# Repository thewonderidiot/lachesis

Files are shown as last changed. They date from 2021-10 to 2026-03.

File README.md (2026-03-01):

# Project Lachesis: AGC Core Rope Memory Readers

This repository contains all of the design files for safe, portable Block I and Block II Apollo Guidance Computer (AGC) core rope memory readers. For a detailed explanation of how it all works, check out [CuriousMarc's video featuring this project](https://www.youtube.com/watch?v=hckwxq8rnr0).

Block 2 reader being used to dump the rope modules flown on Skylab-2
*Block 2 reader being used to dump the rope modules flown on Skylab-2 at the New Mexico Museum of Space History*

## Rope Safety Considerations

The rope readers are designed to be electrically and mechanically exactly identical to real AGCs from the point of view of the rope modules. Exact mechanical dimensions and interfacing circuits were copied from the original AGC engineering drawings, obtained from the National Archives. During bringup, all circuits are calibrated to the [original procurement specifications](https://github.com/thewonderidiot/lachesis/tree/main/docs). Connections to the rope modules are made using [replica Malco Mini-Wasp pins generously provided by Samtec](https://www.youtube.com/watch?v=ThOXgcOOA1M).

Additionally:
* A hotswap controller is used to switch all power being applied to the rope module. This controller monitors for overvoltage, undervoltage, and overcurrent, and will automatically cut power to the rope if limits are violated. The enable for this hotswap controller must be actively held high by the microcontroller in the FPGA for rope power to remain enabled.
* The microcontroller is configured with ~95ms watchdog timer. If the software gets stuck, the resulting watchdog reset will take all outputs low, thus cutting power to the rope.
* 250mA fuses have been added to the 450mA power filter circuits. These fuses are capable of withstanding the nominal 1-to-5-microsecond-long 450mA current pulses. However, if a driver gets stuck on for any reason, the associated fuse will blow within approximately 1 second. Calculations by thermal engineer friends suggest that, conservatively, a sustained 450mA on one of the drive wires would only be damaging to the rope module after 30 seconds.

## Block I Rework

The Sense & Driver Board requires a small amount of rework when used in the Block I configuration. While designing the board, I focused on getting Block II correct, while trying not to do anything that would outright prevent Block I compatibility. The only thing I didn't account for in the design is that from the perspective of the sense amplifiers, current on the sense lines actually flows in opposite directions between Block I and Block II. For Block II, the sense amplifiers pull the sense lines up to 14V, and a 128mA current sink is connected to the module select pin. Block I does not yet have this pin; instead, the sense lines were pulled *down* to 3V. Lacking a 3V rail capable of sinking the necessary current, the 128mA module select driver forms a perfectly suitable substitute. This can be accomplished by depopulating F9 and C11, and running a wire from pin A32 of the main connector to the + pad of C11.


## Rope Modules Archived

This is a non-exhaustive list of the rope modules that have been successfully read using the rope readers. Redundant reads of the same software from different physical modules are not listed.

<table>
  <tr>
    <th>Program</th>
    <th width=15%>Rope Part No.</th>
    <th>Source</th>
    <th width="50%">Notes</th>
  </tr>
  <tr>
    <td rowspan="4">Sunrise 69<br/>(Block I System Test)</td>
    <td>1003133-18</td>
    <td rowspan="2">Anonymous collector</td>
    <td rowspan="4">The 1003733-021 and 1003733-071 modules dumped both have one strand with a single bad diode, requiring parity correction.</td>
  </tr>
  <tr>
    <!--Sunrise 69-->
    <td>1003133-19</td>
    <!--Anonymous Collector-->
    <!--notes-->
  </tr>
  <tr>
    <!--Sunrise 69-->
    <td>1003733-021</td>
    <td>Larry McGlynn</td>
    <!--notes-->
  </tr> 
  <tr>
    <!--Sunrise 69-->
    <td>1003733-071</td>
    <td>Anonymous Collector</td>
    <!--notes-->
  </tr>
  <tr>
    <td rowspan="6">Corona 261<br/>(AS-202)</td>
    <td>1003733-171</td>
    <td rowspan="6">Jimmie Loocke</td>
    <td rowspan="6">All six modules were flown on AS-202. These modules contained a variety of failed or failing diodes, requiring parity correction for several strands. Notably, strands 21 and 23 each had 2 bad diodes, requiring the affected bits to be manually teased out by capturing waveforms of the cores flipping in both directions utilizing a differential probe. Additionally, 1003733-221 contained a broken core, resulting in the total loss of 8 words. Fortunately, these words turned out to be identical to the Apollo 4/6 software, Solarium 55.</td>
  </tr>
  <tr>
    <!--Corona 261-->
    <td>1003733-191</td>
    <!--Jimmie Loocke-->
    <!--notes-->
  </tr>
  <tr>
    <!--Corona 261-->
    <td>1003733-211</td>
    <!--Jimmie Loocke-->
    <!--notes-->
  </tr>
  <tr>
    <!--Corona 261-->
    <td>1003733-221</td>
    <!--Jimmie Loocke-->
    <!--notes-->
  </tr>
  <tr>
    <!--Corona 261-->
    <td>1003733-231</td>
    <!--Jimmie Loocke-->
    <!--notes-->
  </tr>
  <tr>
    <!--Corona 261-->
    <td>1003733-241</td>
    <!--Jimmie Loocke-->
    <!--notes-->
  </tr>
  <tr>
    <td rowspan="5">Sunspot ?<br/>(Early Apollo 1 release)</td>
    <td>1003733-251</td>
    <td rowspan="5">Dr. Nick Gessler</td>
    <td rowspan="5">Unfortunately, all modules have many failed diodes, precluding easy software recovery. Work to correct resulting errors is ongoing.</td>
  </tr>
  <tr>
    <!--Sunspot-->
    <td>1003733-261</td>
    <!--Dr. Nick Gessler-->
    <!--notes-->
  </tr>
  <tr>
    <!--Sunspot-->
    <td>1003733-281</td>
    <!--Dr. Nick Gessler-->
    <!--notes-->
  </tr>
  <tr>
    <!--Sunspot-->
    <td>1003733-291</td>
    <!--Dr. Nick Gessler-->
    <!--notes-->
  </tr>
  <tr>
    <!--Sunspot-->
    <td>1003733-311</td>
    <!--Dr. Nick Gessler-->
    <!--notes-->
  </tr>
  <tr>
    <td rowspan="5">Solarium 55<br/>(Apollo 4 and 6)</td>
    <td>1003733-461</td>
    <td rowspan="5">Jimmie Loocke</td>
    <td rowspan="5">All five modules were flown on Apollo 4.</td>
  </tr>
  <tr>
    <!--Solarium 55-->
    <td>1003733-471</td>
    <!--Jimmie Loocke-->
    <!--notes-->
  </tr>
  <tr>
    <!--Solarium 55-->
    <td>1003733-481</td>
    <!--Jimmie Loocke-->
    <!--notes-->
  </tr>
  <tr>
    <!--Solarium 55-->
    <td>1003733-511</td>
    <!--Jimmie Loocke-->
    <!--notes-->
  </tr>
  <tr>
    <!--Solarium 55-->
    <td>1003733-521</td>
    <!--Jimmie Loocke-->
    <!--notes-->
  </tr>
  <tr>
    <td>Aurora 85<br/>(Initial LM System Test)</td>
    <td>2003053-071</td>
    <td>Anonymous Collector</td>
    <td>Module B2 from Aurora 85. While module B1 of Aurora 88 is equivalent to Aurora 85, module B3 is not, so Aurora 85 has not yet been fully recovered.</td>
  </tr>
  <tr>
    <td rowspan="3">Aurora 88<br/>(Final LM System Test)</td>
    <td>2003972-011</td>
    <td rowspan="3">Steve Jurvetson</td>
    <td rowspan="3">Rope modules were installed in the guidance pallet flown on the F-8 in the Digital Fly-By-Wire program. The whereabouts of the actual DFBW modules are unknown.</td>
  </tr>
  <tr>
    <!--Aurora 88-->
    <td>2003972-091</td>
    <!--Steve Jurvetson-->
    <!--notes-->
  </tr>
  <tr>
    <!--Aurora 88-->
    <td>2003972-111</td>
    <!--Steve Jurvetson-->
    <!--notes-->
  </tr>
  <tr>
    <td>Sundial B<br/>(Initial CM System Test)</td>
    <td>2003053-151</td>
    <td>Anonymous Collector</td>
    <td>Module B2 from Sundial B. While module B1 of Sundial B is equivalent to Sundial D, module B3 is not, so Sundial B has not yet been fully recovered.</td>
  </tr>
  <tr>
    <td rowspan="2">Colossus 237<br/>(Apollo 8)</td>
    <td>2003972-541</td>
    <td rowspan="2">Anonymous Collector</td>
    <td rowspan="2">2003972-541 is marked "SCRAP UNIT" in red, but read without errors.</td>
  </tr>
  <tr>
    <!--Colossus 237-->
    <td>2003972-571</td>
    <!--Anonymous Collector-->
    <!--notes-->
  </tr>
  <tr>
    <td>Luminary 69<br/>(Apollo 10 LM)</td>
    <td>2003972-751</td>
    <td>Anonymous Collector</td>
    <td>First rope module successfully dumped.</td>
  </tr>
  <tr>
    <td rowspan="6">Comanche 67<br/>(Apollo 12 CM)</td>
    <td>2003972-1081</td>
    <td rowspan="6">Anonymous Collector</td>
    <td rowspan="6">Modules B1 through B4 were part of the flight spare set for Apollo 12. The high serial numbers for modules B5 and B6 suggest they were manufactured after the flight, for unknown reasons.</td>
  </tr>
  <tr>
    <!--Comanche 67-->
    <td>2003972-1091</td>
    <!--Anonymous Collector-->
    <!--notes-->
  </tr>
  <tr>
    <!--Comanche 67-->
    <td>2003972-1111</td>
    <!--Anonymous Collector-->
    <!--notes-->
  </tr>
  <tr>
    <!--Comanche 67-->
    <td>2003972-1121</td>
    <!--Anonymous Collector-->
    <!--notes-->
  </tr>
  <tr>
    <!--Comanche 67-->
    <td>2003972-1131</td>
    <!--Anonymous Collector-->
    <!--notes-->
  </tr>
  <tr>
    <!--Comanche 67-->
    <td>2003972-1141</td>
    <!--Anonymous Collector-->
    <!--notes-->
  </tr>
  <tr>
    <td>Comanche 72<br/>(Initial Apollo 13 CM release)</td>
    <td>2010802-021</td>
    <td>Anonymous Collector</td>
    <td>Module was initially slated fly on Apollo 13, but a bugfix in response to the Apollo 12 lightning strike requiring a re-release resulted in it remaining grounded.</td>
  </tr>
  <tr>
    <td>LM131 rev 1<br/>(Final Apollo 13 LM release)</td>
    <td>2010802-121</td>
    <td>Anonymous Collector</td>
    <td>Flight spare module. This is the only module different between LM131 rev 1 and Luminary 131 (for which scans of a program listing are available), so recovery of the software from this module resulted in the complete recovery of LM131 rev 1.</td>
  </tr>
  <tr>
    <td rowspan="6">Skylark 48<br/>(Skylab and ASTP CM)</td>
    <td>2010802-541</td>
    <td rowspan="6">New Mexico Museum of Space History</td>
    <td rowspan="6">All six modules were flown on the Skylab-2 mission, and possibly reflown on a later mission. Made possible by Chris Orwoll and Larry McGlynn.</td>
  </tr>
  <tr>
    <!--Skylark 48-->
    <td>2010802-551</td>
    <!--New Mexico Museum of Space History-->
    <!--notes-->
  </tr>
  <tr>
    <!--Skylark 48-->
    <td>2010802-561</td>
    <!--New Mexico Museum of Space History-->
    <!--notes-->
  </tr>
  <tr>
    <!--Skylark 48-->
    <td>2010802-571</td>
    <!--New Mexico Museum of Space History-->
    <!--notes-->
  </tr>
  <tr>
    <!--Skylark 48-->
    <td>2010802-581</td>
    <!--New Mexico Museum of Space History-->
    <!--notes-->
  </tr>
  <tr>
    <!--Skylark 48-->
    <td>2010802-591</td>
    <!--New Mexico Museum of Space History-->
    <!--notes-->
  </tr>
</table>

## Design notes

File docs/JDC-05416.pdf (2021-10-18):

INSTALLATION AND REMOVAL OF FIXED MEMORY MODULES AND FIXED MEMORY JUMPER MODULES - BLOCK ll AND EM

JDC 05418 REV. -LMH io, _i
INITIAL TDftft 27956 | D.S. Pel J_
SUBSYST[M | Co | ter | ASSY.
DESCIIIIPTION

Inatallation and removal of fixed memory rope and Jumper modul .. ln the oomputer

Rev. | TORR | ~AGES REVISED | A~~VAL | REFtRENCES | -
Let. Dot, | NO. | JDC | D. S. | MIT | NASA
A 9...!l&-68 36862 | 1 | - | EAU~ - ,
IMPOflTANT | . ' - I '
See below.
INT[fNAL A• required

TOOLS ANO
MATflltlAL 0-25 Inch pound tonJi• wrench. 6/32 Allen adapter.
IMPORTANT | .. | a. Alternati• on th• Jacki• •crew• tipt-
en them with a torque wrench one turn ea•
Refer to JDC 18100 for lubrication tnBtruo- | until they are la &o 19 lncb-pounda.
Uona prior to engaging any acrew or bolt | - Into header hellcotl lnaerta, and for belt- | REMOVAL | . coil insert cleaning tnstructtona after all
testing ba• been completed or prtor to | 4. Remove module• uatng the torque wnnch
apacecraft ln8tallat1on. | fttted with a 6/32¹¹ Allen adapter. Altenat.
eada modllle Jacld• 8Cr9W ao that modlu1, Sa
INSTALLATION | withdrawn •traicbt from oomputer.
- | - | • 1
NOTE: Fixed memory mod- | - ule to be operative must be | '
. installed ln pain or ropee • | -·, | •• 1
If one module la to be Wied
then a Jumper module must | - be used. Refer to table | '

page 2.

t. lupect the connector of the module for | l bent or broken plna. | , ' | . | . . | .. i I. Refer to the diagram dll the aecond page

of thi• JDC. luert the module ln the
computer. | ·- ·- --
V(Re,ICATION Wint •DL ft!QUIMO l!flOM UK | DATE 12 A Pl j8
'·· | . .,, | ! f

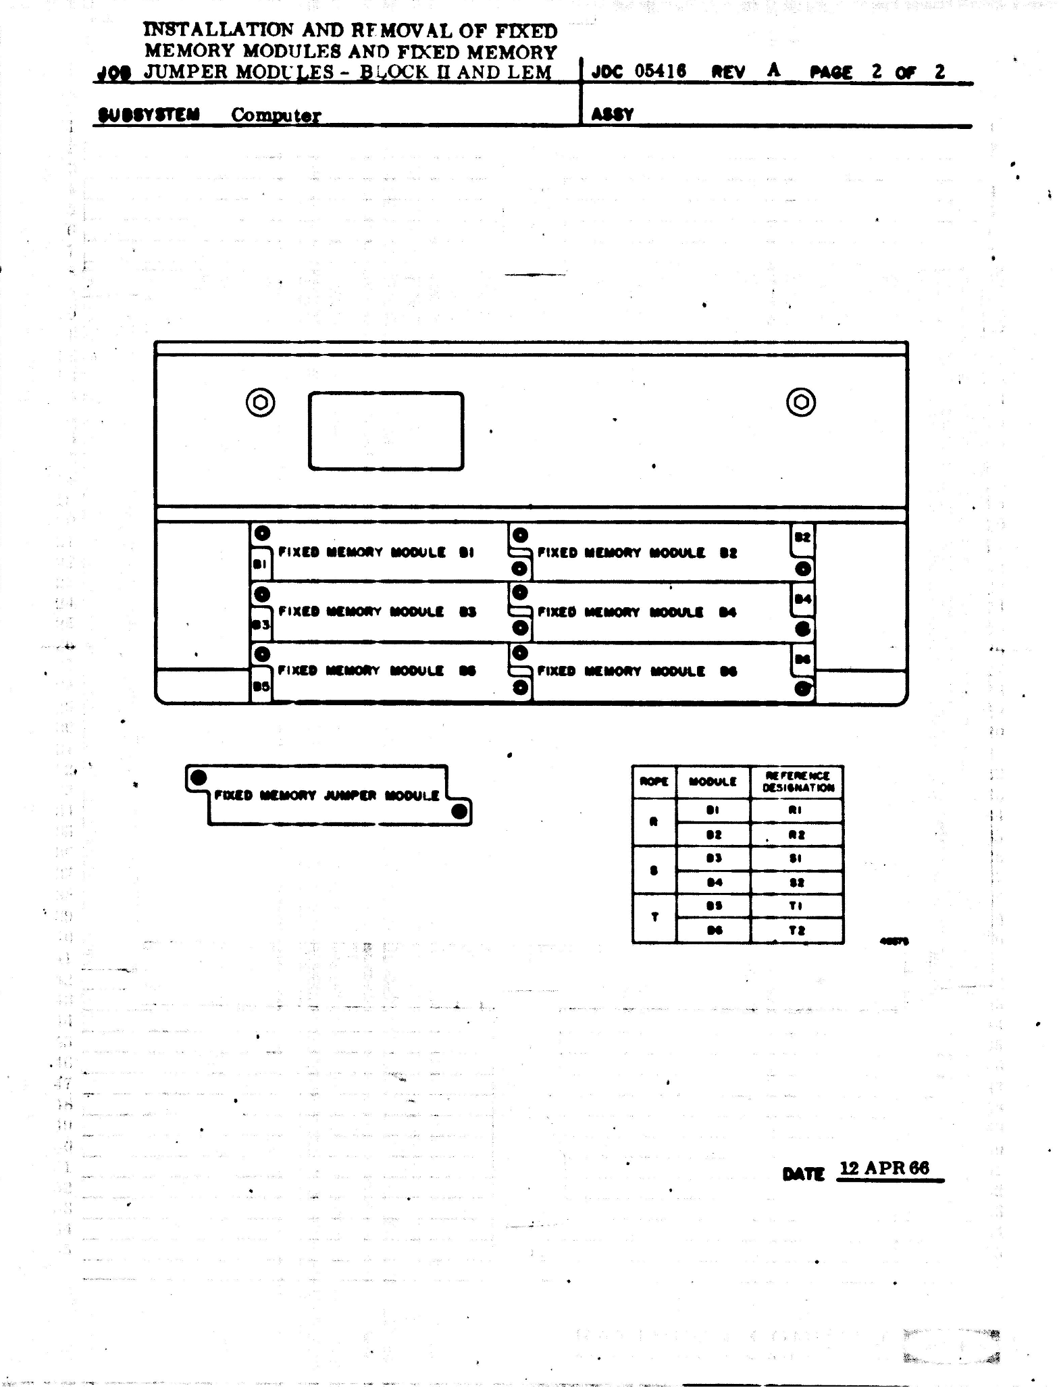
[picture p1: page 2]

- \
f

-· .....

INSTALLATION AND RFMOVAL OF FIXED
MEMORY MODULES ANO FIXED MEMORY
JUMPER MODt" | S - | ' OCK II AND L | JDC OMlt lt£V A | MM 2 o, 2
NYfflM | C,o | AMY
@ D | @

### 0 a

., ,11cU •1110R-,, _,LI II | II
- 0 | 1M ,,xn•_..._,._. .. ,... -IIIOII\' IIOOUL.I ..
•
- , ..... ...,~, -
IION | ltOOUl.l | M'IM'.IICI IIISIINATIOII
•• | •• • .. ••
H | II
- .. II
•• | Tl
' N | Tl

DlTI 12 APR 68

I:

! • '

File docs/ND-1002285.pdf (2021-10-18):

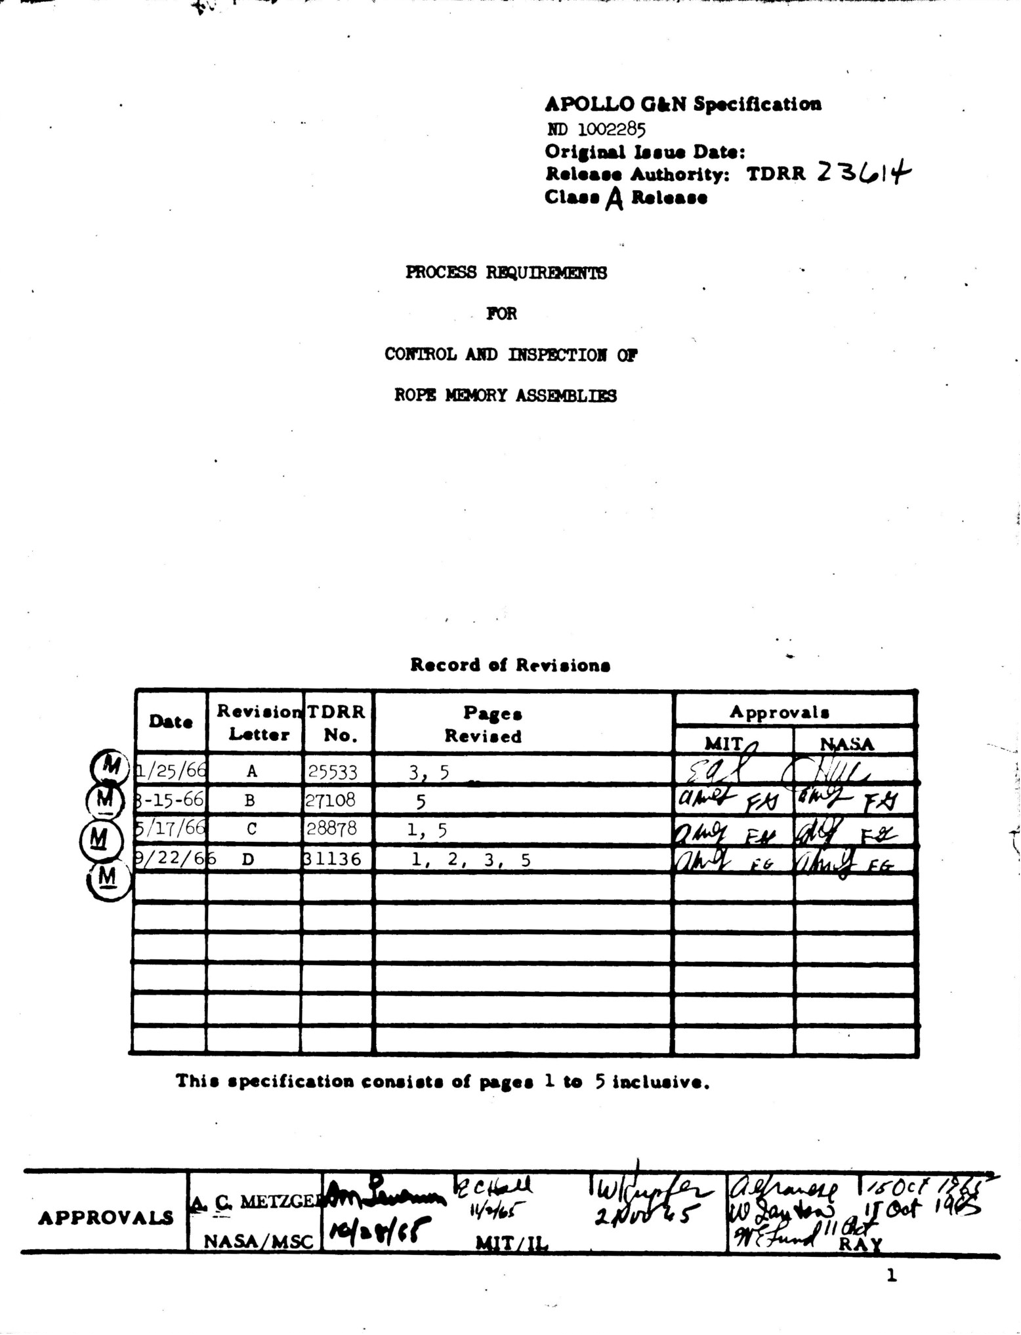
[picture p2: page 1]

M
M

Date Revieion TORR
| Letter | No.
0- /25/6E | A | 25533
l-15-66 | B | 27108
5/ 17/66 | C | 28878
9/22/6p | D | 31136

APOLLO O•N Specification
llD 1002285
Orl1iD&l Ja1ue Date:
JleleaH Authority: TDRR 2 '3 ~If, Clu• A a.leaH

PROCESS RIQumnmmJ

. 1'0R
COl'mOL AID INSPl!CTIO• OP

ROPE MEK>RY ASS»mLIBS

Record of Rt'YiliOIII

Pqee
Reviaed
3, 5
5
1, 5
1, 2, 3. 5

Approval•

MJTA | 9"1 .. '-' ..

### ·- ) (/,,,( I 'l,,1/JI J

a~~,AJ 11,,,...,,- ,,,..,_ i.H | ,:_,,ff
fJMf j::__u | ?ll,J' ~
171,.,J i .:r, | fik a. r"L

V

Thie epecificatioa conaiet• of PAI•• l to 5 lachaaive.

APPROVALS

C, MEI"LG~~_,_._,

NASA MSC
l

PROCBBS RIQUDINll'1B
Im

COll'fflOL OD IIS~<JI 0,

ROPB JCl!IIEY .ASSINBLD8

APOLU)
G • B BPIEIPICATI<II
11D 1002285
l .1 | Scope. Thie docuaent | tabli bea tbe proceH requirements tar
control and inspection in the fabrication ot rope W1"J' uHllbllee {Dwg 2003053) to be uaed · 1n the APOLLO Guidance Caaputer. t" .

l
2." | APPLICABLI DOCtJmll'l'S | 't | _I | r
.,
2.1 'l'be tolloving doc1aenta tam a part~ th1• epecitication to tbe extent specified. herein.

BASA •
2003053

### BCD 1006303

~Il'ICATIOIS

BASA •
BD 1002071.

BD 1002214

" t

~UllU!HEl'lB

Inaulating COllpOUDd, nectr1ca1,

### Quick Dl71na

Soldering, General
8pecitication tar preeenation and Packaging ot ~ Aaaembllea and Sub-Asaeabllea

3.1 UnleH otherwise specified, a preprodllCtion aupla eball aeet all the requirement• ot thia apec1t1cat1on.
3 .2 · · Soldering. Soldering ebal.l be 1n accordance vith BD 10ai!O'Tl except stripping ot the leads sball be by abruion and shall be l.1m1ted to tbe UH ot fiberglass. Stripped leads to be soldered. ehall be clean, and 2 to Ja. turne ot bare wire plua 3/4 to 11/2 tur:ne ot insulated v1re ahall be •ecu:rel.7 wrapped. In addition, a atreas release loop hall be tonled per J'1Cure l.

2

.:. ...

, .

,,,lie/IA# lt:AL
Tlllflt lNATION

APOLID
G • I ~IFICATIOII
ID ~85
3.3 | Wire Routing. Tbe following requil'ellenta shall applJ to wire routing
ot inhibit and sense wires.
3.3.1 t Crossing Core Openings. As little slack u possible shall be -intainecl without the inhibit vires or sense wires crossing any core openings.
3.3.2 Total Wires. The maximua number ot inhibit and sense wires including incorrect wires, shall not exceed that number which vould cause a mechanical interference thru the core openings i.e. blocking of the core opening which · vould prevent threading of any more wire tbru tbe core•.

3 .3 .3 Incorrect or Defect he Wire•. After threading, incorrect or defecthe wires shall not be reaoved. The cut or broken ends of incorrect or defective viree eball be coated with clear insulatina compound per SCD 1oo6303.

3 .3 .4 | Examination ot Wire. After the threading ot every •lxtMa·· {16.) 14N•, . .:;: ::. , the wires shall be exaained for the following.
3.3.4.l | Insulation. Insulation shall be intact, except at the solder Joints,
when examined wider lOX magnification. licks, cuts, or •cratcbes vbicb do not expose bare vire shall not be cause for rejection. 'l'be cut end.a ot incorrect or detective wirea shall be insulated per par 3.3.3.

3

(RBV A)

' I
I

AJIOI.U>
G • • SPEinCll'I<a
JfD l~285
3.4 | Bl.ectrical. The tollovinc electrical requirements shall apply.
3.4.l | Punctional Kl.ectrical Testa. l'unctional electrical teats shall be
performed at the completion ot the toll.ovin& ianuh.cturing operation■:
A. Inhibit vir1ng

### B. Sense virin&

C. Core bolder pottin&
D. nn&l assembly
| •• J'1nal potting
3.4.2 | Continuity. Oontinuit7 teeta ball be pertoraed at the ccmpletion or
aenee vi.ring and at the completion ot core bolder potting. Inhibit wire run■ ah.all exhibit 1.5 to 4.5 obu except for vi.re numbers 207, 211, 212, and 213 which shall exhibit 3 to 5.5 obu, and aense wire runs 3.5 to 12 ohma when measured vi.th an appropriate ohaeter or Robotester Model Ll 30303 or equival~t.

3.4.3 Insulation Resistance. Insulation resistance teats shall be pe~cmaed at the completion or aense wiring and at the completion of core hold~r potting. The insulation resistance between any one vi.re and all other viree shall be not leas than 10 megohms at 50 or 100 volta when aeasured vi.th a DI'Dl::0 610 or Robotester or equivalent.

4. QUALITY A88\JWlc• PROVISIOIS
4. l | Visual :llcaaination. Via\al exaaination ahall. be pertoraed on 1~ ot
production on the solderin& (par 3.2) and vi.re routing (par 3.3) requireaenta of thia apecif'icatioo.
4.2 | B>caminatioo Testing. 'lxu1oation te ting shall be conducted 011 100
percent ot production 011 the electrical requirement■ (par 3.4) of this specification.

PRm>ARATIOlf 10R DBLIVIRY
5.1 | Preservation• Packaging. The rope memory aod.ul.e aasembly shall be
preaerftd and packaged 1n accordance vi.th JfD 1002214.
6. 1'0TE8
| . , _,.
.. 6.1 | Intended U.e. The rope aaory aaaeablie ■ (2003053) • (2003972) are
intended for UM in- ~ | APOLLO euidanc• Coaputer.

(Rff ' D)

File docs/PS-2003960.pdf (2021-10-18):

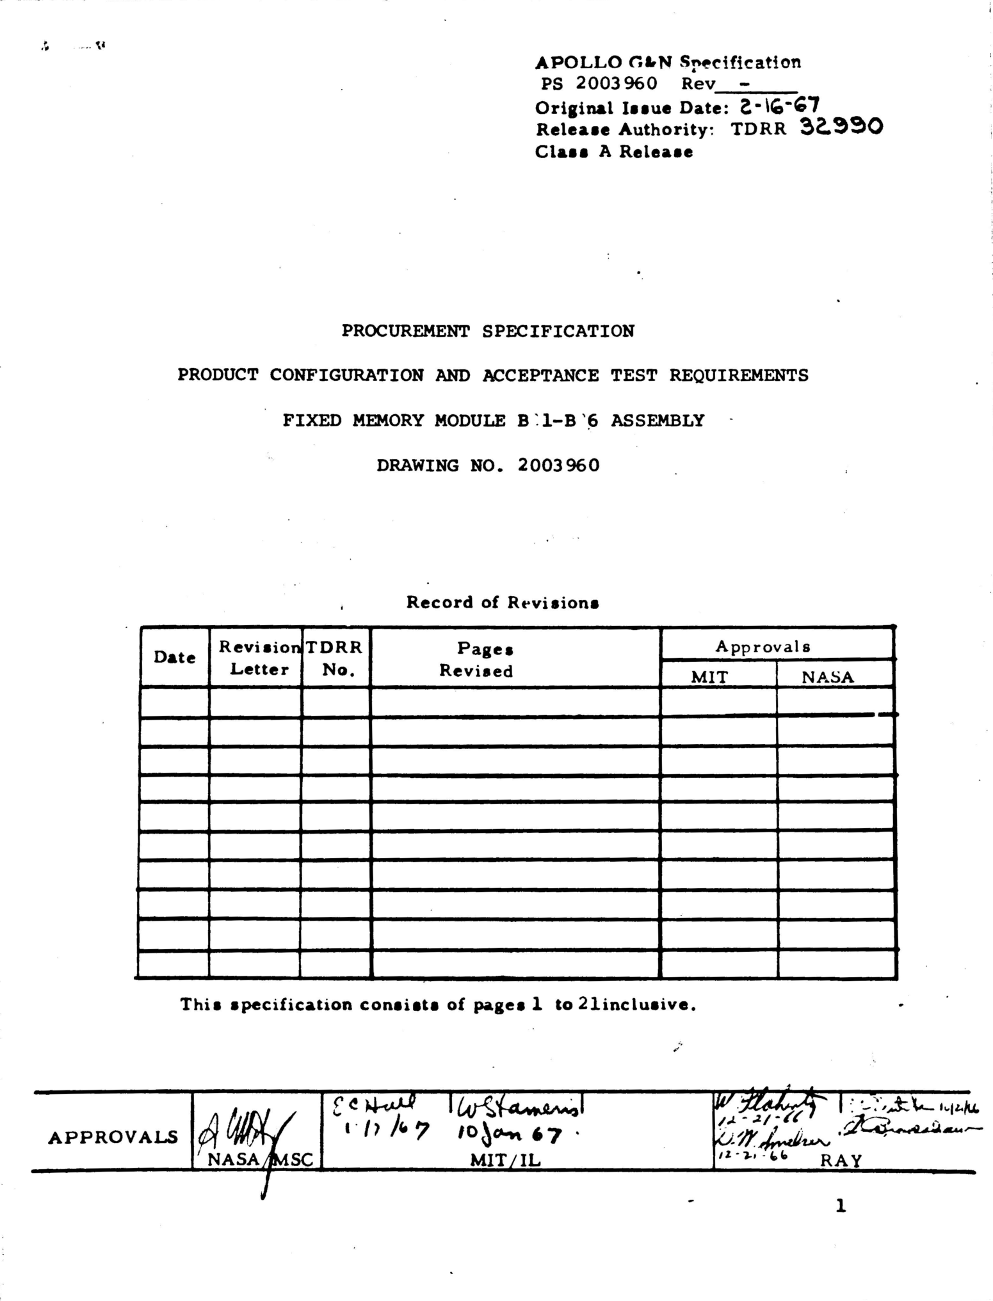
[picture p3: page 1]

•• . .. \I
APOLLO r.&.N S~cification
PS 2003 960 Rev __ -__
Ori1inal Iuue Date: t-1,-,1 ReleaH Authority: TORR 32.~~0 Cla•• A Releaee

PROCUREMENT SPECIFICATION

PRODUCT CONFIGURATION AND ACCEPTANCE TEST REQUIREMENTS

FIXED MEMORY MODULE B:1-B '~ ASSEMBLY

DRAWING NO. 2003960

Record of Rt-vieion•

Date Revieion TORR | Pagea | Approvals
Letter | No. | Reviaed | MIT | NA.SA

-►

Thia epecification conei1t• of ~gee l to 2linclueive.

APPROVALS 4

NASA

1

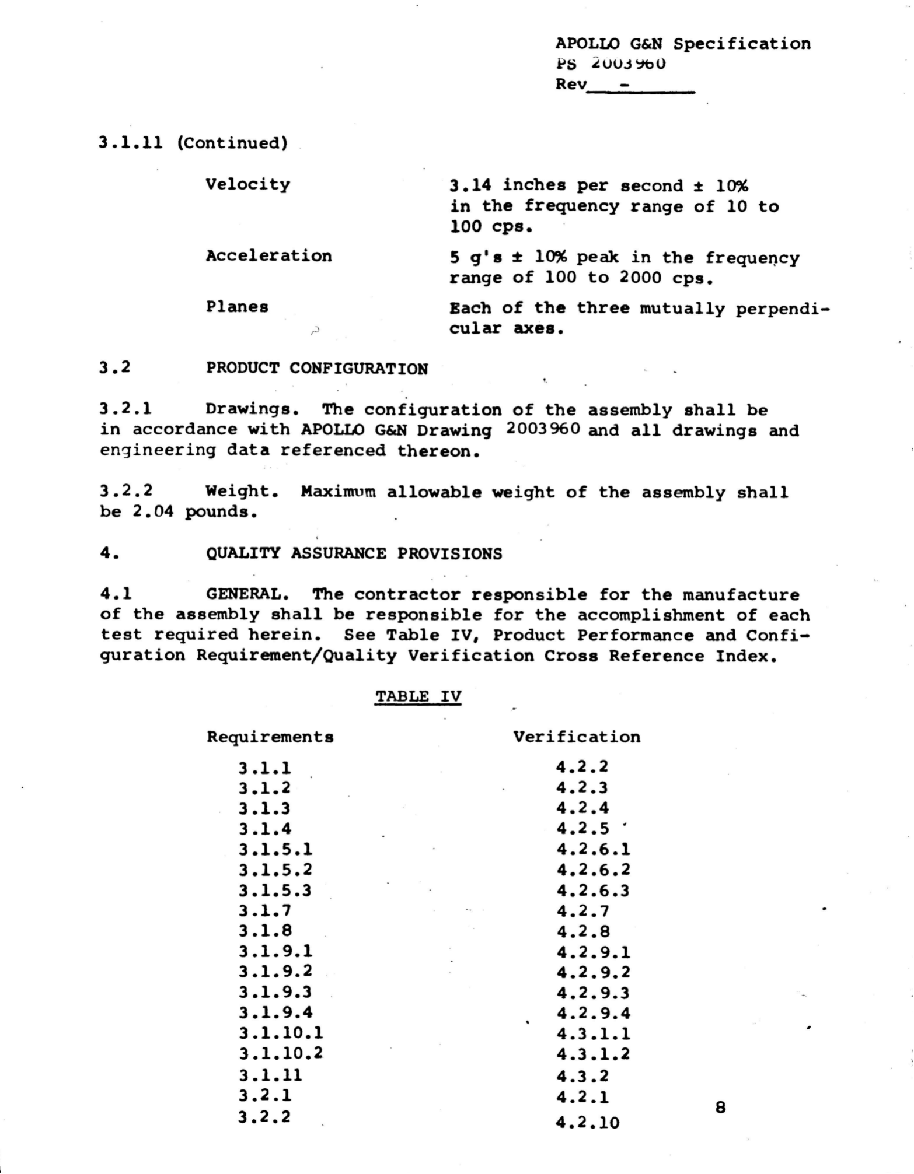
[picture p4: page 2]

3.1.11 (Continued)

Velocity

Acceleration

Planes
,:,
3.2 | PRODUCT CONFIGURATION

APOLLO G&N Specification
PS 2UUJ'::1t>U
Rev ____ _

3.14 inches per second± 10%
in the frequency range of 10 to 100 cps.
5 g's± 10% peak in the freque~cy range of 100 to 2000 cps.
Each of the three mutually perpendicular axes.

3.2.1 Drawings. The configuration of the assembly shall be in accordance with APOLLO G&N Drawing 2003960 and all drawings and engineering data referenced thereon.

3.2.2 Weight. Maximum allowable weight of the assembly shall be 2.04 pounds.

4. QUALITY ASSURANCE PROVISIONS
4.1 | GENERAL. The contractor responsible for the manufacture
of the assembly shall be responsible for the accomplishment of each test required herein. See Table IV, Product Performance and Configuration Requirement/Quality Verification cross Reference Index.

Requirements
3.1.1
3.1.2
3.1.3
3.1.4
3.1.5.l
3.1.5.2
3.1.5.3
3.1.7
3 .1.8
3 .1. 9.1
3.1.9.2
3.1.9.3
3.1.9.4
3.1.10.l
3.1.10.2
3 .1.11
3.2.1
3.2.2

TABLE IV

Verification
4.2.2
4.2.3
4.2.4
4.2.5
4.2.6.l
4.2.6.2
4.2.6.3
4.2.7
4.2.8
4.2.9.1
4.2.9.2
4.2.9.3
4.2.9.4
4.3.1.l
4.3.1.2
4.3 .2
4.2.1
4.2.10

8

APOLLO G&N Specification
PS ~003%0
Rev ____ _

4.2.9.2 Verify that zero noise value (v0 max) is as specified in paragraph 3.1.9.2.

4.2.9.3 | Verify that an all zero output is obtained when Logic
STAGAT is zero. | (v0 max• NMT 5 mv 1.1 to 2.3 usec after RESET).
4.2.9.4 | Verify that an all zero output ia obtained when Module·
Select current is removed. | (v0 max• NMT 5 mv 1.1 to 2.3 usec
after RESET (FR)).

4.2.10 Weight. Weigh the module to the nearest 0.01 pound. Verify that the weight does not exceed the .maximum allowable weight specified in paragraph 3.2.2.

4.3 | WORl<MANSHIP. The following tests shall be performed under
the conditions specified as a verification of good '11,'0rkmanship.
4.3.1 | Temperature Extremes.
4.3.1.l | With the ambient temperature as specified in para-
graph 3.1.10.1, repeat tests of paragraphs 4.2.8 and 4.2.9. Verify that the module performs as specified in paragraphs 3.1.8 and 3.1.9.
4.3.1.2 | With the ambient temperature as specified in para-
graph 3.1.10.2, repeat tests of paragraphs 4.2.8 and 4.2.9. | Verify
that the module perform■ aa specified in paragraphs 3.1.8 and 3.1.9.

4.3.2 Vibration. Subject the module to the vibration limits specified in paragraph 3.1.11, and verify that the module meets the continuity requirementa of paragraph 3.1.11.

s. PREPARATION FOR DELIVERY
5.1 | GENERAL. Preparation for delivery shall- be in accordance
with Specification ND 1002214.
6. NOTES. None.

16

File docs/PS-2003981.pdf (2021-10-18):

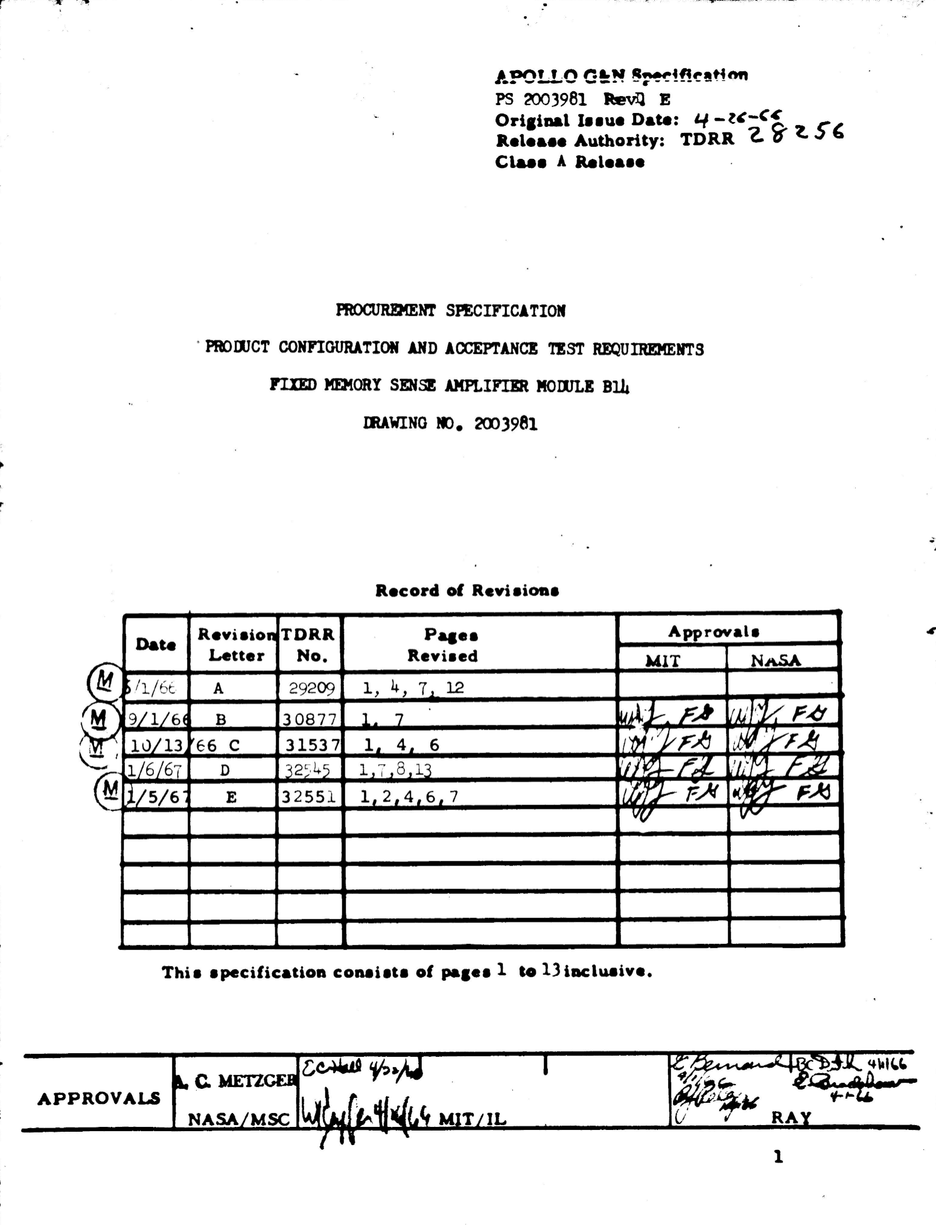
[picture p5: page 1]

Date
(Fi > l1/6t

~ 9/ l / 61
~ lu/13
1/6/67 @ 'i/5/6

APOLLO O!:!'-! ~~~fi~!tt'"'
PS 2003981 Revil E
Ori1iaal 181u• Date: 4.,# -u-c~ JleleaH Authority: TDRR -Z. i° t. S' Clue A Rele&H

PROCUREMENT SPECIFICATION

. PROWCT CONnOURATION AHO AOCEP'l'ANC!: TIST REQUIREMENTS

FIXED ~ORI SENS! AMPLIFIER MOilJLE Blb lllAWINO t«>. 200)961

Record of ReYi 1ioe1

Revi1io11 TDRR | Paa•• | Approval•
Letter | No. | Jtevi ■ ed | MlT | NASA
A | 29209 | 1 , 4, 7 , 12
B | 3 08 77 | 1 | 7 | 11 .J: l-- F,,. /Jj ·Y, F-c
66 C | 31537 | 1. 4. 6 | It,, JJ,,, F/2 j/1; . 7,,.lj
D | 32:,45 | 1,, , 8 ,B | !Ii ~ -r.:L ~· 'C 'i. VJ ... FL!
E | 3 2551 | 1. 2 .4.6. 7 | Ill, ~Ffi I~ ~ ~F~
11'(/ | V"'

Thi ■ 1pecification co111i1t1 of pa1•• 1 to 13iDCh11ive.

APPROVALS
MT IL
l

•

1. SOOPI

APOLLO G&N Specitication
PS ,O,'\Qftl
Re•

This apecitication tablishes the detail N~uiN11utnt■ for OOtlJ)lete identification and acceptance of the ftXN a.or, Senlle !llpllne't'Plbdule B.lb Part No. 2003981-0ll.

2 • APPLir..ABLI DOCUMENTS
The following doc,aent■ fol'II ■ pert of thia apeci.t'ication to the extent apecified herein.

2.1 ~Tm ISSUES. Unless otherwise specified heNin, Military and Oonn-aent Standards end 9J)ecificat1ona shall be the i ■ eue in ettect on the date o! requeat !or F'0p0Hl or invitation to bid.
SPm:InCATIClfS

## ucu.c GWf

MD 1002214

mA'WINOS
APOLLO O&H
2003981

Oener•l Specification tor PreaerTation, Packaging, Packing and Container Marking ot APOLLO Guidance and Nartgation Major Asaeabliea, Aaa•bliea, 3ubaaaeabliea, Pert• and Associated Ground Support Equiptent.

Find Meaory Sense hlplitier Module Blb

(Copies of Specification,, Standard•, l>!'ninga, Bulletins, and Publications required bJ auppliera in connection w1 th specific procunaent tunctiona should
be obtained frca the Procurinc Actint7 or H directed by the Contracting Officer).

2.2 OONFLICTING REQUIR»raNTS. In eT9nt of conflict betveen the require•nta · ot the contract, thia Specification and the docuaenta lilted in this section
the !olloving order of precedence ahall apply and the contractor 1hall notity llIT Apollo M,mag ... nt ot the conflict H soon 81 it i1 detenained.
| •• The contract
b. Thia Specification
c. Docuaenta lilted in thi1 Notion

2

Tbresbol.d YoltacH

u 1nr.r.n m," AN!ct1"1.e11tton
PS 2003981 - Re\' A C --------

3.1.5.1 Outputs. 'l'he output o'f each stage shall be measured as shovn 1n
n«un 1 when an input aa specified in section 4.1.5.1 is applied.

3.1.5.2 Threshol.d Voltage (Ait and Aq). 'l'breshol.d YOltage far each •ta&e •ball
be 35 ! 4.o av.

3.1.5.3 Gain Resolution. The gain resolution far -.ch stage sball be not mare than J., u.

Delay T1ae
3.1.6.1 strobe Irinll' Output (S'fflOBB, STROBF). The Strobe Driver output shall be u shown 1n Figure 21 and shall have the following cbaracteristica vheo an input u specified 1n section 4.1.5.2 is applieo..

Amplitude (high)
Amplitude (low)
Rise T1aa (tr)
T-2
Ton

llM'l' l.OY below B+

## a.o + o.~ belov :a+

llMI' bO nanoeec
70 ! 20 nanosec
NMT 0.75 usec
3.1.6.2 Sense Amplifier Outputs. 1!ach of the Sense Amplifier outputs shall be u shown in Figure 21 and shall have the following characteristics when an input u specified 1n section 4.1.5.2 is applied.

Amplitude (high)
Ampatude (low)
Rise Time (tr)
Fall T1ae (tr, t:r2)
T4
'?5, 'l6

1IMT 0.3-Y below B+
NLT 1.7V belov B+
1Df1' 100 nanoeec
1'MT 12' nanoeec
1-0 ! -0 nanosec
1Df1' 100 nanoeec

3.1.6.3 PIP (Q1) stage Output. Ba.ch PRP Stage Output sb&ll. be as shovn in 1'1gure 21 and shall have the folloving characteristics when an input aa specified 1D section 4.1.5.2 is applied.

Amplitude (high).
Amplitude (lov)
Rise TiDe (tr)
1-11 T1ae (tr)
'rf
T8

1.25 + 0.15\'

### NM1' o:iov

mfr 125 nanosec
:roo 400 nanosec
180 ! 60 oan0&ec
NMl' 1.3 usec

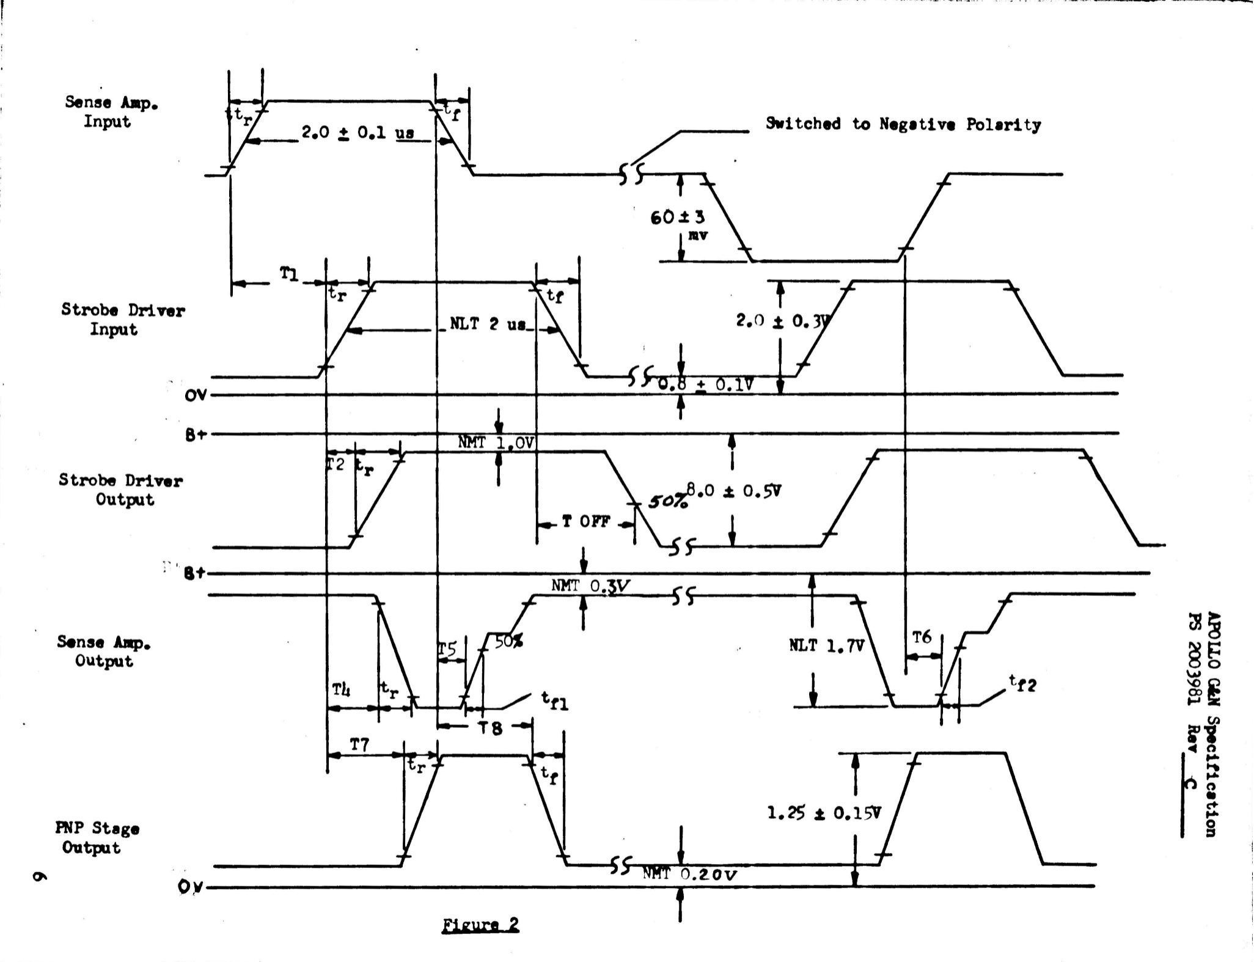
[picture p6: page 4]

Sense Aap.
Input

Strobe Dri.Yer
Input

Strobe Drinr
Output

Sense Amp.
Output

PNP Stage
Output

.... ' ·---·- ----

to Neg1tive Pol1rity

NLT ~ ua_

T7
17

### figure 2

APOLLO CU Spec1t1cat1oa
P6 2003o81 | Re• | P

Mar~1n&l Voltage• and Taperaturca llct.Nmea. 3.1.T.l With the input wltft8e adJuated to 12.2 ! o.1·voo, and an usbient temperature
ot -lcPC +oc<> , the module aball operate u specified in aect1ona 3.1.5 and 3.1.6, -2.Bc° | . except threshold TOltage •ball be 35 +7 av, and PIP and. S'ffiOBI output amplitude• M,¥

◄ decrease b7 2~. 1he anly tillea aeuured ah&ll be:

T2 | 70 +40
-20 na
l'° +8o
-40 na
180 +140
-60 D8
'1'5, ~ | ma 125 na
'l'6 | IIMl' 'l,...:12 5 '1 •
T OFF | NMT 0.45 µ.s 3.1.1.2 Vith the input Yllltage adjusted to 16.5 !. 0.l vrc, and an ambient temperature
ot -lOOC .+()CO | , the modi.I.le aball operate u specit'ied in aectiona 3.1.5 and 3.1.6, •

# -e.aco

except threshold TOltage aball be 35 +7 aY, and. fllP and S'ffl0BB output amplitud.ea-,
◄ | . | . incr-■- b7 ~. 'fbe onl)- times meaaured ab&ll be;
T-,2 | 70+40 | •
•20 D8

# ft l'° +80

~na
l&> +140
-60 DA
'5' ,'6 | JIMT 125 ns | T OFF | ,._ 0. 45 t8 | JMr 1.12s l18 . | &"oru. | µ•
3.l.T.3 V1tb the input TOltage adjusted. to 1.6.5 ! 0.l VDC, ancl an amb1e:it temperat.ure ot 700 42.BcO , \be aochale aball gperate u apecitied 1n NCti0118 3.1.5 and ).1.6, .oc_.o

~ept tbreabol4 90ltap •ball be 35 ~ 9v, and PIIP and S'm0BB output amplitude• ~
-T
lncree.ae b7 ~. !be Dill)- times MUun4 aball be:
Ta | TO +40
-20u
1~ +80

~ ... 180 +140

-60na
.'1'5, T6 | Ila 125 n•
'l'6 | Jiff 1.125 µ. ■
T OFF | NM'l' 0.45 µ. ■
).1.8 | Vibration. 'fbe module aball pertora u apec1t1ed 1n paragrapha 3.1.5.1
through 3.1.6.3 vhen inat&ll.ed. 1n an operating computer vhich 1■ being ubJected to the rlbratioo requirement■ specified 1D the applicable apeciticationa tor the computer aubayatem. Acceptance criteria tor the module aball be the cca;>Uance ot the computer aubayet• vitb ita applicable pecit1cat10C18.
3.2 . | PR0DU:T COID'IGURA.TIOK
3.2.1 | IRAWllm. 'l'he cont1gurat1oo ot the uaembly eball ~ in accordance vitb APOU,O
G&ll Dravin& 2003981 and. all dravinga and ~lneerin& data referenced thereon. | .
3.2.2 | Vei&ht. ot tbe aoclule •ball be recorded~· ·-- -- ··
- T

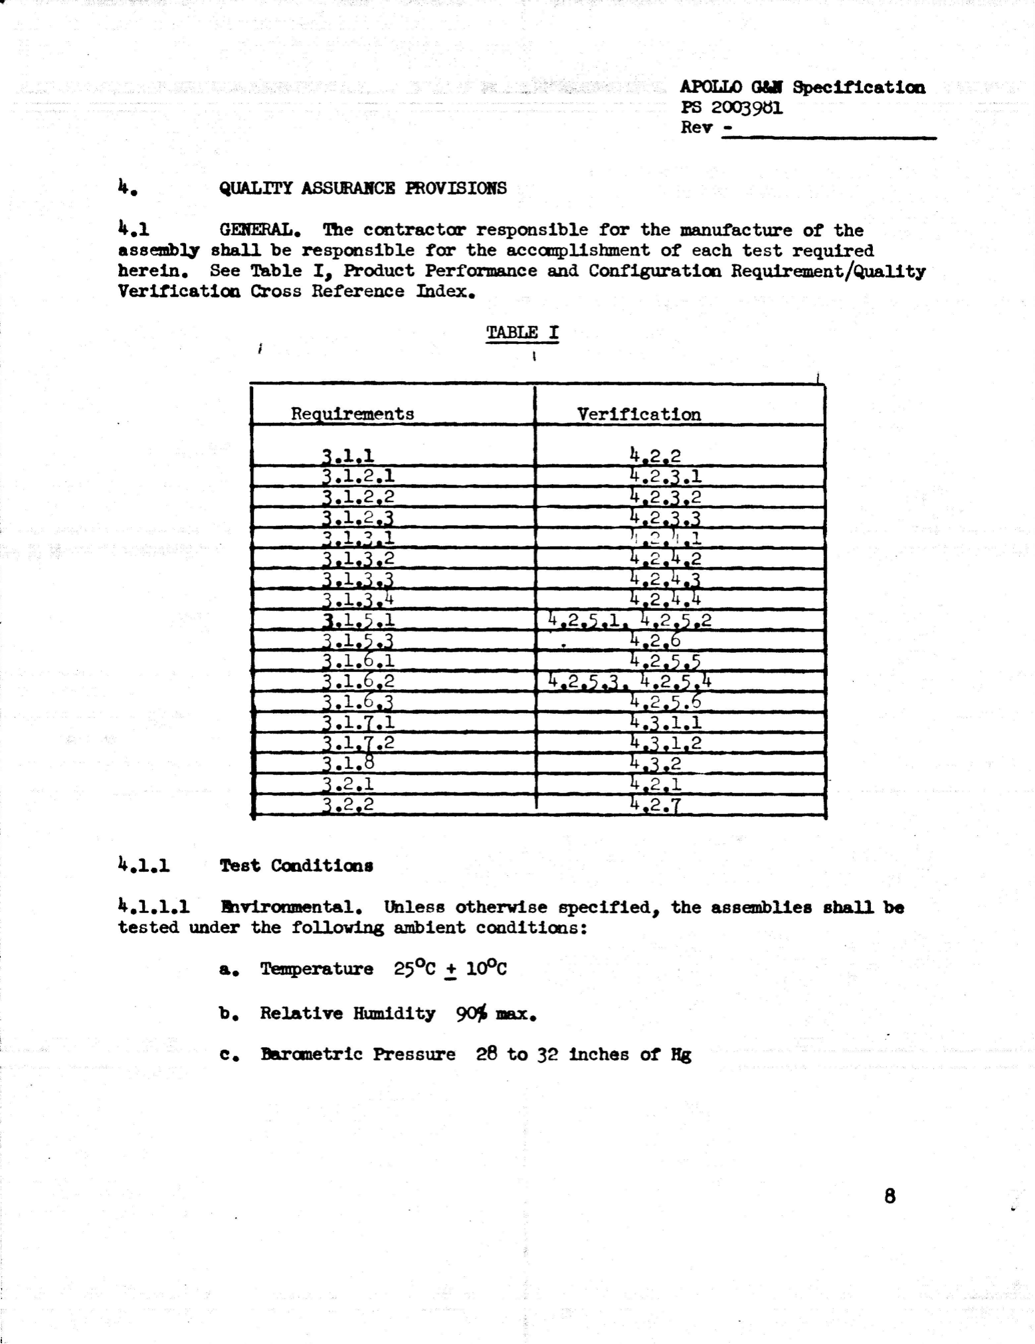
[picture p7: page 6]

-• | QUALITY ABSllWICE PROVISIONS

APOLLO OU Speclficatian
PS 2003~1
Rev -
~.l | GENERAL. The contractor responsible tor the manui"acture ot the
assembly shall be responsible tor the accaapllshment ot each test required herein. See Table I, Product Performance and Configuration Requirement/Quality Ver1ticati011 Cross Reference Index.
TABLE I

I
Reauirements | | Verification
3.1.1 | | 4.2.2
3.1.2.l | | 4.2.3.l
3.1.2.2 | | 4.2 .1.2
-:i.1.2.1 | | 4.2.,.,
3.L-:, .1 | | 'i.2. ¹
| | 1.1
3 .1.3 .2 | | 4.2.4.2
.l. 'L 1 | | 4.2.4.1
.1.1.4 | | 4.2.4.4
~.l. 5.1 | 4.2.5.l. 4 0 2.5.2
.1.5., | . | 4.2.6
- 1.6.1 | | 4.2.5.5
.1.6.2 | 4.2.5.,. 4.2.'1.4
.1.6.1 | | 4.2.5.6
.1 • • 1 | | 4.,.1.1
.1.· 7 .2 | | 4., .1.2
.1. ::l | | 4.,.2
3.2.1 | | 4. 2. l
3.2.2 | | 4.2.7

Teet Canditiona

~.1.1.1 l!brtronmental. Unless otherwise specified, the assemblies shall be tested under the follov1ng ambient conditions:
a. Temperature 25°c .! lD°C
b. Relative Humidity ~ -.x.
c. BarCllletric Pressure 28 to 32 inches or Hg

8

:.:PG~~ ~lrl~L.luu
PS 2003981
Rev -

---------- 4.2.3.3 Measure the resistance between pin 269 (chassis ground) and the

chassis, and verify that it is as specified in paragraph 3.1.2.3.

~.2.4 Insulation Resistance Tests. Using a resistance bridge or equivalent vith a test potential o:f 50 VDC Umited to a short circuit current of 50 aicroamperes, perform the following:
4.2.4.1 Measure the resistance between any one pin Band all other pin B's, and any one pin E and all other pin E's, and verify that they are specified in paragraph 3.1.3.1.
4.2.4.2 Me~sure the resistance between ee.ch pin Band all pins o, H, I, J, and pins 126, 128, 103, 229, 234, and 268. Verity that they are as specified in paragraph 3.1.3.2.

4.2.4.3 Measure the resist~ce between each pin :I and all pins G, H, I, J, and pins 126, 128, 103,229,234, and 268. Verify that they are as specified in paragraph
3.1.3.3.

4.2.4.4 Measure the resistance between pin 269 and all other pins on the IIOdule, and verify that they are u specified 1n paragraph 3.1.3.4.

| Functional Testa

4.2.5.1 With the input signal of paragraph 4.1.5.1 applied to pins A IC of each stage, 1111d the output (pin G) loaded vith the circuit shown in paragraph 4.1.4, measure the output at pin G and verify that it is in accordance vith paragraphs
J.l.5.1 and 3.1.5.2.

4.2.5.2 With the input signa1 of paragraph 4.1.5.l applied to Pins D • P of each stage, measure the output at pin J and verity that it is in accordance vith ll paragrapha 3.1.5.l and 3.1.5.2.

4.2.5.3 With the input s1gna1 of paragraph 4.1.5.2.1 applied to pins A• Cot each stage, and the output (pin G) loaded with the circuit shown in paragraph 4.1.4, measure the output at pin G and verify that it is 1n accordance with
paragraph 3.1.6.2.

4.2.5.4 With the input s1gna1 ot paragraph 4.1.5.2.1 applied to pins D •Pot each stage, measure the output at pin J and Yerify that it is in accordance with
paragraph 3.1.6.2.

4.2.5.5 With the input signal of paragraph 4.1.5.2.2 applied to pin 268, aeasure the output at pin 126 and verify that it is in accordance vitb para&raph 3.1.6.1

| 12

AP0rUJ GU 8peclt1oat.1CIII

### PB 2003981 RaT l)

4.2.5.5 V1.th the 1np .. t a!e,;,;;..l ot par--.:-i)h ~.l.~.~.l ~;.1!=4 to pins 1 I C a::d.1' l P ot eacb 8ta&•, and pin I load.eel with a 1000 oba ! 5~ rel1.tor1 ... ure tbe outpR at pin I &D4 ftri.1'7 tbat 1t 1a 1a aocordanoe with pancraph 3.1.e>.3.
,.2.6 Oa1n Reaolutlan. U.1.nc the tbl.low1q f'mwlla, aalculate the pin re80lllt10D tor eub •tace, and ftl'ifJ '-t. tbeJ an 1a aocardanoe witaa ~ 3.1.5.3.

!m,'!l IN ,ara&rapla ,.1.,.l far 4ef'1nit10M of -,.bola

CIAIII D80W'l'Im • AX • ~
•AQ•Aq
,.2.T Veilbt. V.igb tbl aodul.e to tbe aearen .Ol poun4. Verity that tbe wlc" doea DOt uceecl the •rl•• &Jlowb:i. wi&ht. apeo1t1ed 1D :p&ner&pb 3.2.2.

-■ 3 vauDI\JIBHIP. '1'be follovt.nc te.te •ball M pwetolw4 under tbe OCD41t1ou 1peolt'1e4 u a nrUioatlan ot aood vorkeen•bip.

,.~.1.1 vttb t.be t.a,,ut YOltaa. an4 ubient t1cearature u ai,ec,it1e4 1a
paragraph 3.1. 1 .l, repeat. telte -.2.5.1 tbroup 4.2.6. Yerlf1 tbat tbe aodnl.e pctww. u apeo1t1e4 1n ~ 3.1.1.1.

IIO'ml The aodul.e abal.l be aintained at tbe apeo1t1e4 taper&ture tor ~ l.eN thM 30 alnutee prior to it.art ot teete.

-.3.1.2 Vltb tbe input TOltage and ambient temperature u 1pecit1e4 in paragrapb 3.1.1.1, repeat teet.e 4.2.5.1 thre>u&b 4.2.6. Verit'J that the aodul.e per1°0l"U u specit1e4 1D
~,. 3.1.1.2.

JIO'm1 !tie aodule eball be maintained at the apec1t1ed tapefttUN ta, not. lAaa than 30 llin\ltel prior to etart ot teat.a.

-.3.1.3 Vi~ tM input wltap and ubient te.perature u apeo1t1e4 1D paragrapb 3.1.1 .)1 repeat teeta -.2.5.l tbrou&h 4.2.6. Ver1.f'7 tbat tbe aodul.e pertol-w u epeoit'led 1D .
paracraph 3.1.1 ~- ,, | .

IIO'ms '1'1111 aocl11le 'lllall. be -.JntaiMd at the apeclt1e4 t•~tve for . tin l.N• tbaD ~ ~ prior to et.art ot teete.
,.3.2 •1brat1011. Ina1iall tbe aodule 1n • applicable ec:aputer. 8abJeot tbe
eaaput.r aut>ayet.a to tbe ri.bratiGD teete epecitied 1D toe applicable JDC. Verity that toe ocaputer aibqnea ... ta tbe nq"1.NMAte ot tile app~le apeo1t1oat10G.
S • | JIUPAMTIOII Jm JIILIVDY
"':t. ammw.. Pnparat.iCIII tOlt 4ellftl'7 8ba1l ~ la MOOl"MQH witll 8peo11'1oat.1an
Gl<>am.4. . | .
'• | IO'lWh JloDe, -i-

lJ

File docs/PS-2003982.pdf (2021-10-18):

# PS p) 39 2 Re•. : •

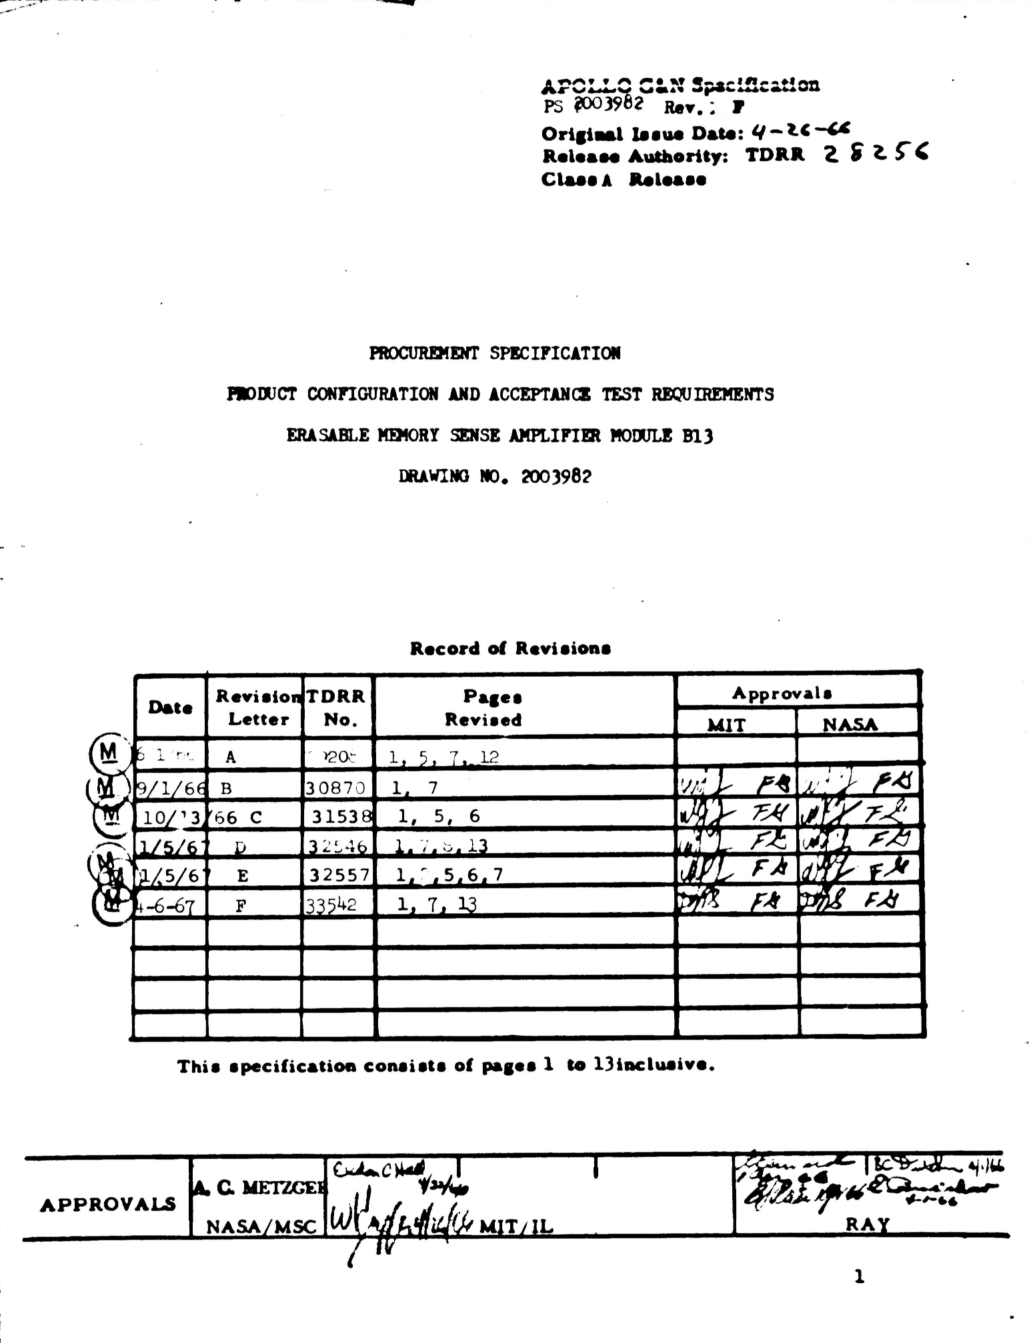
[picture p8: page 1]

o.,.

i t: l r·•-

,. 19/1/6€
l.9L, 3
,__ 1/5/6
~i' ":.1/5/6
Q~ it-6-67 -
- A_,,_.,",._ ..... ,. •patfft,.~ ♦•-

Al'V ...... ~ ----•• e4' ... ~.._.WM
Onstaat la•ue Date: q-t.C~ lleleaN Authority: TDllR 2 i ~ ~ ( Clu•A a.lea••

PROCUREMENT SPICIFICATION

Pll>llJCT CONl'IGURATION AND ACCEPTAHCZ TEST ~IREMENTS

ERASABLE M!X>RY SENSE AJIIPLIYID PIOOOL! Bll

IllAWilll i.>. 2003961

llocord of Reri•ione

Re•i•io11 TDRR | Paae1 | Approval a
Letter | No. | Re•iaed | MIT | NASA
A | , l20:: | 1. 5 7 . 12
B | 30870 | 1. 7 | '/J,/

## --- P-'1 ,1;••J ~,<:J

66 C | 31538 | 1, 5, 6 | .J L ~u -~ ry 7,..!: ,, | r~ 'l. ,,:-~ D | 3 :.'.~A6 | l. 'i. ~ .13 | ". | ,.,11
E | 32557 | l.~.5.6.7 | 1A r _/ | FA dt ~;..., F~
F | 13542 | 1. 7. 1.1 | t,;r.! F~ ~ ii F-4

Thi• apecificatioa conaiat1 of pa1•• l to l)iDCha•i•••

APPROVALS

## C. METlCE ~C.Wf~

NASA MSC w

l

l. SCOPI

AFOU.O GltN Specification PS ,00398~

Rn. -

Thia 1pee1fic1tion establiahes the detail requirments for coaplete identification and acceptance ot the lra1able_ Maor, S.nae Aapli!ier Jilodal.,e Bll

Part No. 200)982-011.

f • APPLIClBLI OOCUMINTS The following docnaent1 fol'll a pert ot thi1 1pecific1tion to the

extent specified herein.
?.l EP'PECTM ISSUES. Unle11 otherv1H specified herein, Plilita?'1 and Oovenaent Standard• and IJ)ecitic1tiana hall be the i1ne in 1t~1ct on the date ol reque1t tor propoeal or invitation to bid.
SPECIFICATIONS
| AFOLW O&Jf
| ND 1002214

mAWINGS

APOLLO G&rN
2003982

General Specification tor PreserTation, Packaging, Packing and Container Msrking ot APOILO Guidance and Navigation Ma .1 or Asseablies, Ass-.vlies, Subasse111bli es, Parts and Associated Ground Support Equipaent.

lneable Mlaor, s.n ... .Ailpli?ier Jlodaa 113

(Copiea ot Specifications, Standards, Drnings, Bulletin■ and Pnblications required by suppliers in connection with specitic procureaent functions 1hould
be obt~inld frc:a the Procurina Actirtt7 or a1 directed bJ the Contractin& Officer). 2.2 CONFLICTING REQUIREMENTS. In the ennt of conflict bet1fffn the requirellents of the contract, this Specification Ind the doCUJ1ent a listed in
this section the following order ot precedence 1h1ll apply ind the contractor ahall notify MIT Apollo Manag-nt ot the conflict H aoon Hit 1a deterained.
| •• The contract
b. This Specification
c. DocUJ1e11t1 liated in thia Hetion

APOLU) G&ll Spec1t1catioa. T'W"' ,-,~no,., ... ..., ... ...,\JJ;jj~ Rev._. ________ _

3. R~UIREMEN'l'S
3.1 | PFJUi'ORMANCB
3.1.1 | Thennal. Conditioning. The module shall be subjected to two complete
thenial cyclea, as specified below prior to acceptance testing:

25°c down to -1o<>c + 3cO in BLT 20 Jdnutes, held at -1o<>c + 3,:fT tor BLT 30 minutes, raised to 700c-+ 3cO in NLT 40 minutes, held at 700c + 3cO tor NLT 30 minutes, lowered to 25°c in BLT 20 Jlinutes.

Continuity

3.1.2.1 'lbe resistance measured f"r<a each pin A to the corresponding Pin B, and frca each pin D to the corresponding pin E, shall be 1350 .:!: 68 ohms.

3.1.2.2 The resistance measured frail pin 139 to each ot the following pins shall not be more than 0.5 ohm.

Pin Numbers
146 117
153 124
159 | 235
103 | lll
3.1.2.3 | The resistance measured between chassis ground (pin 269) and the
chassis shall be not more than 0.5 ohm.

Insulation Resistance

3.1.3.1 There shall be not less than 100 megohms resistance between any one pin Band all other pin B's, and between any one pin Band all other pin B's.

3.1.3.2 There ahall be not leas than 100 megohms resistance between each pin B and all pina O, H, I, J, and pins 1.26, 128, 1031 229, 234, and 268.

3.1.3.3 'lbere shall be not less than 100 megohms resistance between each pin B and all pins G, H, I, J 1 and pins 126, 128, 1031 2291 234, and 268.
3.1.3.4 The resistance between chassis ground (pin 269} and all other pins coonected tosether shall be 100 megoias lllinimua.
3.1.4 Input Voltage. 'lbe assembly shall tunctioo u specified herein vhen supplied with 14.o ! 0.1 VDC to pin 128, and O VDC to pins of section 3.1.2.2.

3

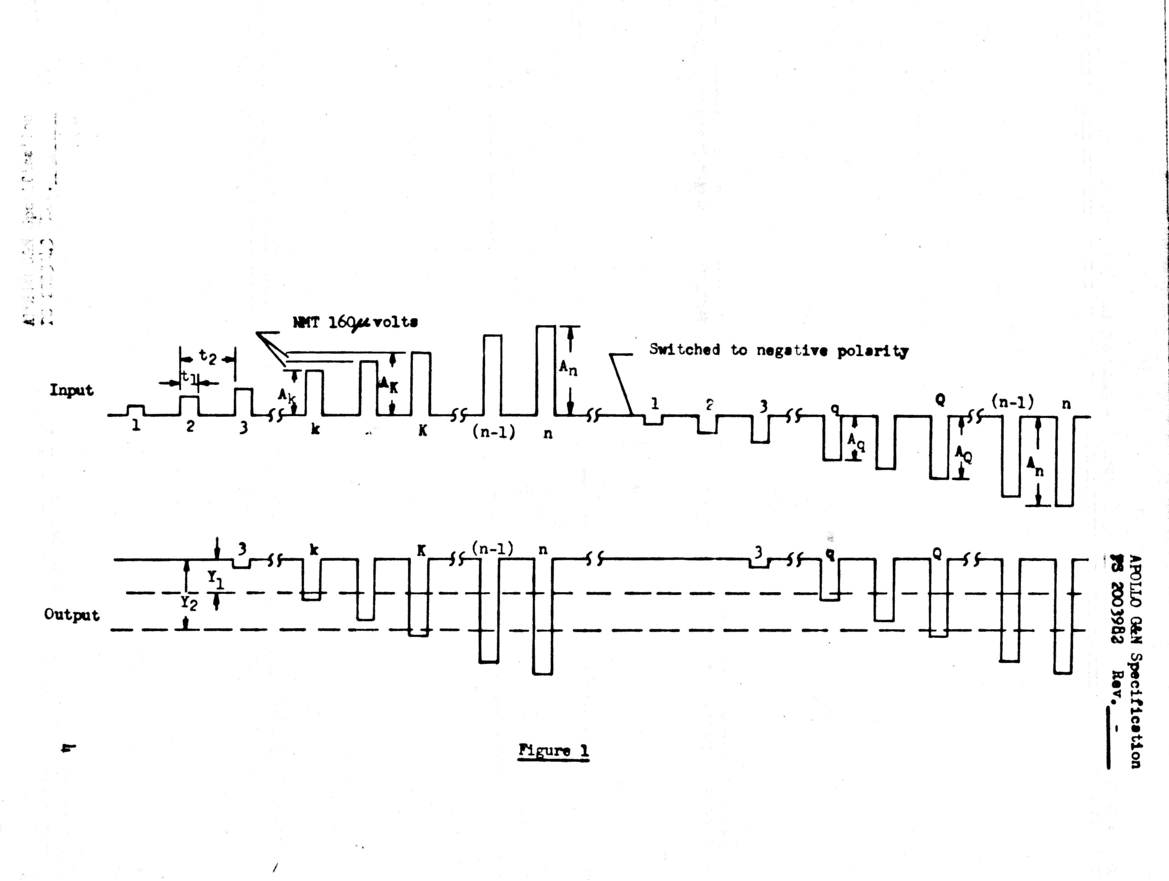
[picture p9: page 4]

t - ·

, ' ' . - !

- f.

Input

### JltT 16<}c,& Yol ta

1;1 '\ I

~A

___ l ..... Cr,

# --'-;L - - Y2 T Output __ _L __ _

I

T | Switched to nega t1•• polarit,

K n

n s .... -----2.r--i

P'igure 1

APOLLO G&ll Specification
PS 2ooa~ Rev• A=--C __________ _

Threshold Voltage
3.1.5.1 Outputs. The output of each stage shall be measured as shown in Figure l vhen 1111 input aa specified. in section 4.1.5.1 is appUed..
3.1.5.2 Threshold Voltage (Ag and Aq). 'lbn•hol4 voltage for each stage shall be 18 ! 4.o av.

3.1.5.3 Gain Resolution. The gain resolution tar each stage shall be not
aortt than ] .5 IIY •
3.1.6 Delay T1ae
3.1.6.1 Strobe Driver output (S'fflOBE, S'ffiOBII'). The Strobe Dr-iver output shall be as shown 1n Figure 2 1 and shall have the following ch&racteristics when an input aa specified in section 4.1.5.2 is applied.
| AmpLitude (high) Amplitude (low) Rise Time (tr) T2 Ton

NMT l.OV below B+
8.o + 0.5v below B+
NMT bO nanosec
70 ! 20 nanosec
NM'l' 0.75 usec
3.1.6.2 Sense Amplifier OUtputs. Each of the Sense Amplifier outputs shall be as shovn in Figure 2, and &hall have the following ch&racteristics when u input as specified in sectioo 4.1.5.2 is applied.
| Amplitude (high) Amplitude (low) Rise Time (tr) Fall Time hn, t12) T4

~,%

llMT 0.3Y below B+
NLT l.7V below B+
NMr 100 nanos ec
NMT 125 nanosec
14o ! Ito nanosec
KMT 100 nanosec

3.1.6.3 PHP (Ql) Stage Output. :Each PIP Staf5e Output shall be as sbovn in Figure 21 and shall have the following characteristics when an input as specified in section 4.1.5.2 is applied.

| Amplitude (high) Amplitude (low) Rise Time (tr) Fall Time (tr) T-r Ta

1.25 + 0.15v

## rorr o:2ov

NHl 125 nanosec
.rorr 400 nanosec
180 ! 6o nanosec
KMT 1.3 usec

5

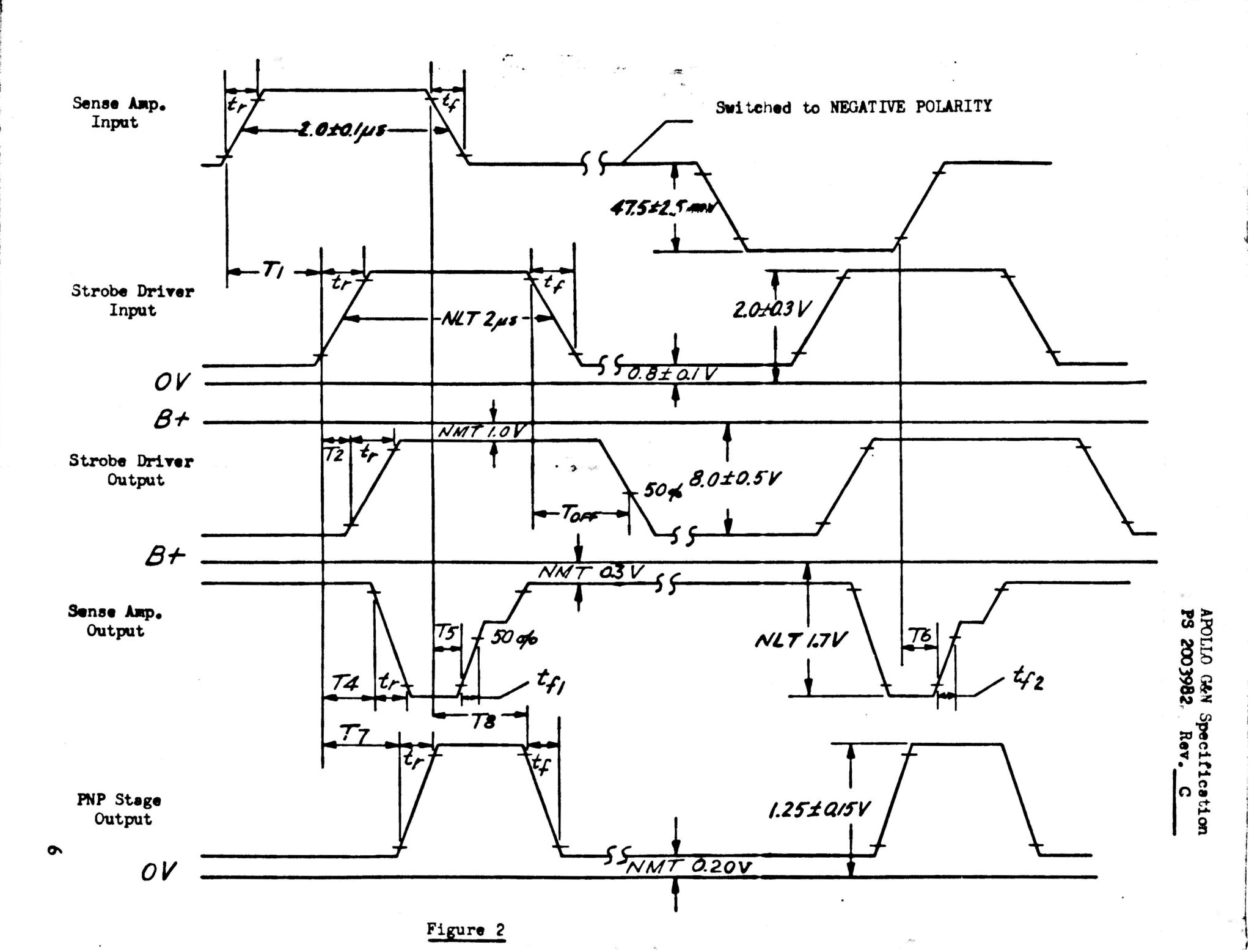
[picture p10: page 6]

c,,.

Sense Aap.
Input

Strobe Dri•er
Input

Switched to NEGATIVE POLARITY

OV----+---+---+---~--=-;=---~-----1--------8+-----1~---+~-+~~-----~------r---------

Strobe DriYer
Output

8+-

Sense Aap.
Output

PNP Stage
Output
ov

Ntr1.1v
r4 | + | trz

Figure 2

.,, )I,
CA~

~s
i~
~.c
en ~1
- C,
◄ .....

~

.... 0~ | ' c+ | ' I .....
s I
I
I

.l
I

•; | APOLLO G&lf Spec1t1cat1oa
PS 2003982 | Rev | 7
111.rginal Voltage and 'l'ellperature Blctrellea. 3.1.7.1 With the input YOltage adJuated to 12.2 ,t 0.1 VDC, and an ambient tempera• ture ot -1oOc +-0<!' , the aodul.e aball operate ■ apecitied 1n paraulipb• 3.1.5 and
4.8C°
3.1.6, except threshold YOltage aball. be 18 +T aY, aa4 PIIP and 8'l'ROBB outpu.t -.pU•
◄ | . tu.dee~ decreue by~. !he only ti.ea aeaaured. ball be:
1 | ~ | 70 +40

ft
fl

•20u
11Jo +80
-40u
180 +140
-60 ■
T5, if6 | 11ft' 125 na | T OP'l' Nlrl' 0.45 µa T' '1'8 | IDfl' l.l2S µa

•

3.1.1.2 With the input wltage adjusted to 16.5 + 0.1 YDC, and an aabient tempera• ture ot -la°C ,+<)CO , tbe aoclul..e ahall operate u specified 1n paragraph• 3.1.5 and 4.8c°
3.1.6, except tbreahold wltaae ball be 18 +T aY, aod PKP aa4 S'l'ROBB output am.pU• ◄ tud.H M.7 increue by ~. 'l'be only time■ .-..ured •ball be:
1'2 | 10 +40
-20 u 1a.o +8Q | #

Ou 180 +140
-60 ■
'5, '6 | JIM! 125 n• . 'l'6 . | RM'? l.).2S 1,1.a
If OFP NMT 0.45 µ:e

3.1.7.3 With the input TOltage ad.Justed to 1.6.5 + 0.1 VDC, and an aab1ent tempera•
. tun ot 7C1'C +2.8c°, the module aball. operate u ."apec1t1ed 1n paraua~hl 3.1.5 and ~

3.1.6, except tbreabold wltage •ball be 18 ~ aY, and P!IP aa4 STROBE output upU• • -1
tude• M7 increue by ~. '!he only tiaea M& ured •ball be:
| 'f2 | 70 +40
| | -20118 1a.o +80
| | -40 u 160 +140
| | -60 na
| '5, T6 | 1li!'1' 125 na
. | '1'6 | 6M'? 1.125: IJ.8
T OFF | NMT 0.45 1,1.a
3.1.8 | Yibration. 'l'he module •ball pert'Ol"II u specif'ied 1n pan.graph■ 3.1.5.1
through 3.1.6.3 when 1nst&l.l.ed. 1n an operatin& computer which 1s being subJected to the rtbrat1on requirement.a specitied in the applicable specitications tor the computer aubaystem. Acceptance criteria tor the module shall be the compliance ot the com•
put.er subsystem with its applicable apeciticatione. | •
].2 | PROIXm Caa"IOURATI0B
3·~2.1: | Ilv\WINGS. The conrtguratioo ot the aaaembly aball. be 1n accordance vith
APOILO G&M Drawing 2003982 and all dravin&s and engineering data referenced tbez:eon.

3.2.2 Weight ot the module 8hall. be recorded.

. ·-- -. ·-• -- -- ·- ·-- T

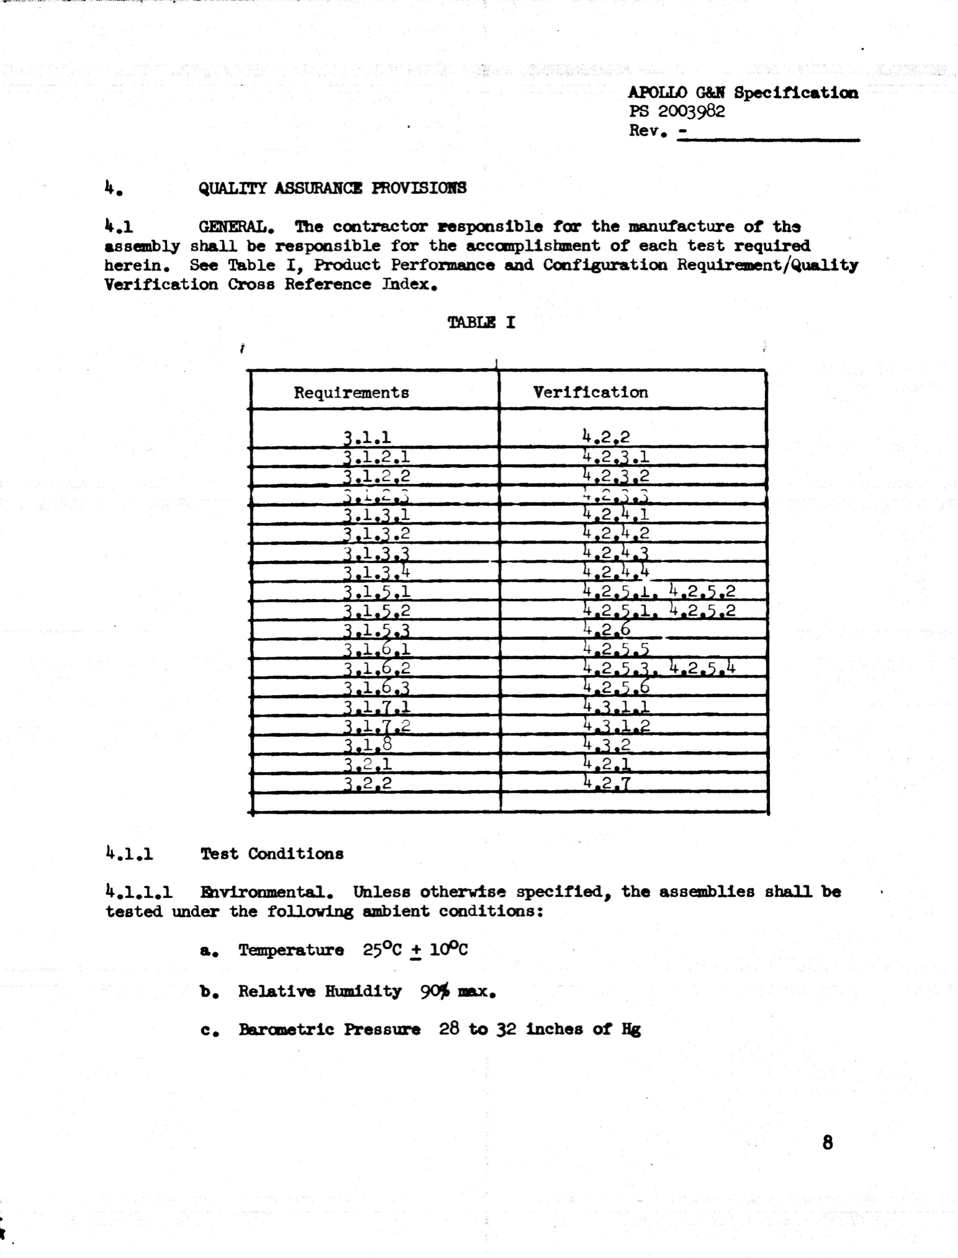
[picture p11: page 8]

4 • | QUALITY ASSURANCI PROVISIOlfS

APOLLO G&5 Specificatim
PS 2003982
Rev. -
~.l | GENERAL. '!'he contractor nsponsible tar the man~acture ot tbs
assembly shall be responsible for the accanplisbment of each test required herein. See Table I, Product Performance and Configuration Requirement/Qm.l.it7 Verification Cross Reference Index.

'.mBLBI

Requirements | Verification
~ .1.1 | 4.2.2
.1.2 .1 | 4 . 2 . -=! .l
.1.2 . 2 | 4.2 .3 . 2
) • .i,. ;: _ ~ | 1 | ,... | ........
.., •"- .. "\ | '\
-=l .L-=l .l | 4.2 4.1
3 .1.3 . 2 | 4.2 . 4 . 2
- .L-=l . -=l | 4.2.4.-=l
.1 • ., .4 | 4 .2.4 .4
.1.5 .1 | +.2 . 5 .L 4 .2.5.2
3 .1.5.2 | t . 2 . 5 .1. 4.2.5 .2
1 .1.5 .-=l | -2 f.
1 .1.6 .1 | i. . 2 . '-i . s
1 .1.6 . 2 | 4.2 . 5 . i . 4.2.5.4
1 .1.6 .i | .2.5 .6
3 .L 7 1 | . ':l.Ll
3 .1.7.2 | • -=! . 1 .2
.1.8 | i. i . 2
. 2 .1 | 4.2 .1
. 2 .2 | 4.2 .7

Test Conditions

### 4.1.1.1 Jfnviroomental. Unless otherwise specified, the assemblies shall be

tested under the following ambient conditions:
a. Temperature 25°c ! 100c
b. Relative Humidity ~ -.x.
c. Baralletric Pressure 28 to 32 inches ot Hg

8

A.POLU) OM &oeciftcatioa
PS 2003982 - Rev• _________ _

4.2.3.3 Measure the resistance between pin 269 (chassis ground) and the
chassis, and verify that it is as specified in paragraph 3.1.2.3.

4.2.4 Insulation Resistance Tests. Using a resistance bridge or equivalent
vith a test potential or 50 VDC llmited to a short circuit current of 50 microamperes, perform. the toll.ov1.ng:
4.2.4.1 Measure the resistance between any one pin Band all other pin B's,
and any one pin E and all other pin E's, and verify that they are as specified
in paragraph 3 .1.3 .1.

4.2.4.2 Measure the resistance between each pin Band all pins G, H, I, J, and pins 126, 128, 103,229,234, and 268. Verify that tht..y are as specified in paragraph 3.1.3.2.

4.2.4.3 Measure the reUstance between each pin I and all pins o, R, I, J, and pins 126, 128,103,229, 234, and 268. Verify that they are as specified in paragrapb 3.~.J.j.

4.2.4.4 Measure the resistance between pin 269 and all other pins on the module, and verify that they are u specified in paragraph 3.1.3.4.

| Functional Tests
4.2.5.1 With the input signal of paragraph 4.1.5.1 applied to pins A• C of each stage, and the output (pin G) loaded with the circuit shown in paragraph 4.1.4, measure the output at pin G and verify that it is in accordance vith paragraphs 3.1.5.1 and 3.1.5.2.

4.2.5.2 With the input signal of p&ragraph 4.1.5.1 applied to Pins D • P of ea.ch stage, mee.sure the output at pin J and verify that it is in accordance vith paragraphs 3.1.5.l and 3.1.5.2.

4.2.5.3 With the input signal of paragraph 4.1.5.2.1 applied to pins A• C of each stage, and the output (pin 0) loaded vith the circuit shown in paragraph 4.1.4, measure the output at pin O and verify that it 1a in accordance vith paragraph 3.1.6.2.

4.2.5.4 With the input signa1 of paragraph 4.1.5.2.1, applied to pins D • F of each stage, measure the output at pin J and verify that it is 1n accordance vith paragraph 3.1.6.2.

4.2.5.5 With the input signal of paragraph 4.1.5.2.2 applied to pin 268, measure the output at pin 126 and verify that it is in accordance vith paragraph 3.1.6.1.

12

~ our ll>ee1ftoatlm
18200398Q Rn D
... 1.5.6 Vitb tbl 1nput •tcnal of puqrapb ... 1.5.2.1 appl1e4 to plu A a C Uld
D •rot eacla nap, aD4 piA I loa4e4 v1t.h a 1000 o1a .:t ~ rMiltor, .... un u.e
output at~ I M4 .... u, '-' lt 11 in 8NCll'dMH v1tb JU'-.npla J.1.,.3.
i..2.6 Oda 11Hol.llt1on. u.s.111 the followtq fmmula, eal.eulate tbe aaill l"HCWIU•
ta _. atace, aD4 Nl'itJ tb&t '-an in aooordaAoe vitb JU'-.npla 3.1.5.3.
GlD imamml • ~-Ak | '
I

Jm'SI IN pancnpla ... 1.5.1 t. .. ftattiou ot --~. i..2.T V.lcbt. V.tp tbe mc'ule to tile ••Mn .01 pouncl. T...U,, tbat '- Wicln

'°9a lliM aoee4 \be Mr'Dn allow.ble ~ apNiftecl 1a pancnpia )oiolo
,.3 . -~ 1ftlUDld!IHIP. !he tollov1nc telt1 lball N pwtw I IIDcla tbe 80Dlllt1_. apeeiftail u a ftl'Uie&ti• ot &004 war--.111,.

~.] .1 llu'l,1al 1bl.taa9 Md Teapiftture •u ■ II•

i..3.1.1 1f1tb \be 1nplt \l'Oltap and _,1•\ t aperatve u -,eeitlecl in ~pll ].l.'i.l, repeat
~

### teet1 i..2.5.1 tbrouCb 4.2.6. VVU, tbat tbe mc'11le pertaraa u apecit1e4 ill

3.1.1.1 •

. IOBI !be aodule lball be -.in+.!eed a\ tM .,_iftell ■■pa'&tun tw DOt le•• t.ball 30 ainutee Jl'10I' to nut ~ telta.
~.,.1.1 Vita tbe inpat 'nl.tap Ull4 --~ t1~tun .. -,.oltt.e4 la,., | 3.1.1.a,

~t teeta A..2.5.1 tbroup 4.2.6. Yerif'J tat tbe _,..,ale i,wtuaw u epasit19cl 1D
pancnpla 3.1.1.1.
IO'l'S: '!'be aodule aball N J1&11lta1ne4 at '8le apeotftecl tll IAI'•'-" m ... lHI 1ibu 30 ailwt.e prior '8 1tu"\ et t.eeu.
i. .3. 1 .] 111 tb tbe input YOltap an4 Mbten, tcperat_.. u apec1tle4 1D plZ'll,ll'llpll 3 .1. T -t, repeat te1ta ... 2.5.1. tarouaaa 4.a.6. v..u, tb&t 1iM aodaale pertoru u ipeaU1ecl 1D Jl&l'aanpll3.1.1.J.
IIO'ml 'Ille aodule lllal.l N MJ.n+,.t,_ a\ \be .,_tftecl ~tun._-' lei• tb&D 30111Aut.e prior to nart ot te1ta •
... 3.a ftbratS... Inatall ta.. aodule tn • appl.1oable ecaputer. SubJ•t tbe ...
piter 1Ub171ta to tbe nbrattan wna apeeittecl la-. applloable JDC. vauy tba\ tbe eCl pUter 8\lbqltea .. w tbe rtt 11 ICU fll tbe api,UoablAt 9PNU1.Mtt.ca.
5 • | fDPAJtAflCII J<a DILIORY
5.1 | GIIEAL. ~ts. fm Mliftl'7 ..UN la _.crianoe wttll lpNUS.-tima
ID 1~.
'• | IO'l'IBI | .,_

13

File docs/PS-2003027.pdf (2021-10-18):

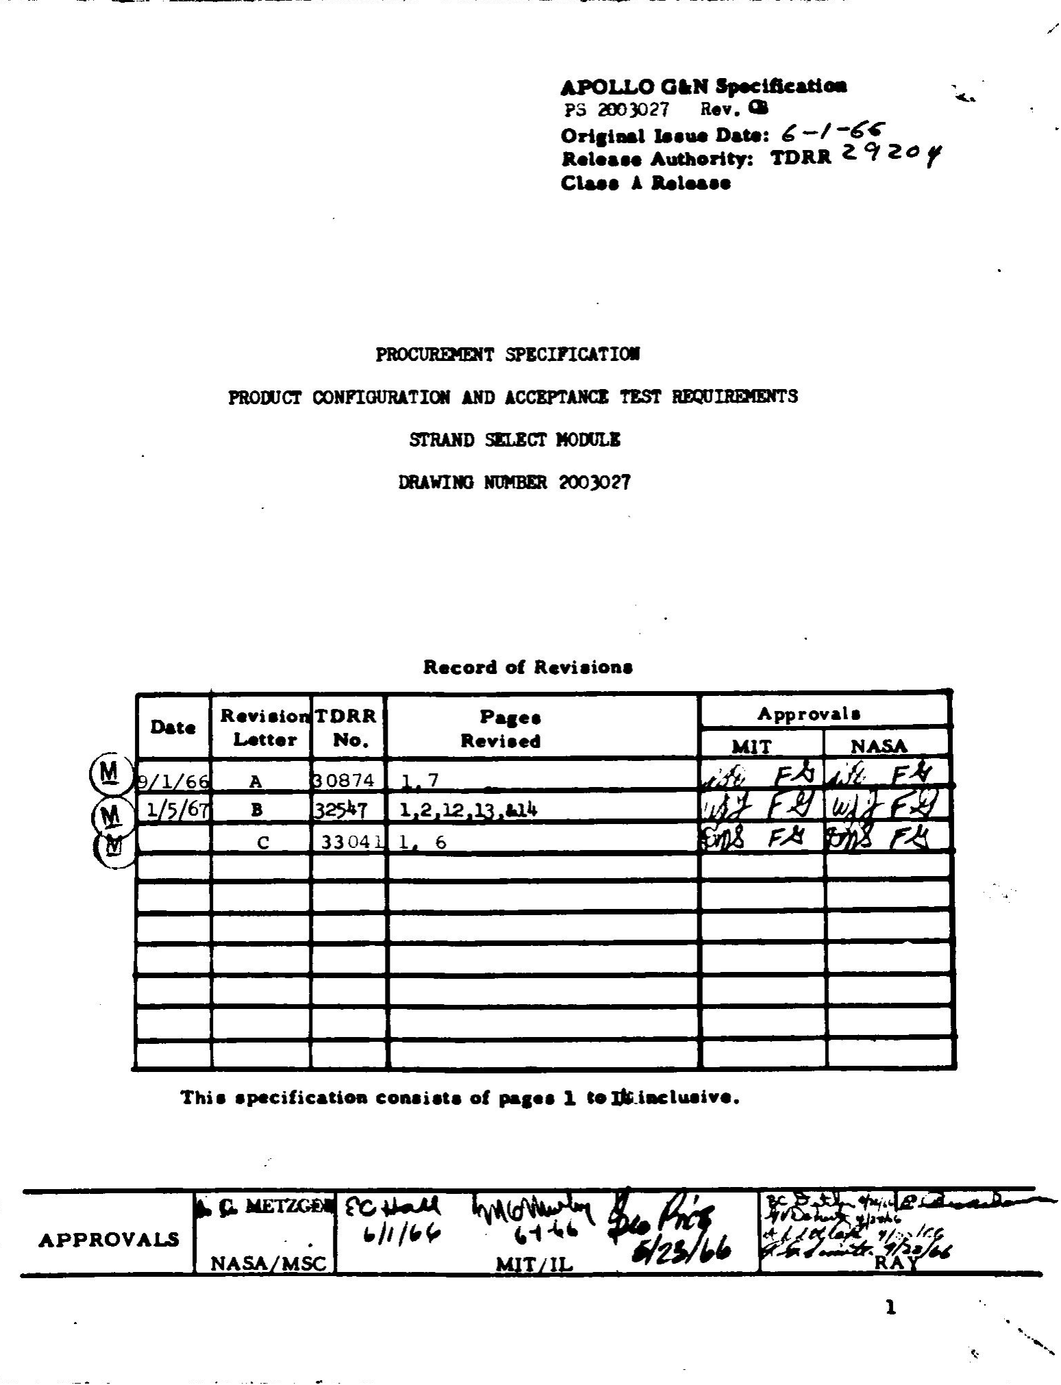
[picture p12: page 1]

t
n.t
~

Date

9/l/6E
1/5/61

APOLLO a•N Spectacad•
PS 200)027 Rev. ca
Ori1t•I laaue Date: €-I-~~ Relean Authority: TDJlA Z. ~ 2 o f Clue la.lea••

PROCURmmCT SPICinCATI<II
PROOOCT CONfiOURATICJf AND ACCEPTAMCI TESr RWJnmmNTS

STRAHD SILICT MOOOLI

lllAWI111 NUMBER 200)027

Record of Reviaiona

Reviaio11 TORR | Pqea | Approval•
Letter | No. | Reviaed | MIT | NASA
A | 30874 | 1 7 | lj:~; FA ~·//, F-"~
B | 32541 | 1.2.12.n.1a1.4 | ,,J ... 1- F .JJ w~lr ~ '-1
C | 33 04 1 1. 6 | un1 FA &)l IX r..e.

Thi• apecificatloa conaieta of pa1•• 1 •••-•actuive.

re,~
APPROVALS | ~Ji /f,(;,
NASA MSC
1

1. SCOPE

APOLLO G&N Specitic1tion
PS 2003027
ReT

Thie apecitication e1tabli1he1 the detail requirements tor coaplete identitication and 1ccept1nce ol the Strand Select Module, part nUllber 200)027-021.
2. APPLICABLE OOCUMENTS

The following documents fOJ.'11 • part of this specific1t1on to the extent specitied herein.
2.1 !Fn:CTIVE ISSUES. Unless othervi• specified herein, Militarr and Govel"l'lllent Standard• and apecitic1tion■ 1hall be the issue in effect on the date ot request for proposal or 1m1.tetion to bid.

SPECIFICATIONS

| AFOLLO G&N
| HD 100221.b

I&WINGS

UOLW Gldl
2003027

•

General Specitication, tor Preservation, Peckaging, Packing end Container Marking ot APOLLO Guidance and Navigation Major Assabliea, Assoblies, Subasaeablies,

Parts.and Associated Ground Support EquipNnt.

Strand Select Module Aaaeab~ (Copiea of speciticationa, atandard1, drawings, balletins and publications required bJ suppliera 1n connection with specific procurement functions should be obtained troa the procuring acti't'lf.7 or as directed by the Contracting Officer).

2.2 CONFLICTING REQUIRDmll'S. In the ennt ot conflict between the requireaenta ot the contract, this peciticartion ind the doeuaenta listed in this section, the following order of precedence shall apply and the contractor shall notity KIT APOLW Manageaent ot the conflict a■ soon 81 it is detenli.ned.

a• The contract.
b. Thia Speciticatian
c. Docuaents listed in thi■ eecti on

2

).1.7 (Coat•d)

APOLLO O&Jf Spacitic•tion
PS 2003027

# Rff --------

Table J-1, - Cbancterl tica of 011tpats J and L
Ch•r•cteria tic | Out.pit) Liait.a | ()Qtpat L Lilli ta
Allplitude (A1) High | ...,___ .... | O.l YOlt below B+ JUX
Allpli tude (.&) | 1.26 .t o.06 TOlt• | -------- Allplitude (A2) Low | ------- | 1.00 .t 0.1s wits
Allplitude (A3) | 0.01 YOlt■ | --·------ Tum OIi (Ton) | 0.2 11•ec •• | 0.15 uec amt
. Tum OW {T ott) | l.S UNC aes | 0.] 11HC aaz
J.l.8 | Marginal Voltage a,d Te■►~ture Extreaes. The aodu.le hall perfol'II H
apecU'ied 1n paragraph• 3.1.S through J.1.6 when nbjected to the ccabinetions ot ntrae TOltagH and taperatuna 1pecU'ied 1n (e) and (b) below• •
(a) Low at.NM• ·
(b) High extrae1

12.2 ~ 0.l "Ide and -lOoC +00C -2.aoe.

16.S .t 0.1 Tdc mc1 ·1oOc +2.eoe
.aoe.

The requ1NMnt1 fOI' aplitude .&1 high tor output.a 1 and 3 under the •rginal Tol t•g• a teaperatun atraee are u follow■:

O.tpat l tolermoe (S.. Table 3-2) shell be incre••ed bJ o.o; volt.

Output J •aaw nu hall be 1.28 -t0.13 Tolta tor t.he low atNM ~.o6
and shell be 1.26 -tO.o6 TOlta for the hicb atNM.
-O.lJ

J.l.9 Vibretion. The •odule shell perfor11 n apecitied in J.1.6 through 3.1.7 when in•t•lled in •n operating C011pUt.49r which is being 111bjected to the •ibntion requireaent1 1pecitied in the epplic•ble apecitications tor the coaputer subey tea.
Acceptance criteria tor the ltodul• 1h11l be the oaplience of the coapu ter sub• eyatea witb it■ appUceble epeciticationa.

6

3.2 | FROIR"T COIIFIGURATICII

APOILO OM Speci:ficatian
PS 2003 027
Rev -A

3.2.1 IEAWilfGS. The module shall canpl.y vitb APOLLO GU drawing 2003027 and all drawings and engineering data referenced thereon.

Weight. Maximum allo,eble weight ot the module shall be 0."80pounds.

QUALITY ASSURAHCE PROVISIOl!IS
4.1 | GENERAL. '!be contractor responsible tcrr the manufacture ot the
assembly shall be responsible tar the accanpllshment ot ea.ch test required herein. The cross reference index (Table 4-1) shows the relationship between the per-!Ol"lllll!UlCe requtrsenta 1n section 3 and verification~ those requiremente
1n section 4. | ·
Requirement | | Verif'ica tion
3.1.2 | | 4.2.2
3.1.3 | | 4.2.3
3.1.4 | | 4.2.4
3.1.5 | | 4.2.5
3.1.6 | | 4.2.6
3.1.1 | | 4.3.1
3.1.8 | | 4.3.2
3.2.1 | . | 4.2.1
3.2.2 | | 4.2.T
4.1.1 | !fooconforming Units. Failure o:f the unit to pass any examination tr
test ot this speciticatioo shall autaaatically classify the wiit &s noncontaraing. Each nonconforming wiit corrected by the contractor shall be reinspected. Reinspectioo -.y be l.1m1ted to the test or exam:1oatioo which defined the non• conformance, ar, when directed by the cognizant inspector, a canplete Ntest and re-examination -.y be Nquired. Boocoofondng units which have not been corrected will be considered tor acceptance ool.y upoo formal application b)' the contractor to the cognizant liA8A representative.

1

-~ -- | ,J .
~ :~ --- -~ .

t ,l'OLI,O GU Specif1cat1oa ·, PB 2003027
8eY• --------- 4.2.6.2 Outputs. '!be coincidence ot inputs 1 and 2 at the proper terminale

(See Table 4-2 and Pigure l) shall produce outputs in canpliance with the requirements specified in paragraph 3.1.4. ibe output waveform shall ccaply with Figure 2 and shall be maiitored at the pina apecif'ied in Table 4-2. Module Select Current Driver. 4.2.7.1 Input. 'Dle inputs shall ccmply with the requirements specified 1n paragraph 3 .1.6. Be:rer to Table 4-3 and Pigure 3 :ror the sets or related input terminals.

. . _;-~:-_ :-- ·"'··~

·•\. -'r h . .. _ ...

:.: | -1,
4.2.7.2 | Outputs. A coincidence rd signal.a at the proper input terminals (See
Table 4-3 and P1gure 2) shall produce output• (3 and 4) at the related output pins in c0111pl1ance with paragraph 3.1.6. (See P1gure 3 and Table 4-3 :ror inputoutput pin relationship). All A, Land V pins that are not being pulsed shall be ·
. ;, .M_,..tecl ,ia. ___._. Jff.tJt ,-r••~.-e.-e.Ja~ .,: , ::! '·. •~:;, .. | ,

TABUl~-3

Circuit •o. | Input 3 (L) | output 3 | Circuit llo. | Input 4 (V) | Output 4 (W)

. . •' .

40631 | 245 | 131 (M) | 40615 | 138 | 239 .
40632 | | 242 | 134 (N) | 40615 | 138 | 239
40631 | | 245 | 123 <•> | 4061.6 | 129 | 229
40632 | ... | 242 | 125 <•> | 40616 | 129 | 229
40631 | | 245 | 115 (P) | 40617 | 120 | 221
40632 | | 2~ | UT (P) | 40617 | 120 | 221
~.2.8 | 1fetpt. Weigh the aodul.e to the nearest .01. pound. Verify that the
weight does not exceed the mxbua al.low.ble wight apecif'ied 1n paraaraph 3.2.2.
4.3 | WORIMABSHIP. 'Die f'olloving tests sb&ll be pertaned under tile
c011diti011a specif'ied as a ftl'if'1cat1011 ot good varbansh1p.

4.3.1 Nargi.aal Voltap and Temperature Jllctreaes. '1'be :aocleile shall be exposed tot.ta abient temperature :ror at least 30 ainutea prior to starting electrical tests. 'lbe module aball be tested 111 accardance with pangrapba ,..2.4 and 4.2.T, 111 each ot tile ex.tr •e c011d1ti0118 specif'ied in paragraph 3.1.1.

| | | | | | 10 ,

1'18 | > | "C .. Pl"' | ,.,,, INPIIT I | Z69
,,-1

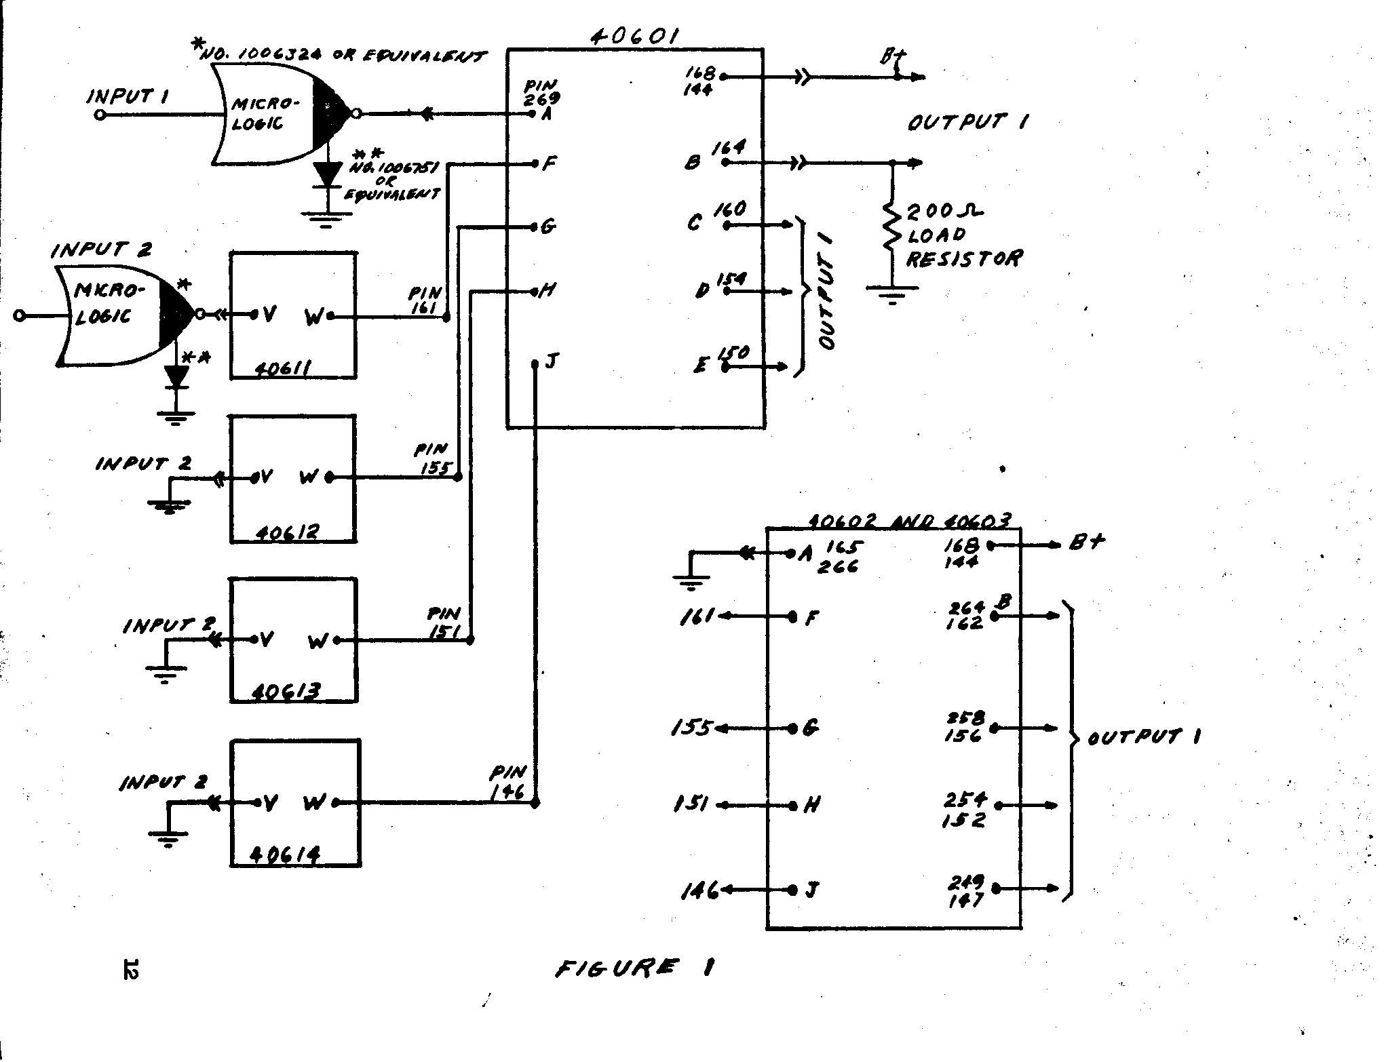
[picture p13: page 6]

*Po, 1cot-.1a.4 o~ ~,:;v,,,,u,;f;lr | ,f-O, 01

(}l/TPVr I A

F | I)
C 1'0 | 2 00..JL.
' | LOAD
//t/PVr ~
~ | RGSJsroN
#IPI | ' /'IN | - '-- | - V 'W | '" | ~

~ | <:)
t.l | :r | r
''"' V .., | 15. | •

8~
-- | . z, • .8 ~IN | ,,, , | ,,2. ~ ·

IN,vr I
V | w
.. | --:-
| | lf5 | | •ra
IS'1 | ovrPvr 1
/A/l'V1' ~ | PIN
V w | f-' | /SI | H | ar,,.
,sz -.
| | '"' | | 2,,
,,., | .":I' | .

Fl6-Vlfl I

T .,

T~ ~ -.I,;

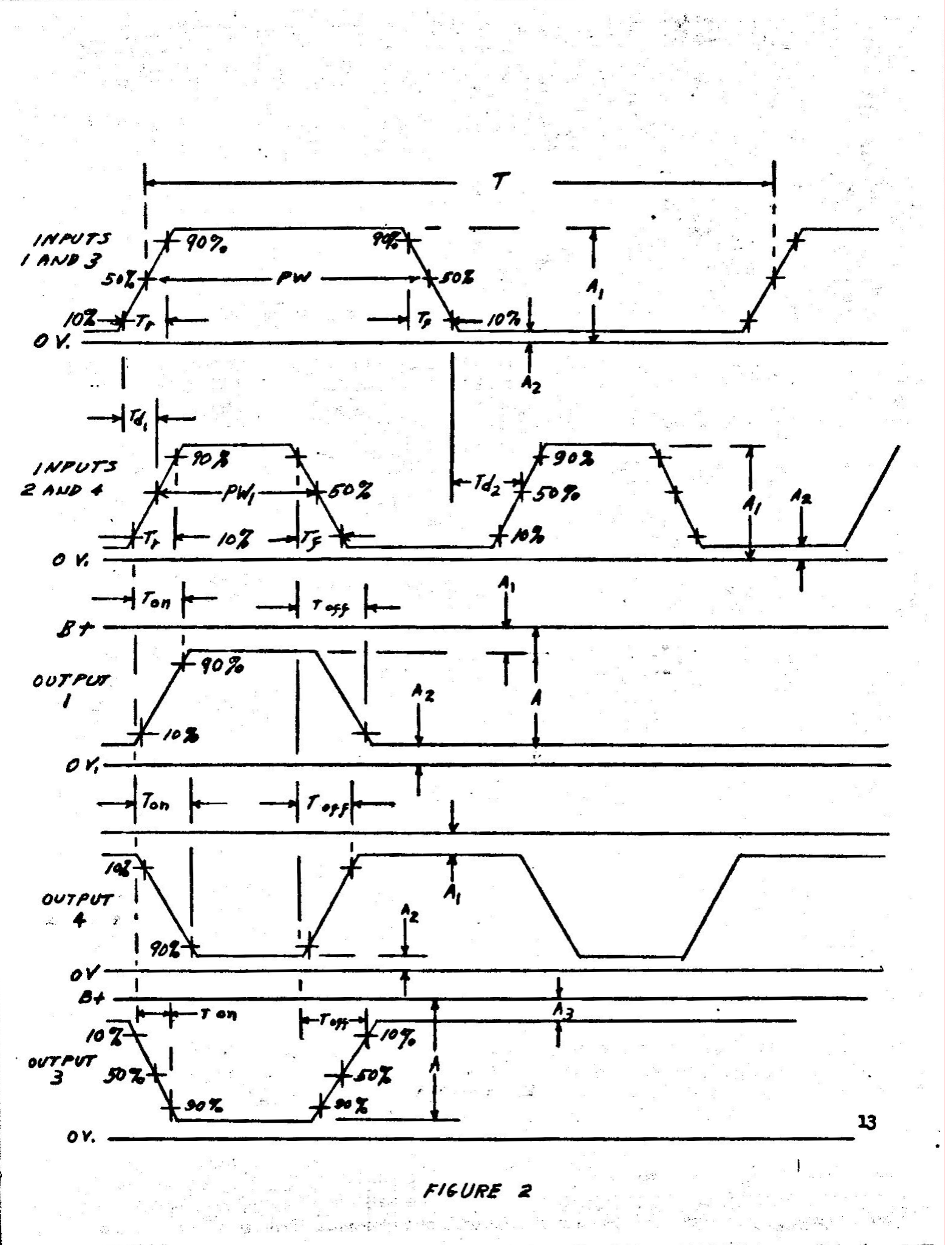
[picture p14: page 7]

/~,-r/T..S | fo,.
111/4./,J
- T s,r~ ----,w -----ns .

T.

Tf-

A
1

# o~-------------.----------------- -1 r... I,-- -I r .,,j-- l l

,.: ♦ i' • I '"' l\o.------11 oV '
I ~+~~~-------:.-----~----------

# 10 % te---+--,. ... · o,rr~vr 3 Jt)~

o~--------------------------~

## ovr,vr .:J

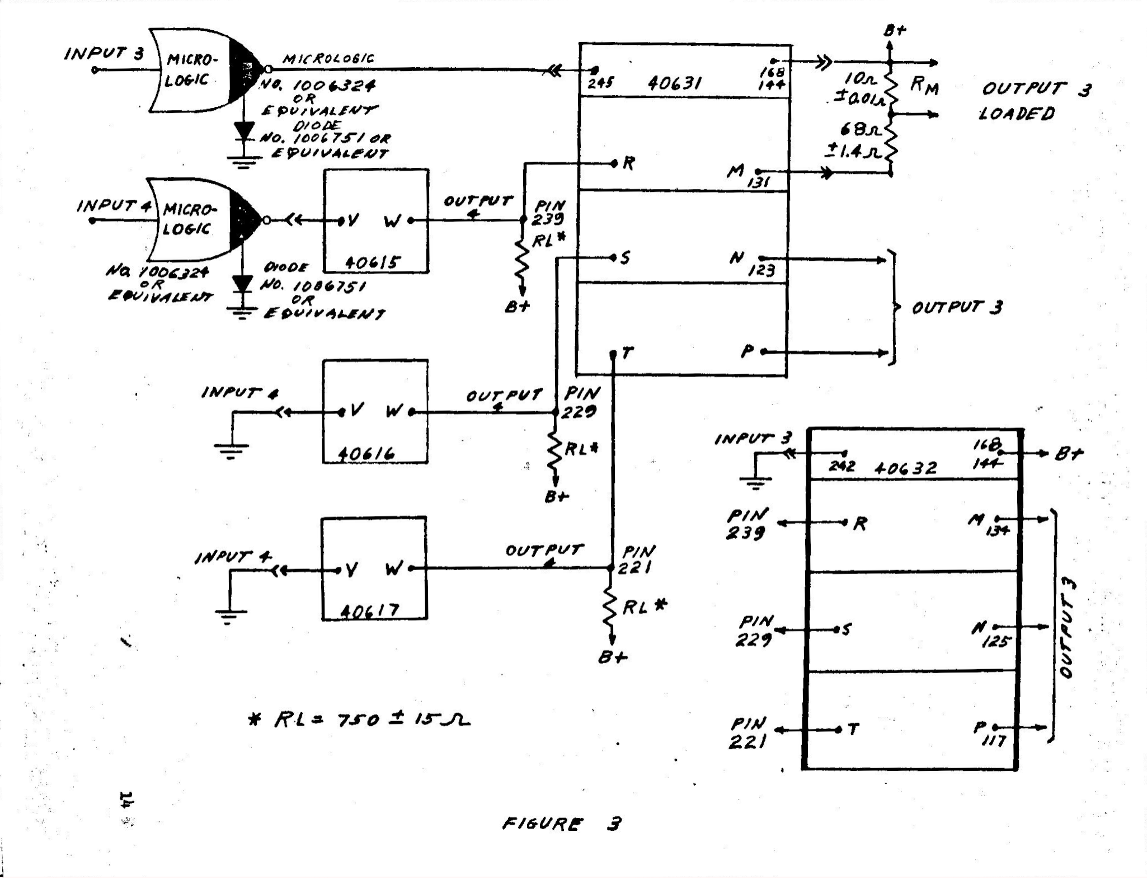
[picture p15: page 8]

INPV7 4

### ovr,vr PIH

V | "' | 2.:1,
,n • 0'1/l" | s /1,oDr ;VQ i'IJD,j2+
o/( | .Vo. /()64,lSI r~IINfUP?'
~ | "~ | IJ+ ¥~CIIINjl,.INT
r
JNl"vr # | ovrPvr PIN
_r II w | 22,,
0,11, | /fL4 -- | -~

Bl-
ovrPvr | PIN .. , | 1NI' V w' | 221 ·t
- | /7 | RL * -
' | B+-

* /?-L .:& 7.ro ::! IS-..A.

/"1131

N 123

INPl/r~
24l
/'I#
631

/'IN
221
PIN | T
2.ZI

-J.0'4PF/J

()VTP(l7 ..J

"a | Br
,I-()' 32 | /ff-

1¥ ,,,,.

~
\..
~ If

~ . .
l~S-
~
~

p
117

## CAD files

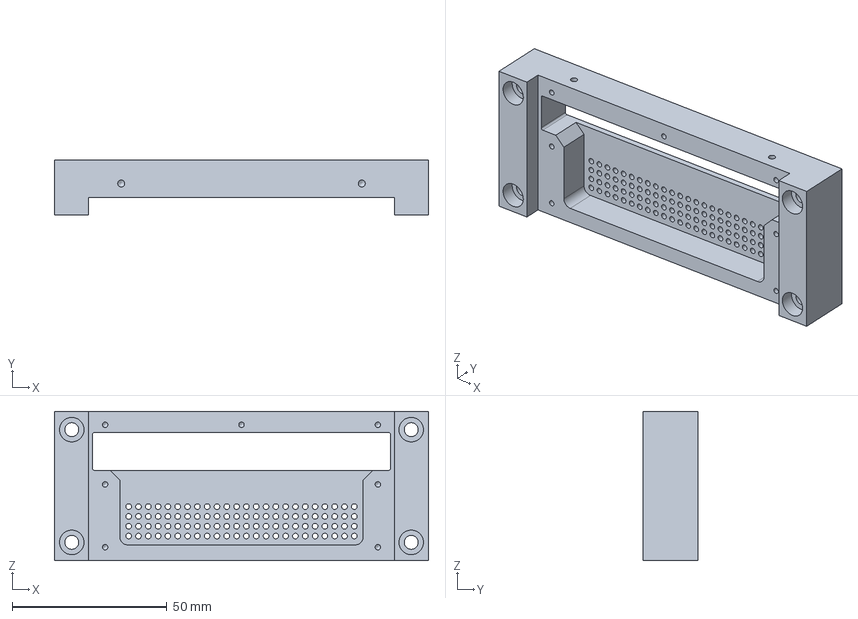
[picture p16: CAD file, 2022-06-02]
mechanical/connector_plate.step
121.0 x 17.8 x 48.3 mm

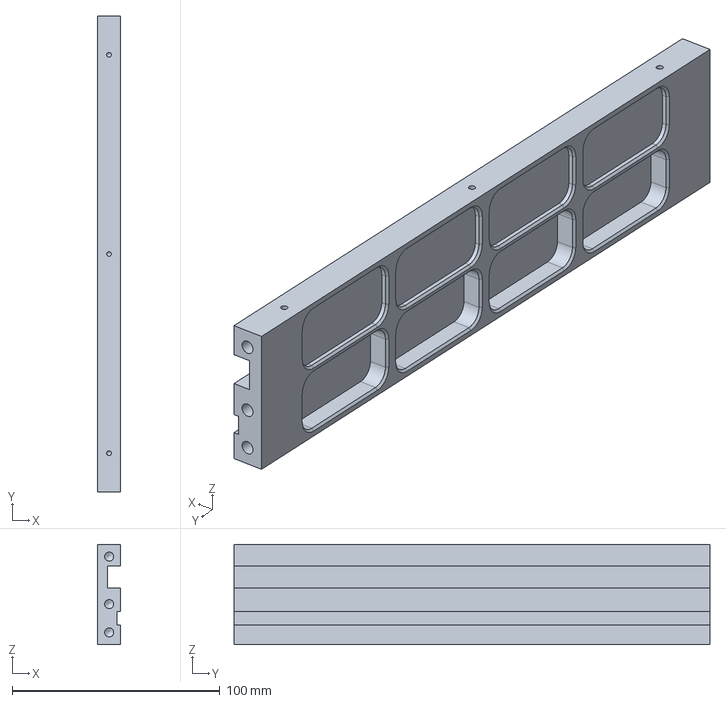
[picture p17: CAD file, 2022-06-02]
mechanical/side.step
11.0 x 229.0 x 48.3 mm

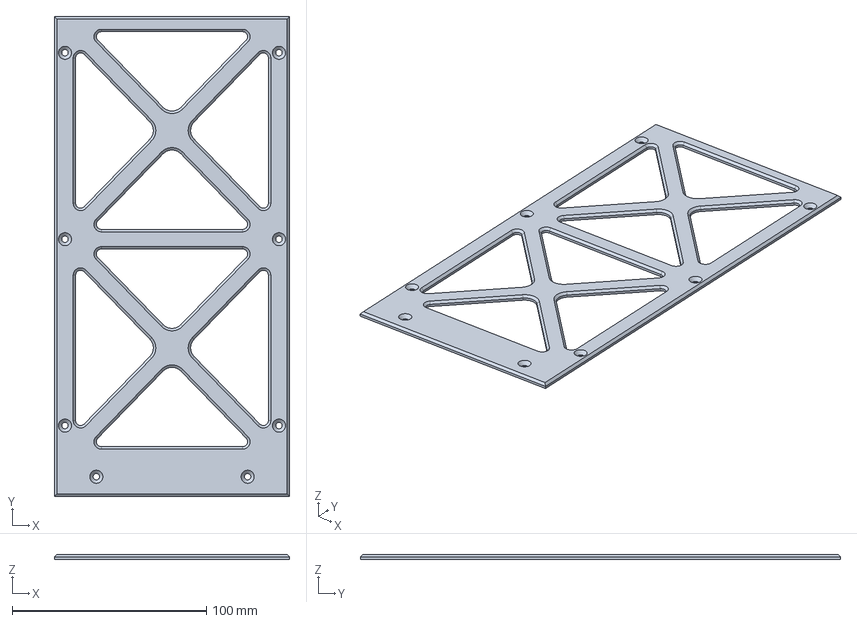
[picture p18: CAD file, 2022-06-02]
mechanical/cover.step
121.0 x 246.8 x 2.54 mm

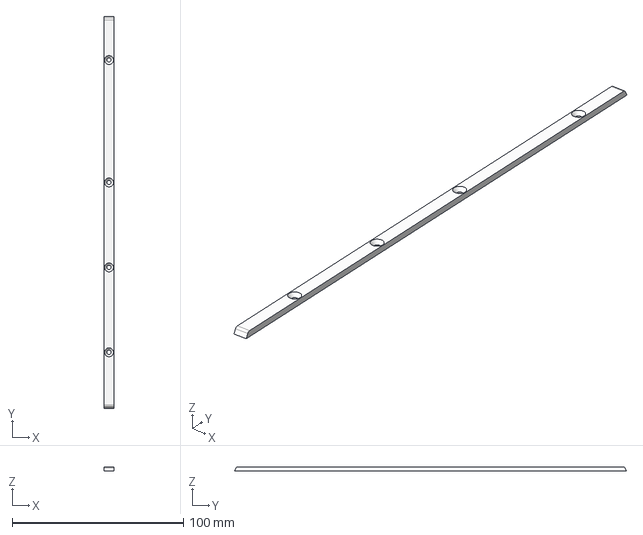
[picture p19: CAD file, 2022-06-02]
mechanical/rail.step
5.71 x 228.6 x 2.54 mm

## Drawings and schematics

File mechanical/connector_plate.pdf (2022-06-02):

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

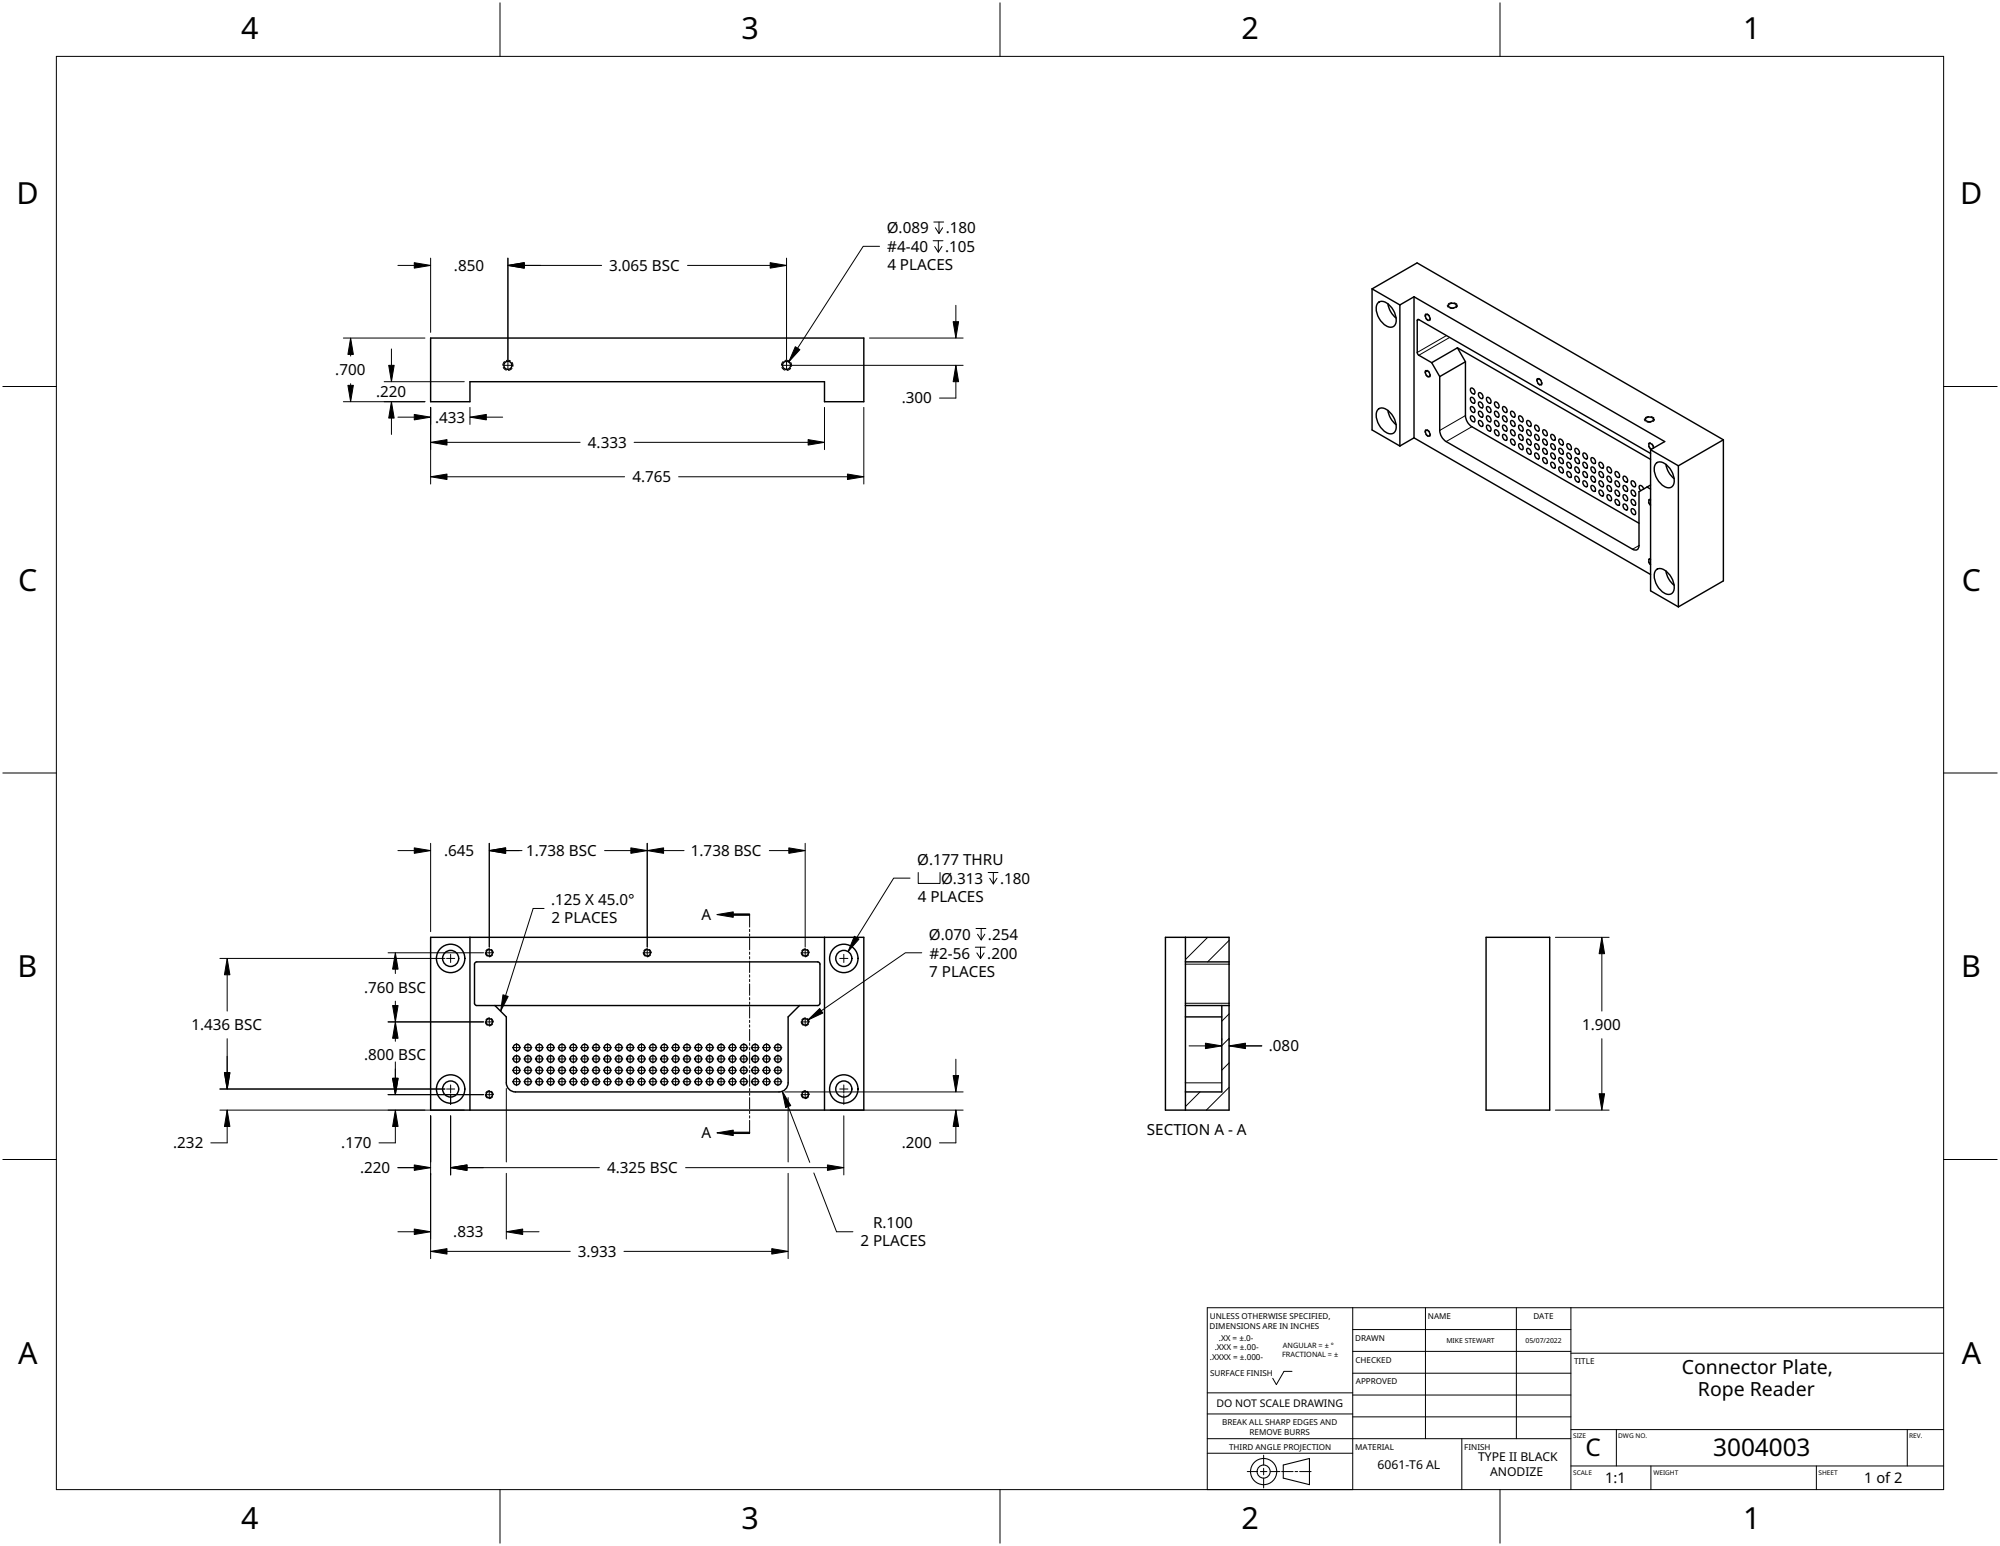
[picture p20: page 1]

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

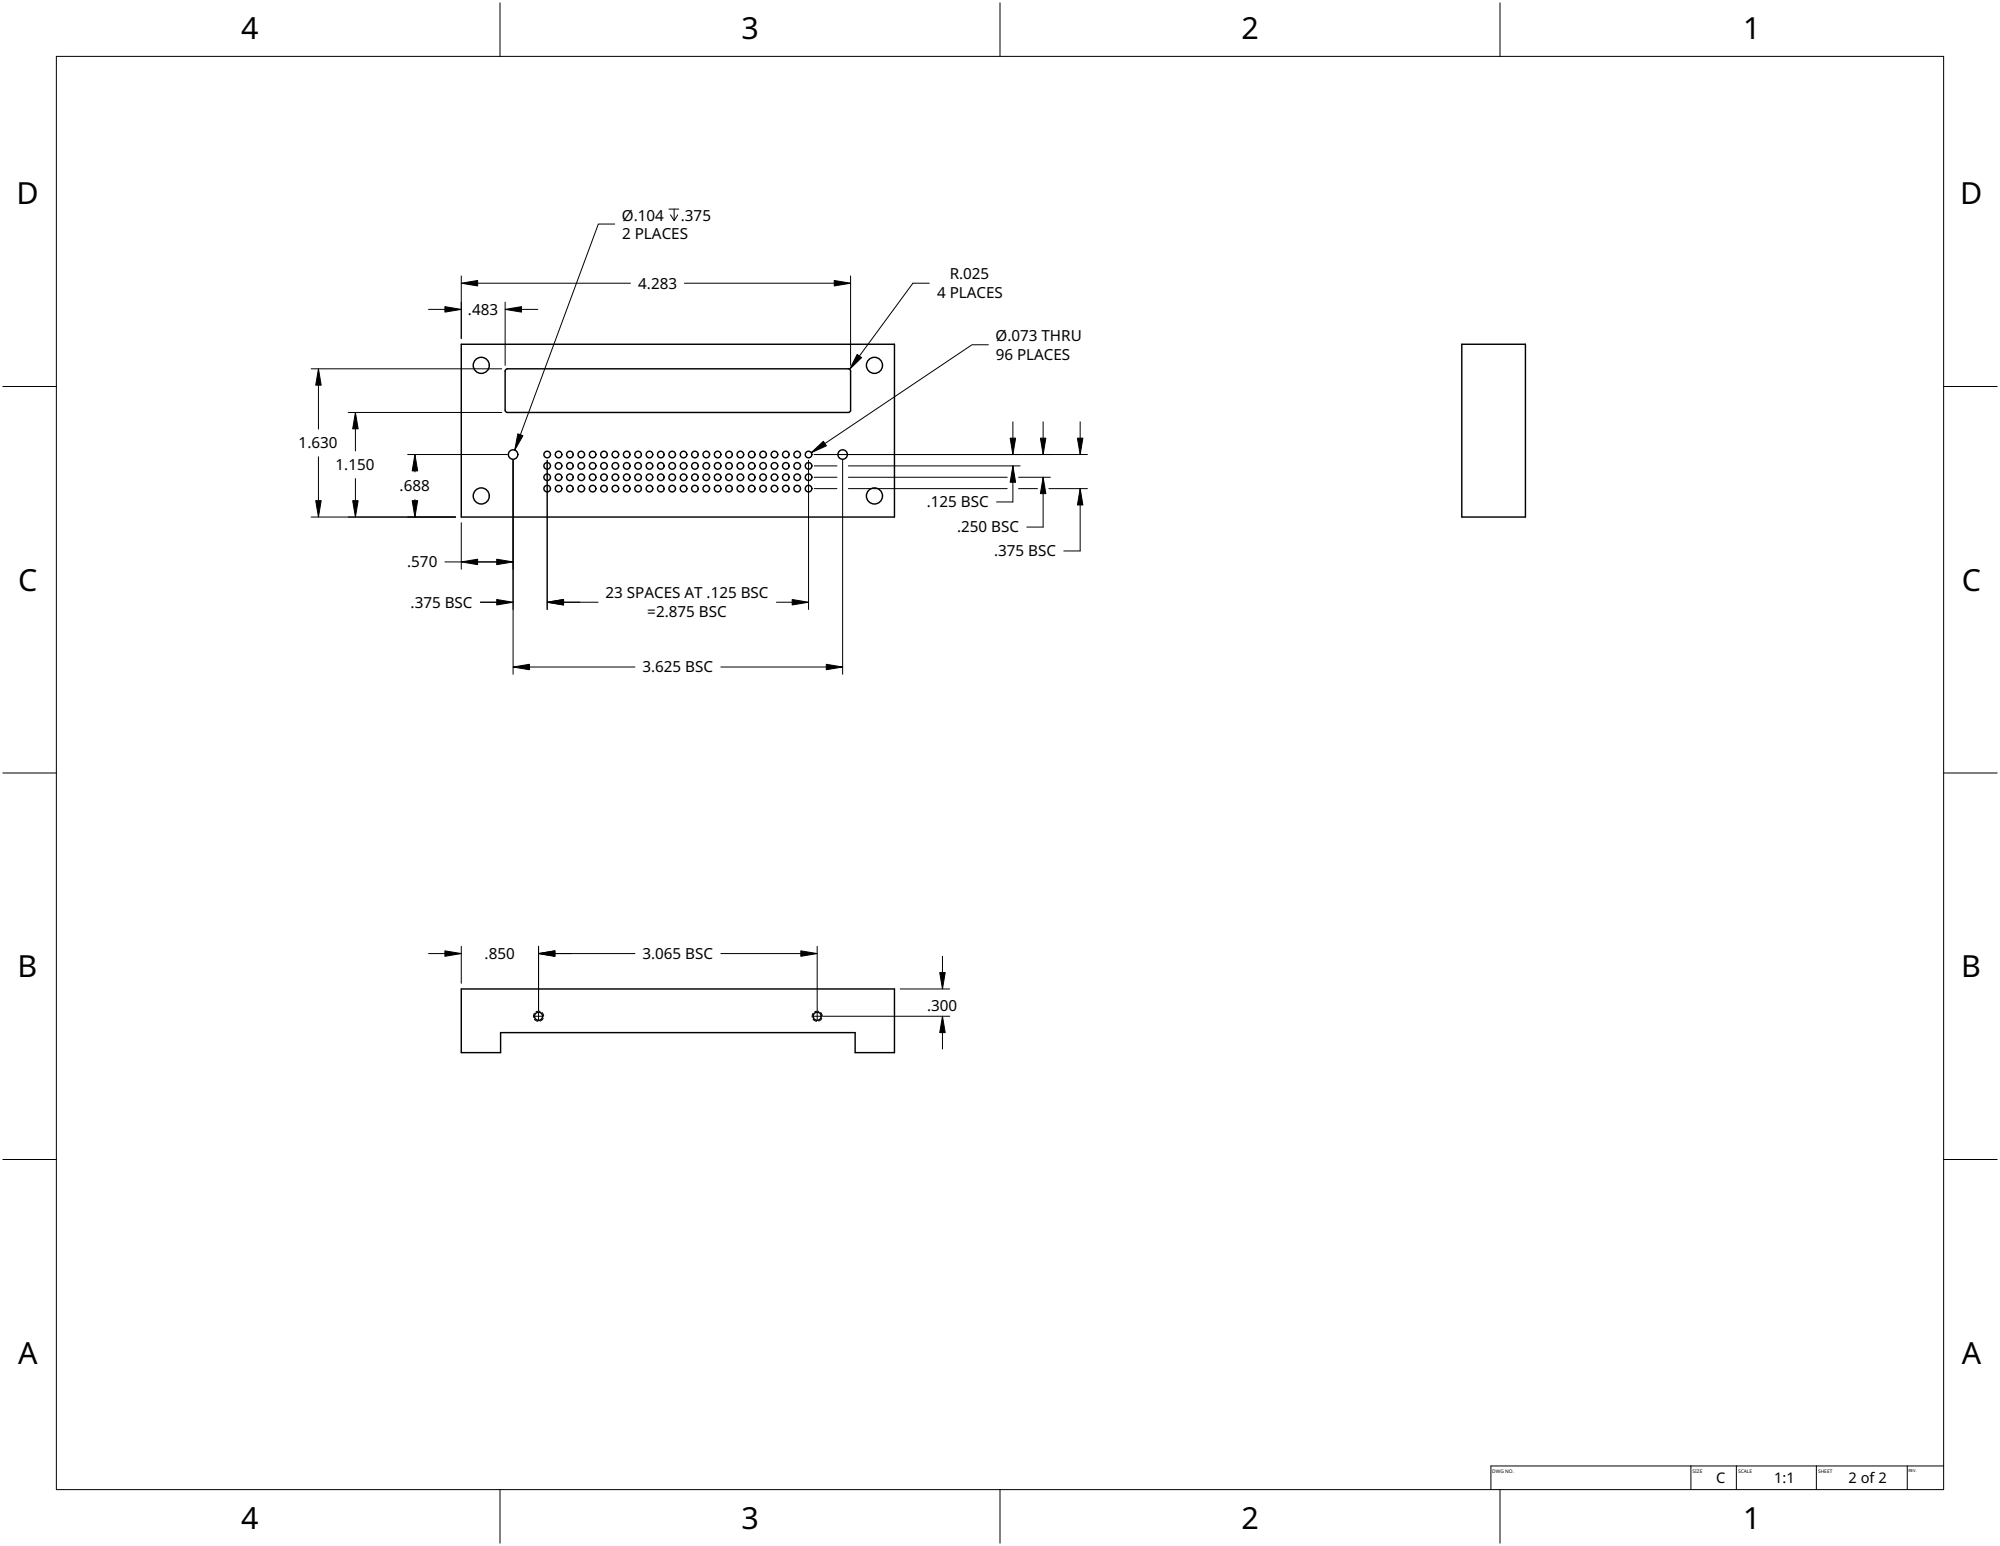
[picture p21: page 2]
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

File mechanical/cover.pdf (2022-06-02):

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

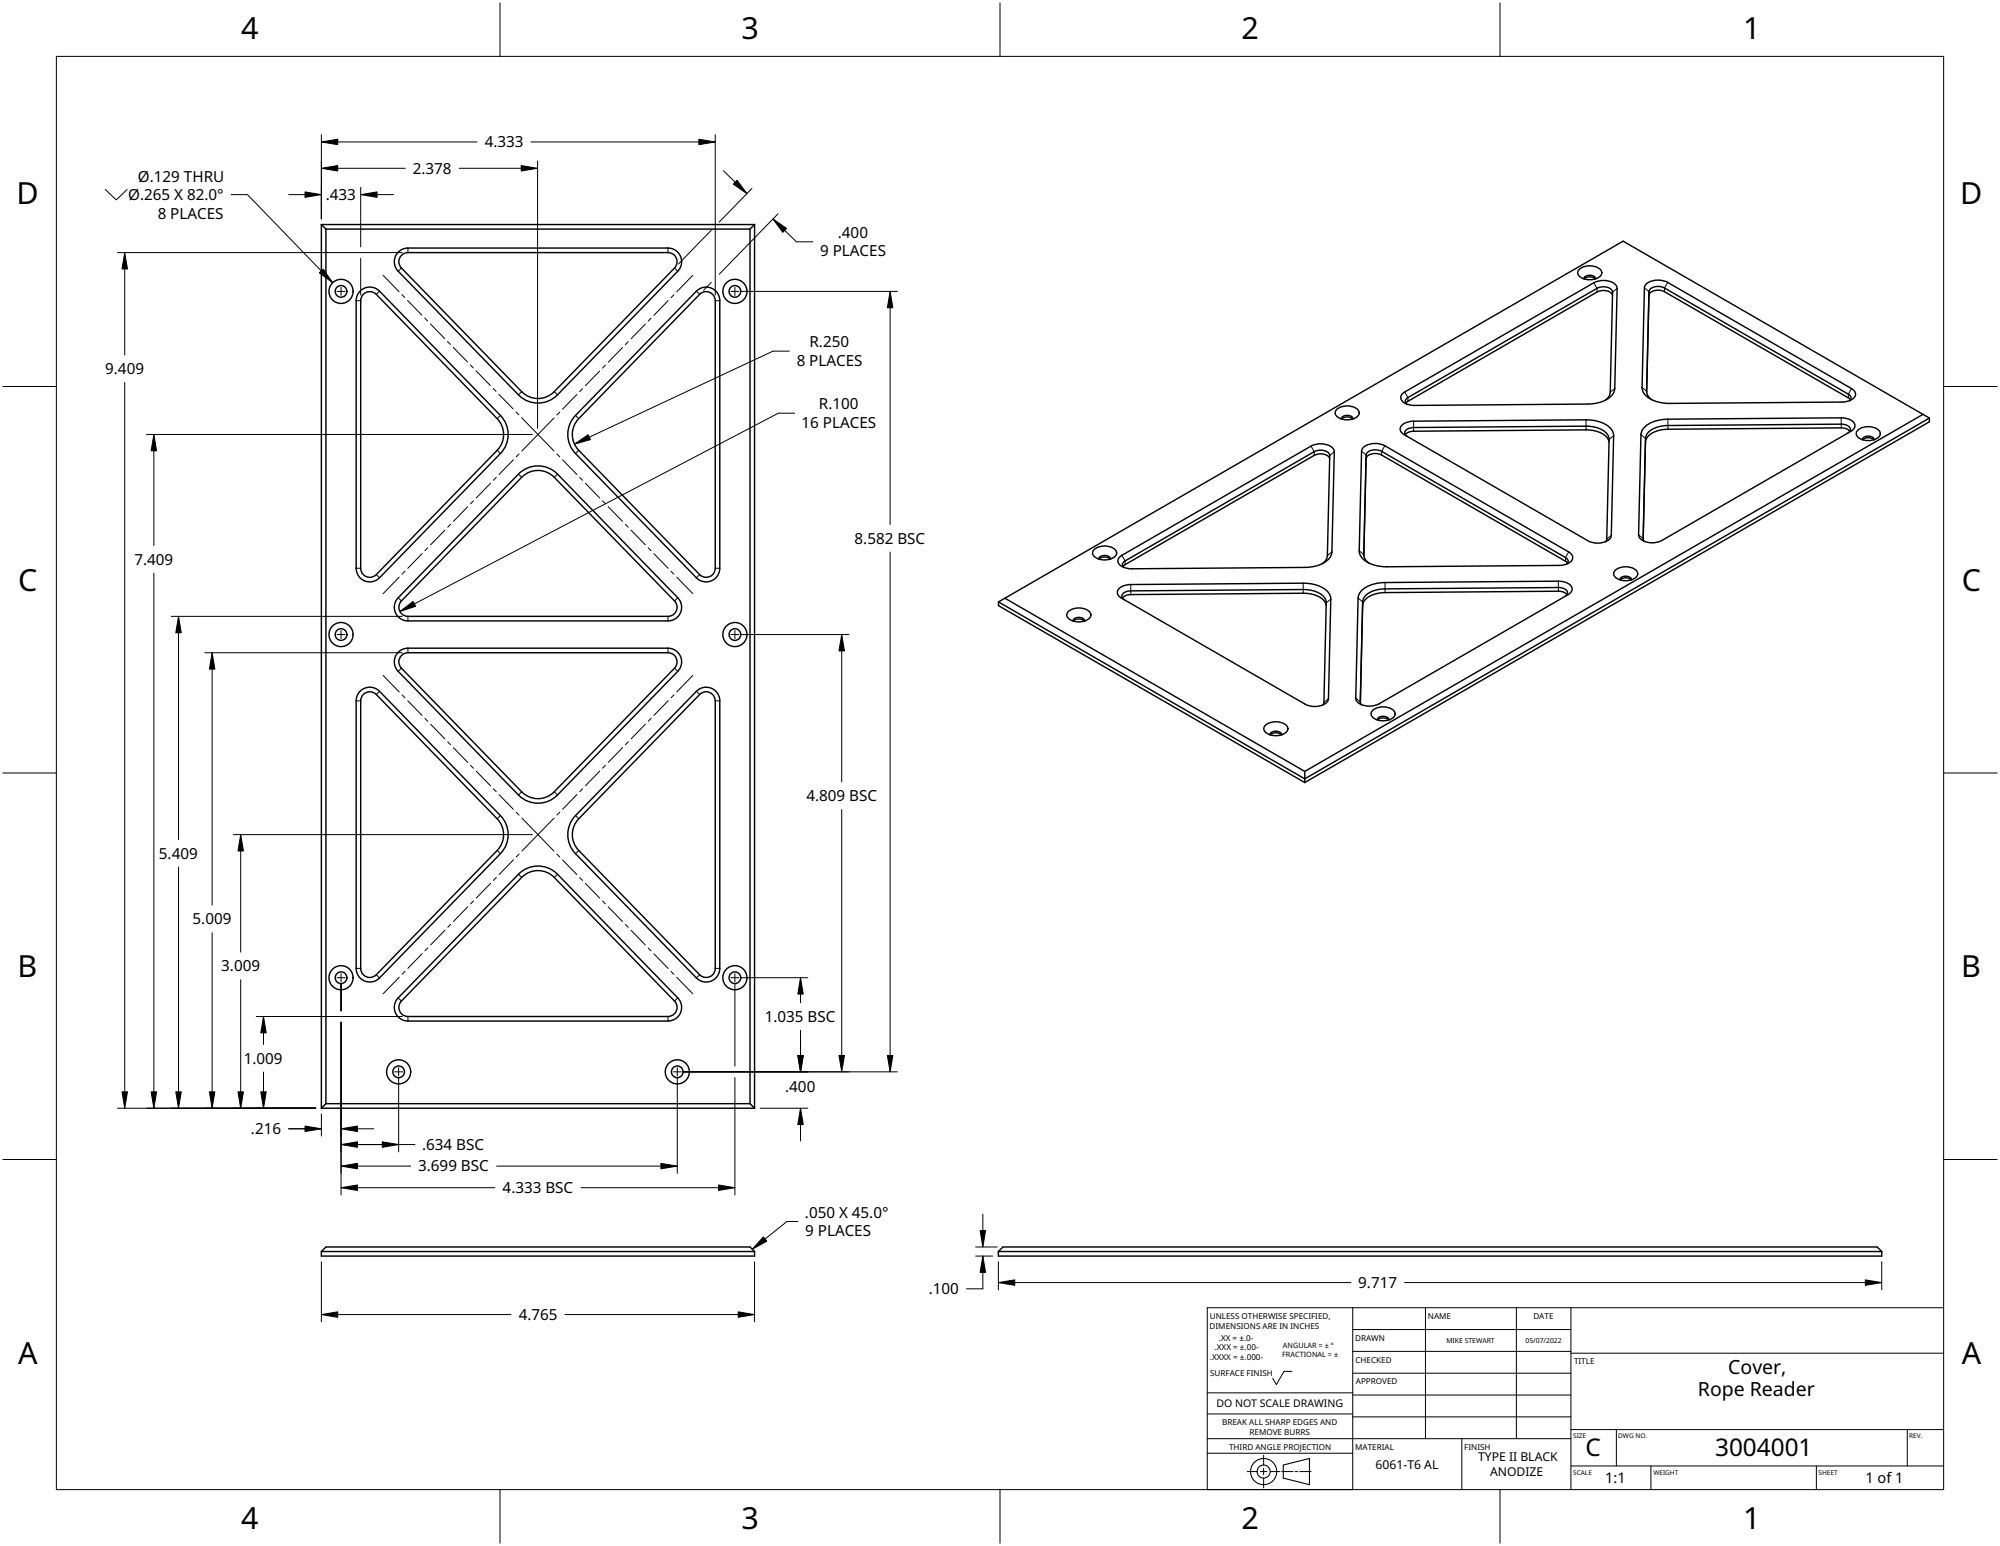
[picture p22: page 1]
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

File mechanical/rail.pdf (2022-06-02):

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

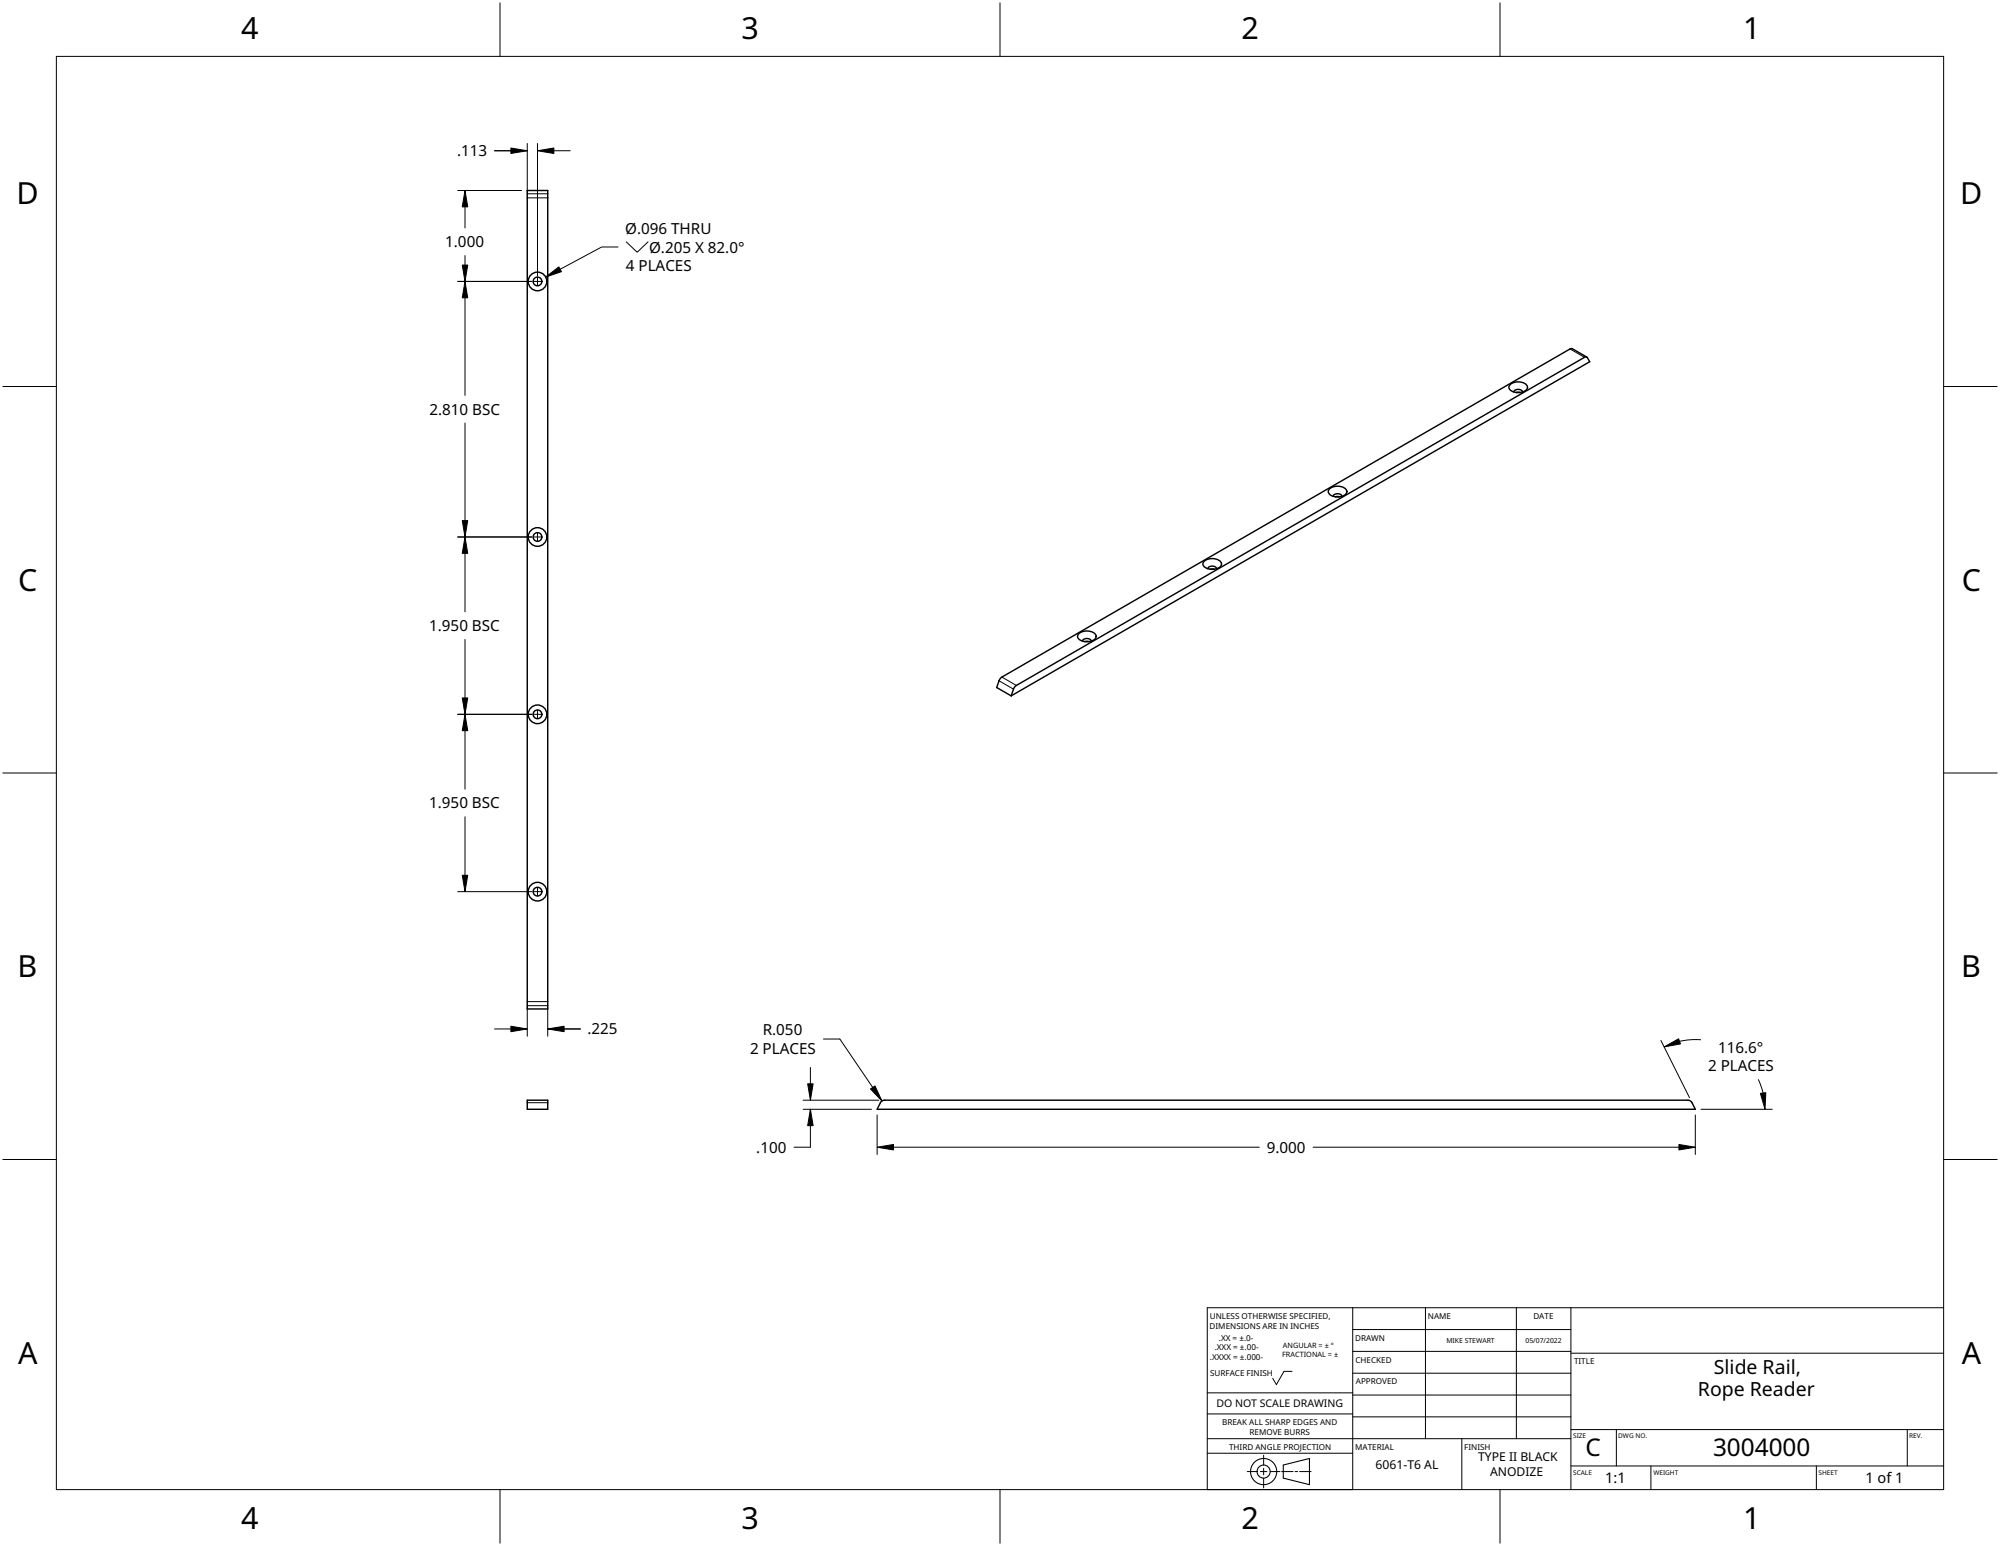
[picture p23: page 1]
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

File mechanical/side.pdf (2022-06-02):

4

3

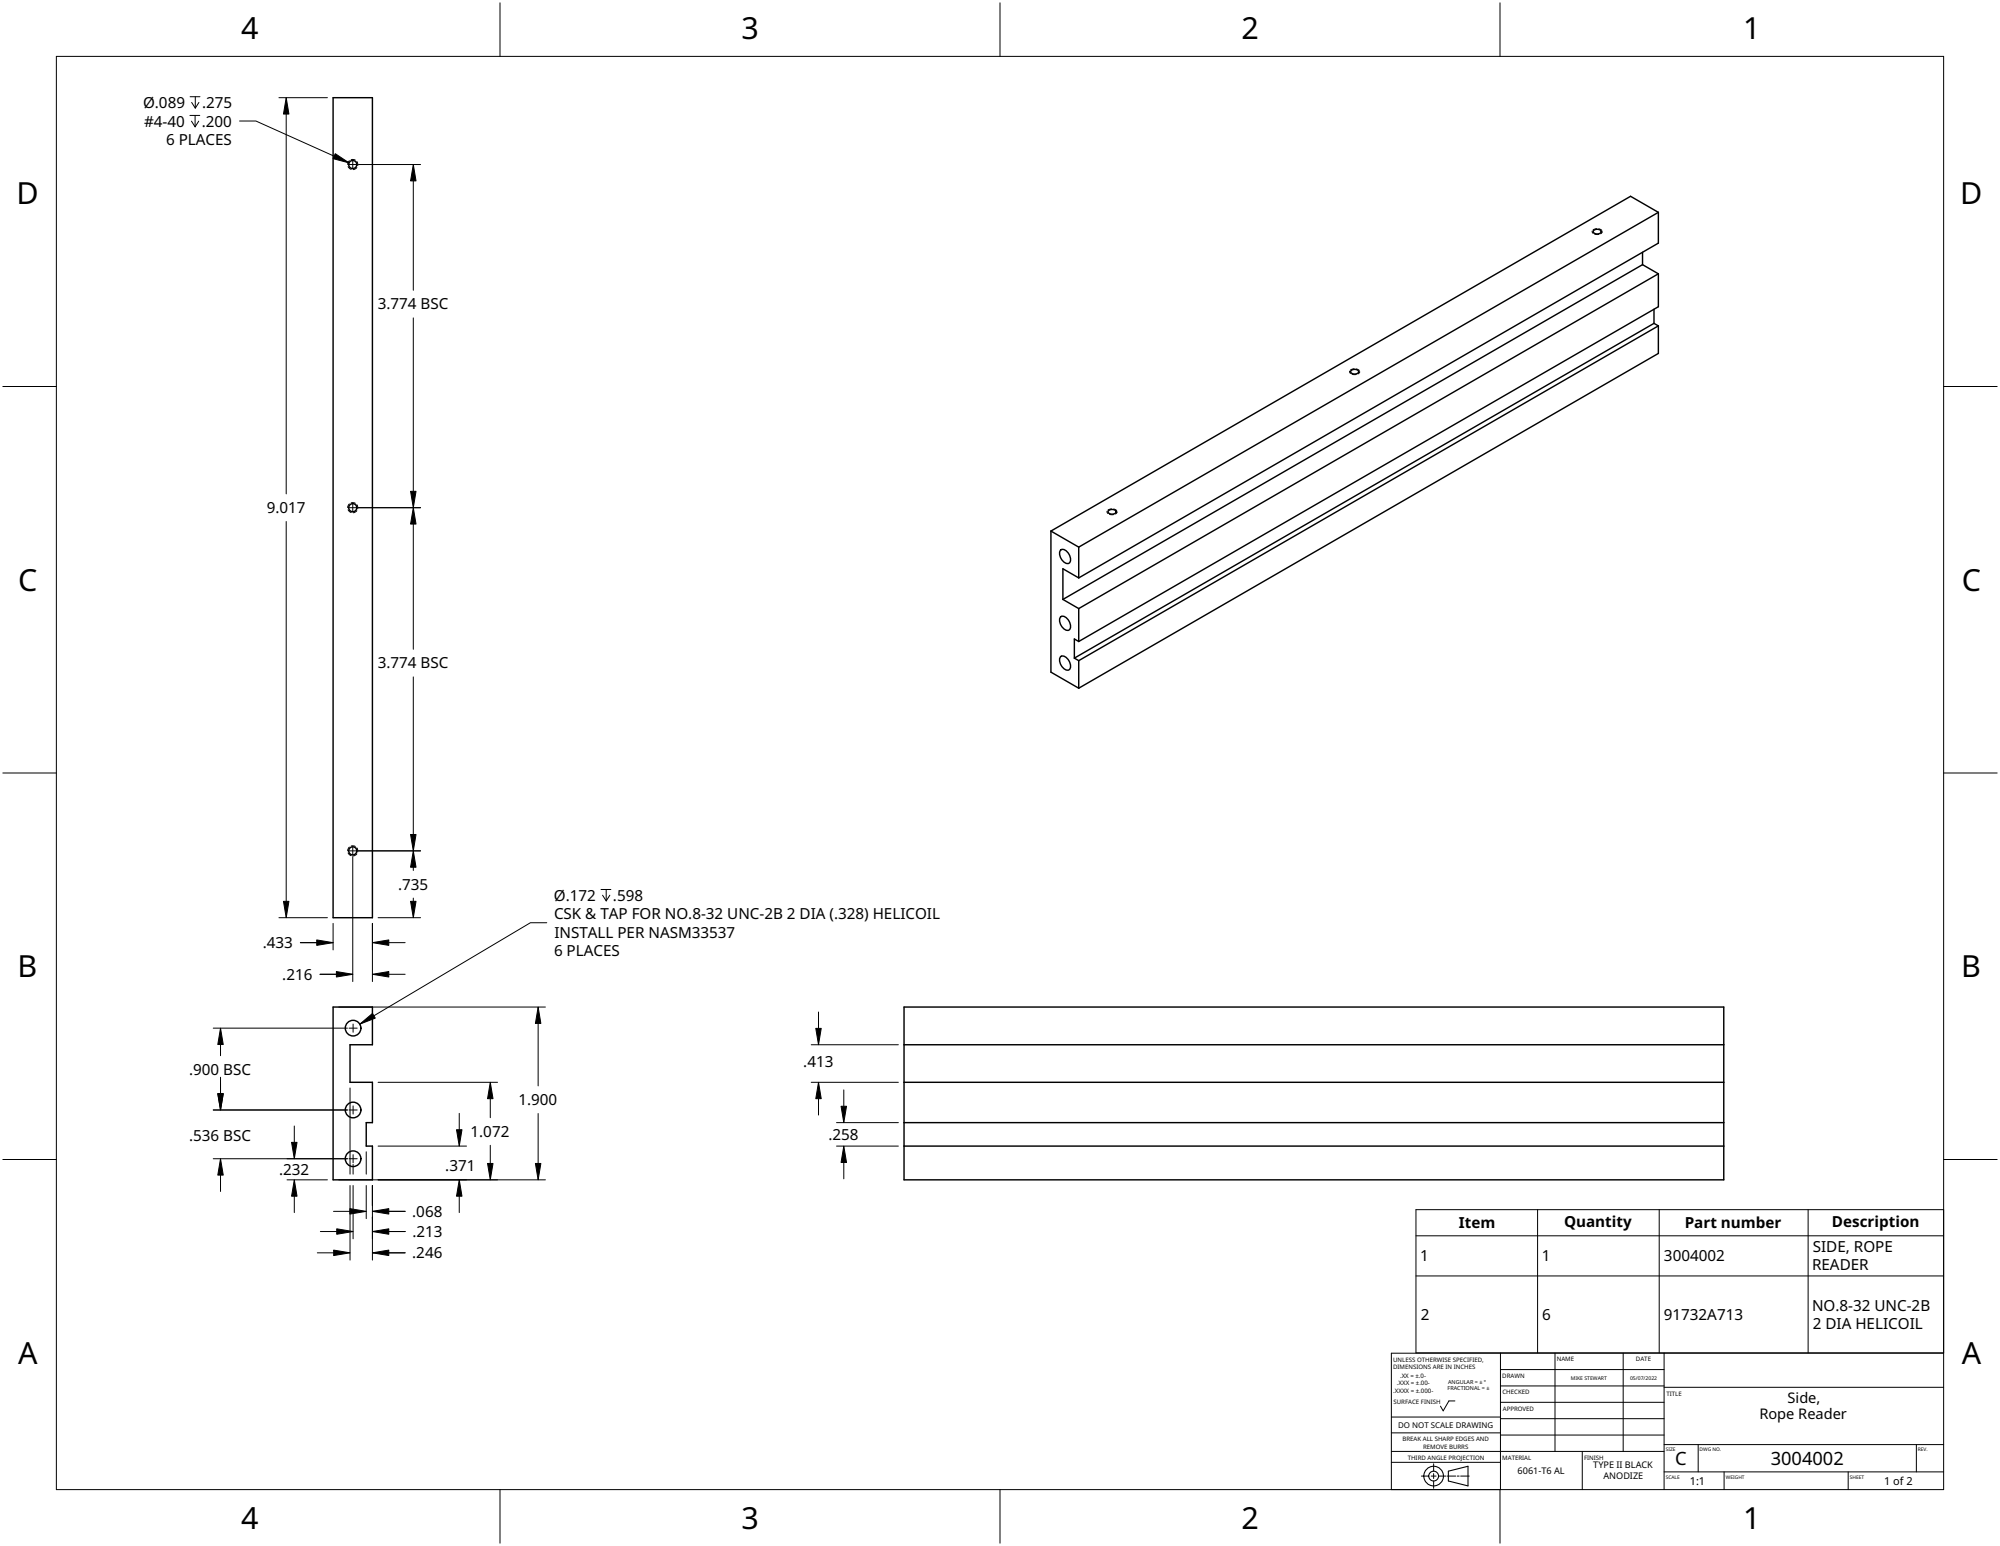
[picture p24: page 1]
MATERIAL 6061-T6 AL; Ø.089 x.275 #4-40 x.200 6 PLACES; .536 BSC; .900 BSC; 3.774 BSC

CSK & TAP FOR NO.8-32 UNC-2B 2 DIA (.328) HELICOIL
INSTALL PER NASM33537
6 PLACES

Item | Quantity | Part number | Description
1 | 1 | 3004002 | SIDE, ROPE READER

2 | 6 | 91732A713 | NO.8-32 UNC-2B 2 DIA HELICOIL

UNLESS OTHERWISE SPECIFIED, DIMENSIONS ARE IN INCHES .XX = ±.0-.XXX = ±.00-ANGULAR = ± ° .XXXX = ±.000-FRACTIONAL = ± SURFACE FINISH | | NAME | DATE

DRAWN | MIKE STEWART | 05/07/2022

CHECKED | | | TITLE Side, Rope Reader

APPROVED

DO NOT SCALE DRAWING

BREAK ALL SHARP EDGES AND

REMOVE BURRS
THIRD ANGLE PROJECTION

SIZE C | DWG NO. 3004002 | REV.

FINISH
TYPE II BLACK
ANODIZE

SCALE 1:1 | WEIGHT | SHEET

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

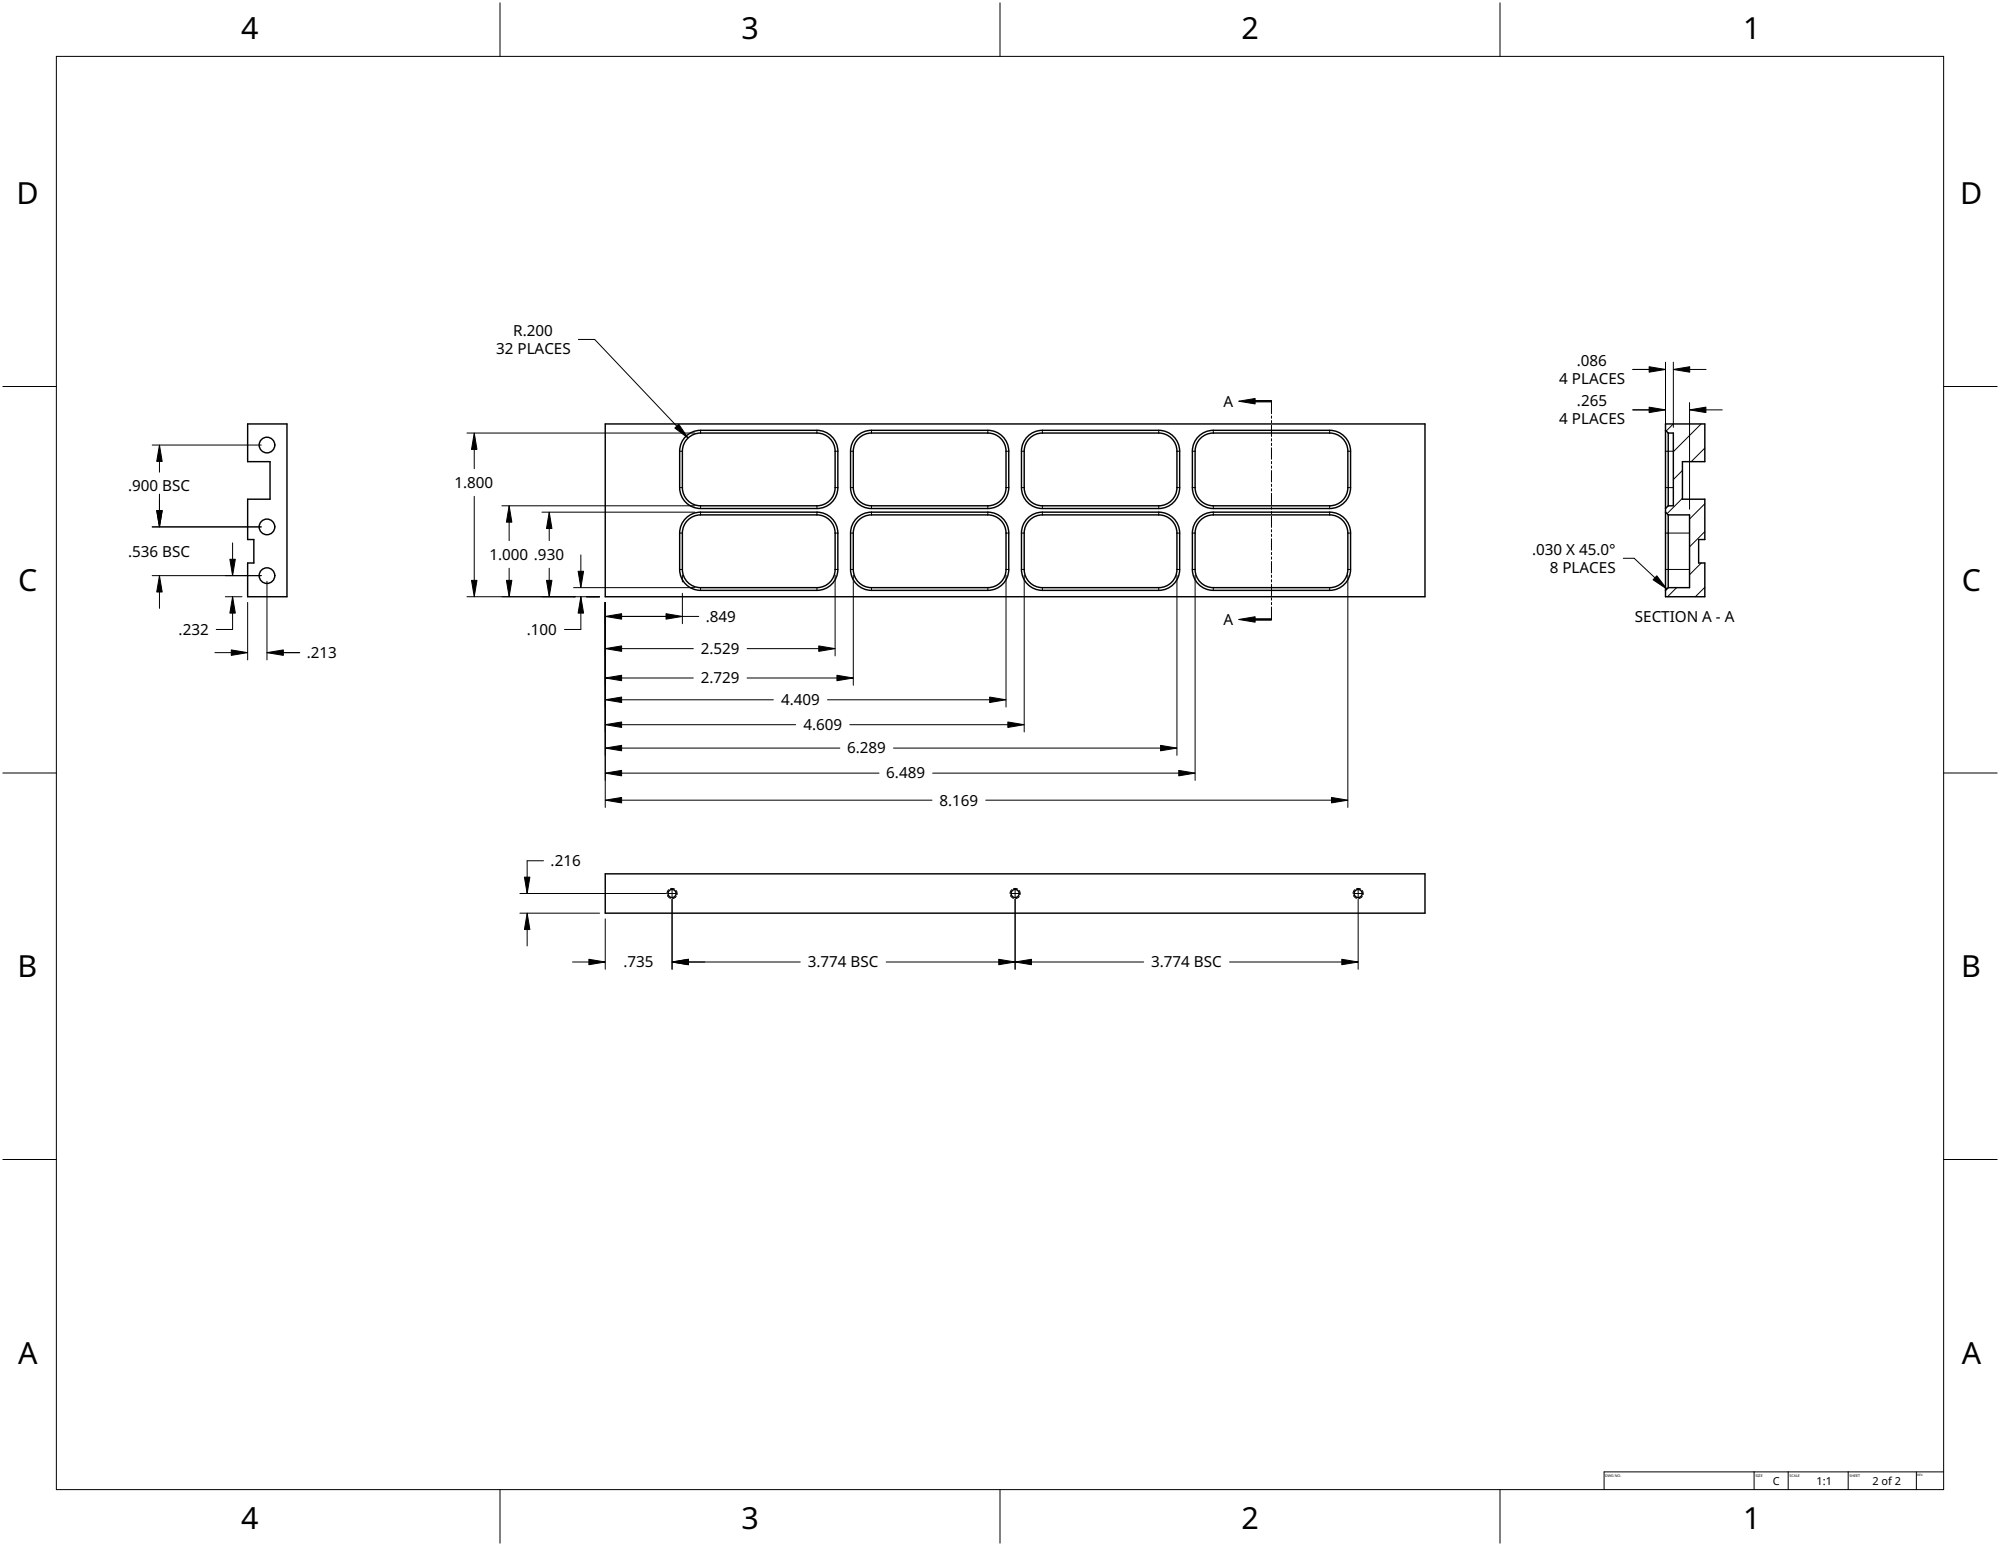
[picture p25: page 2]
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

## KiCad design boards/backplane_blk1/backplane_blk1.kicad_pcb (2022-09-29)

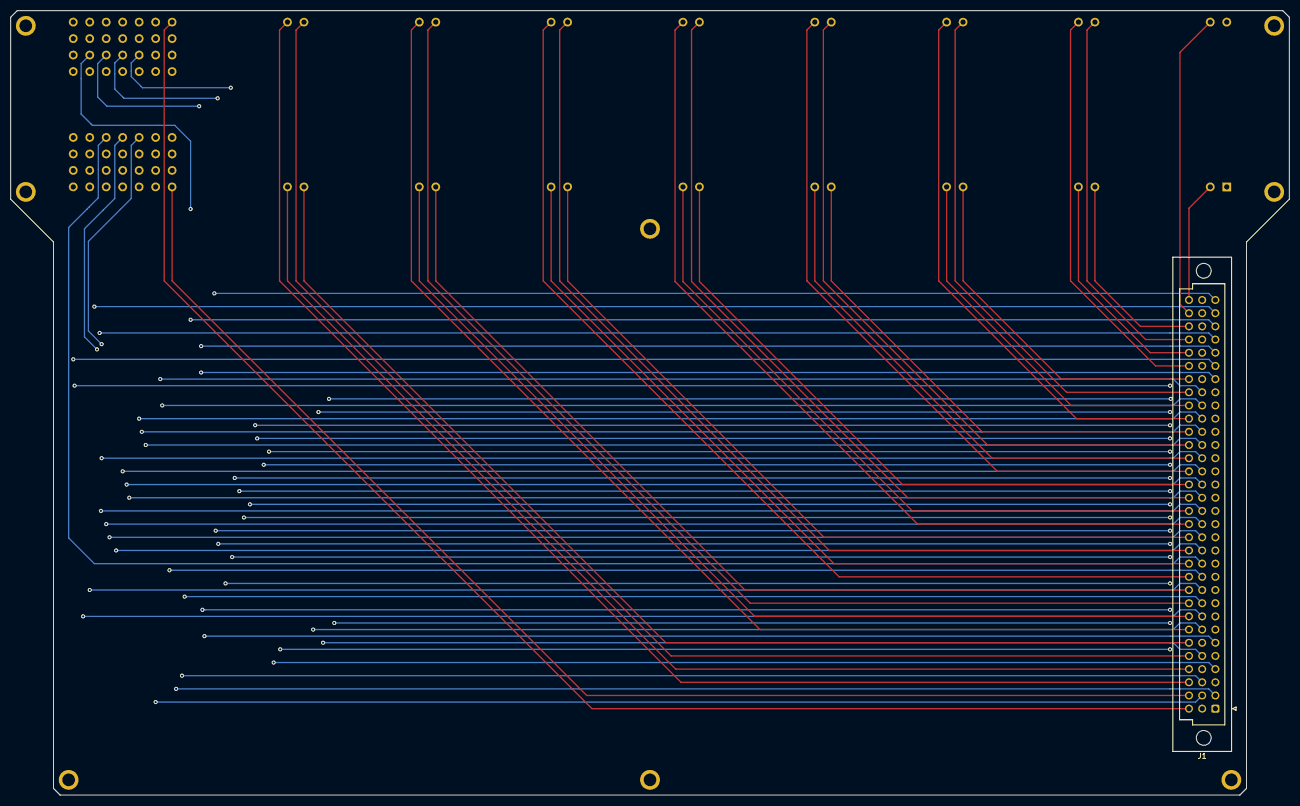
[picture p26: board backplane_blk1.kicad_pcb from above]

Board: 4 copper layers, 246.4 x 151.1 mm, 10 parts (0 on the bottom side), 83 nets.

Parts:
H1, H2, H3, H4, H5, H6, H7, H8: MountingHole_Pad; MountingHole_No2_Pad
J1: DIN41612_03x32_C; DIN41612_R_3x32_Male_Vertical_THT
J2: Conn_04x22; Block1_Connector

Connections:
/GAR01: J1.c30, J2.5
/GAR02: J1.c28, J2.7
/GAR03: J1.c26, J2.9
/GAR04: J1.c24, J2.11
/GAR05: J1.c22, J2.13
/GAR06: J1.c20, J2.15
/GAR07: J1.c18, J2.17
/GAR08: J1.c16, J2.19
/GAR09: J1.c14, J2.21
/GAR10: J1.c12, J2.23
/GAR11: J1.c10, J2.25
/GAR12: J1.c8, J2.27
/GAR13: J1.c6, J2.29
/GAR14: J1.c4, J2.31
/GAR15: J1.c32, J2.3
/GAR16: J1.c2, J2.33
/GBR01: J1.c29, J2.6
/GBR02: J1.c27, J2.8
/GBR03: J1.c25, J2.10
/GBR04: J1.c23, J2.12
/GBR05: J1.c21, J2.14
/GBR06: J1.c19, J2.16
/GBR07: J1.c17, J2.18
/GBR08: J1.c15, J2.20
/GBR09: J1.c13, J2.22
/GBR10: J1.c11, J2.24
/GBR11: J1.c9, J2.26
/GBR12: J1.c7, J2.28
/GBR13: J1.c5, J2.30
/GBR14: J1.c3, J2.32
/GBR15: J1.c31, J2.4
/GBR16: J1.c1, J2.40
/R01CD: J1.b12, J2.68
/R01FD: J1.b13, J2.67
/R02CD: J1.b14, J2.66
/R02FD: J1.b15, J2.65
/R03CD: J1.b16, J2.60
/R03FD: J1.b17, J2.59
/R04CD: J1.b18, J2.58
/R04FD: J1.b19, J2.57
/R05CD: J1.b20, J2.52
/R05FD: J1.b21, J2.51
/R06CD: J1.b22, J2.50
/R06FD: J1.b23, J2.49
/R07CD: J1.b24, J2.43
/R07FD: J1.b25, J2.42
/RPCD: J1.b8, J2.74
/RPFD: J1.b10, J2.73
/RSTR1D: J1.b2, J2.41
/SDR00: J1.b11, J2.34
/SDR01: J1.a2, J2.35
/SDR02: J1.b9, J2.36
/SDR03: J1.b3, J2.44
/SDR04: J1.b7, J2.45
/SDR05: J1.a5, J2.37
/SDR06: J1.b5, J2.38
/SDR07: J1.a7, J2.39
/SETARN: J1.a29, J2.76
/SETBRN: J1.a25, J2.82
/SETCRN: J1.a32, J2.77
/SETDRN: J1.a28, J2.87
/X01CN: J1.a10, J2.69
/X01FN: J1.a12, J2.70
/X02CN: J1.a13, J2.71
/X02FN: J1.a14, J2.72
/X03CN: J1.a15, J2.61
/X03FN: J1.a16, J2.62
/X04CN: J1.a17, J2.63
/X04FN: J1.a18, J2.64
/X05CN: J1.a19, J2.53
/X05FN: J1.a20, J2.54
/X06CN: J1.a21, J2.55
/X06FN: J1.a22, J2.56
/X07CN: J1.a23, J2.46
/X07FN: J1.a24, J2.47
/XPCN: J1.a6, J2.79
/XPFN: J1.a8, J2.80
/XRST1N: J1.a4, J2.48
/XSETAD: J1.a31, J2.75
/XSETBD: J1.a27, J2.81
/XSETCD: J1.a30, J2.78
/XSETDD: J1.a26, J2.88
GND: H1.1, H2.1, H3.1, H4.1, H5.1, H6.1, H7.1, H8.1, J1.b26, J1.b27, J1.b28, J1.b29, J1.b30, J1.b31, J1.b32

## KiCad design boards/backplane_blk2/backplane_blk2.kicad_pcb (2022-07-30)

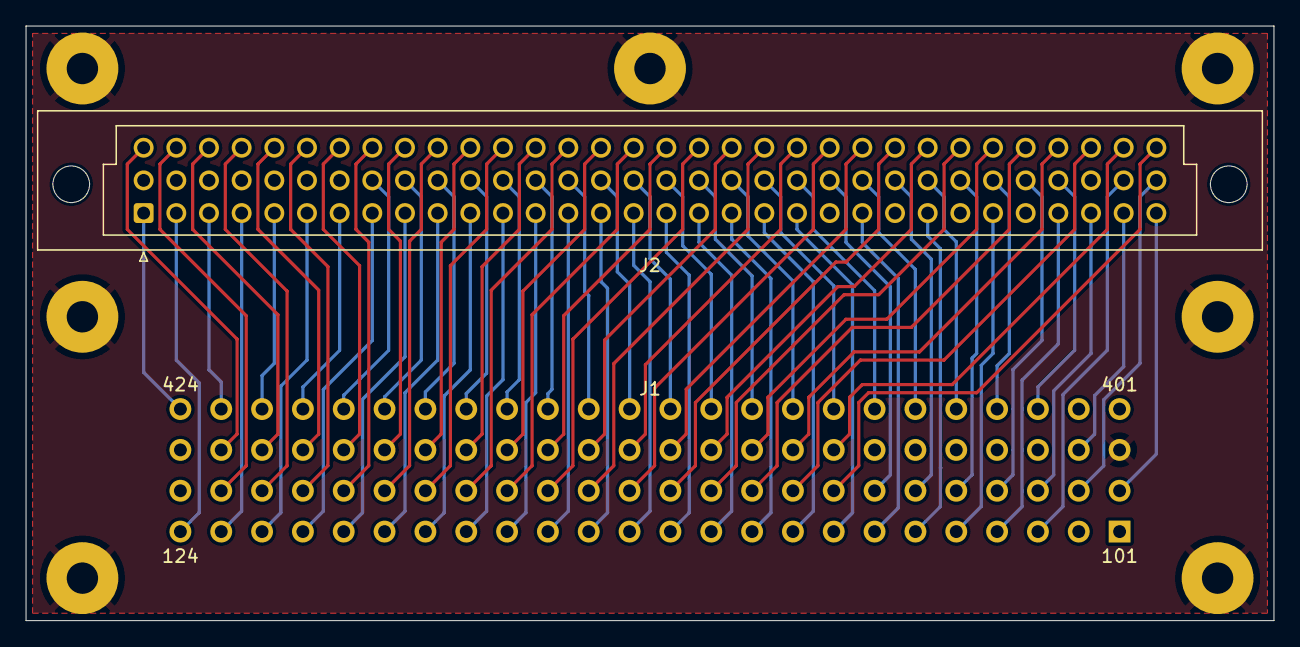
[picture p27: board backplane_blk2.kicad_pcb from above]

Board: 4 copper layers, 97.0 x 46.2 mm, 9 parts (0 on the bottom side), 90 nets.

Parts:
H1, H2, H3, H4, H5, H6, H7: MountingHole_Pad; MountingHole_No2_0.22in_Pad
J1: Conn_04x24; Rope_Connector
J2: DIN41612_03x32_C; DIN41612_C_3x32_Female_Vertical_THT

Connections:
/GAR01: J1.322, J2.c3
/GAR02: J1.321, J2.c5
/GAR03: J1.320, J2.c7
/GAR04: J1.319, J2.c9
/GAR05: J1.318, J2.c11
/GAR06: J1.317, J2.c13
/GAR07: J1.316, J2.c15
/GAR08: J1.315, J2.c17
/GAR09: J1.314, J2.c19
/GAR10: J1.313, J2.c21
/GAR11: J1.312, J2.c23
/GAR12: J1.311, J2.c25
/GAR13: J1.310, J2.c27
/GAR14: J1.309, J2.c29
/GAR15: J1.323, J2.c1
/GAR16: J1.308, J2.c31
/GBR01: J1.222, J2.c4
/GBR02: J1.221, J2.c6
/GBR03: J1.220, J2.c8
/GBR04: J1.219, J2.c10
/GBR05: J1.218, J2.c12
/GBR06: J1.217, J2.c14
/GBR07: J1.216, J2.c16
/GBR08: J1.215, J2.c18
/GBR09: J1.214, J2.c20
/GBR10: J1.213, J2.c22
/GBR11: J1.212, J2.c24
/GBR12: J1.211, J2.c26
/GBR13: J1.210, J2.c28
/GBR14: J1.209, J2.c30
/GBR15: J1.223, J2.c2
/GBR16: J1.208, J2.c32
/MODR1: J1.201, J2.a32
/R01CD: J1.407, J2.b21
/R01FD: J1.408, J2.b20
/R02CD: J1.409, J2.b19
/R02FD: J1.410, J2.b18
/R03CD: J1.411, J2.b17
/R03FD: J1.412, J2.b16
/R04CD: J1.413, J2.b15
/R04FD: J1.414, J2.b14
/R05CD: J1.415, J2.b13
/R05FD: J1.416, J2.b12
/R06CD: J1.417, J2.b11
/R06FD: J1.418, J2.b10
/R07CD: J1.419, J2.b9
/R07FD: J1.420, J2.b8
/RPCD: J1.405, J2.b25
/RPFD: J1.406, J2.b23
/RSTRAD: J1.123, J2.a4
/RSTRBD: J1.121, J2.a8
/RSTRCD: J1.424, J2.a1
/RSTRDD: J1.422, J2.a5
/SETARN: J1.103, J2.b31
/SETCRN: J1.404, J2.b27
/STR01: J1.207, J2.b22
/STR02: J1.302, J2.a31
/STR03: J1.206, J2.b24
/STR04: J1.303, J2.b30
/STR05: J1.205, J2.b26
/STR06: J1.304, J2.a28
/STR07: J1.204, J2.b28
/STR08: J1.305, J2.a26
/STR09: J1.203, J2.a30
/STR10: J1.306, J2.a24
/STR11: J1.202, J2.b32
/STR12: J1.307, J2.a22
/X01CN: J1.107, J2.a23
/X01FN: J1.108, J2.a21
/X02CN: J1.109, J2.a20
/X02FN: J1.110, J2.a19
/X03CN: J1.111, J2.a18
/X03FN: J1.112, J2.a17
/X04CN: J1.113, J2.a16
/X04FN: J1.114, J2.a15
/X05CN: J1.115, J2.a14
/X05FN: J1.116, J2.a13
/X06CN: J1.117, J2.a12
/X06FN: J1.118, J2.a11
/X07CN: J1.119, J2.a10
/X07FN: J1.120, J2.a9
/XPCN: J1.105, J2.a27
/XPFN: J1.106, J2.a25
/XRSTAN: J1.124, J2.a2
/XRSTBN: J1.122, J2.a6
/XRSTCN: J1.423, J2.a3
/XRSTDN: J1.421, J2.a7
/XSETAB: J1.104, J2.a29
/XSETCD: J1.403, J2.b29
GND: H1.1, H2.1, H3.1, H4.1, H5.1, H6.1, H7.1, J1.301, J2.b1, J2.b2, J2.b3, J2.b4, J2.b5, J2.b6, J2.b7

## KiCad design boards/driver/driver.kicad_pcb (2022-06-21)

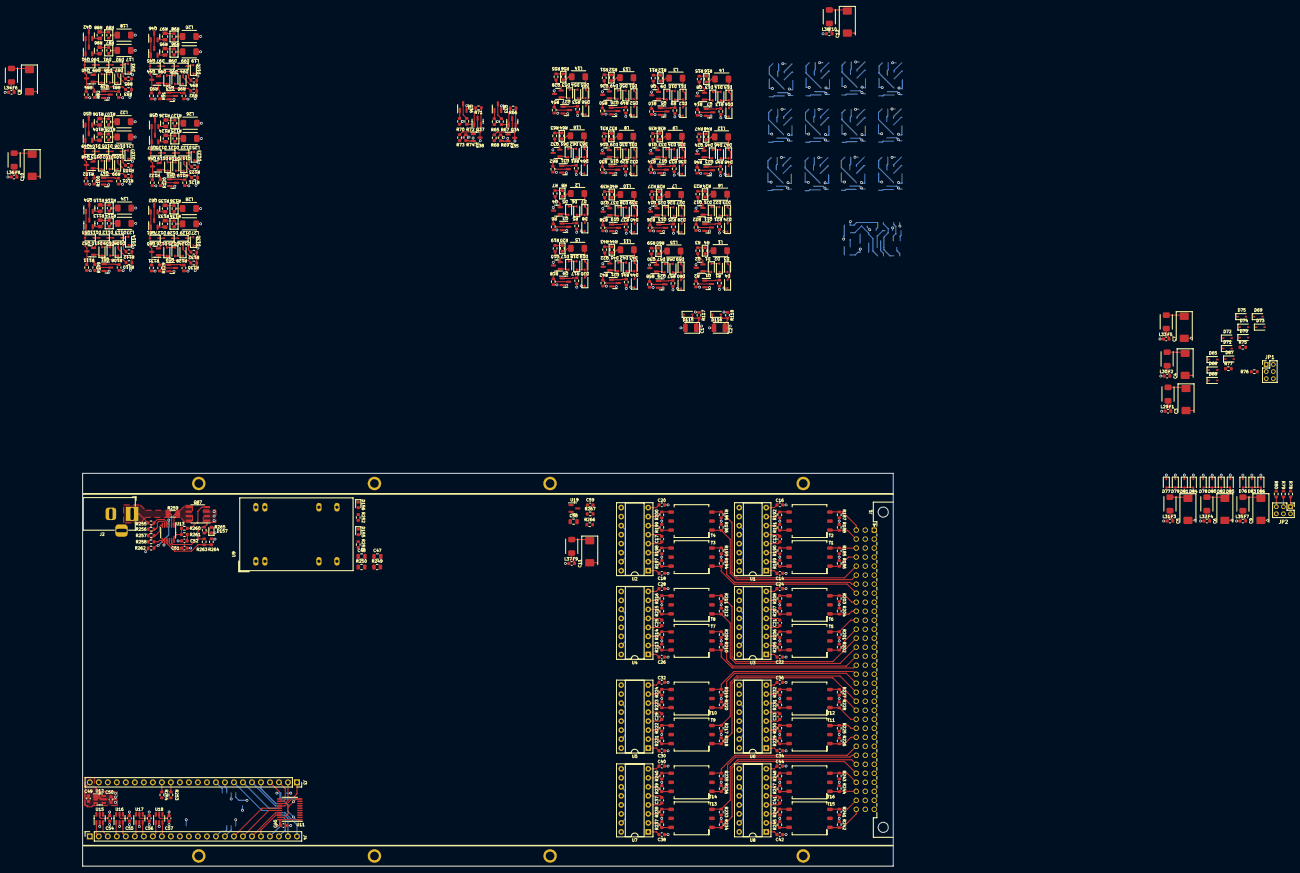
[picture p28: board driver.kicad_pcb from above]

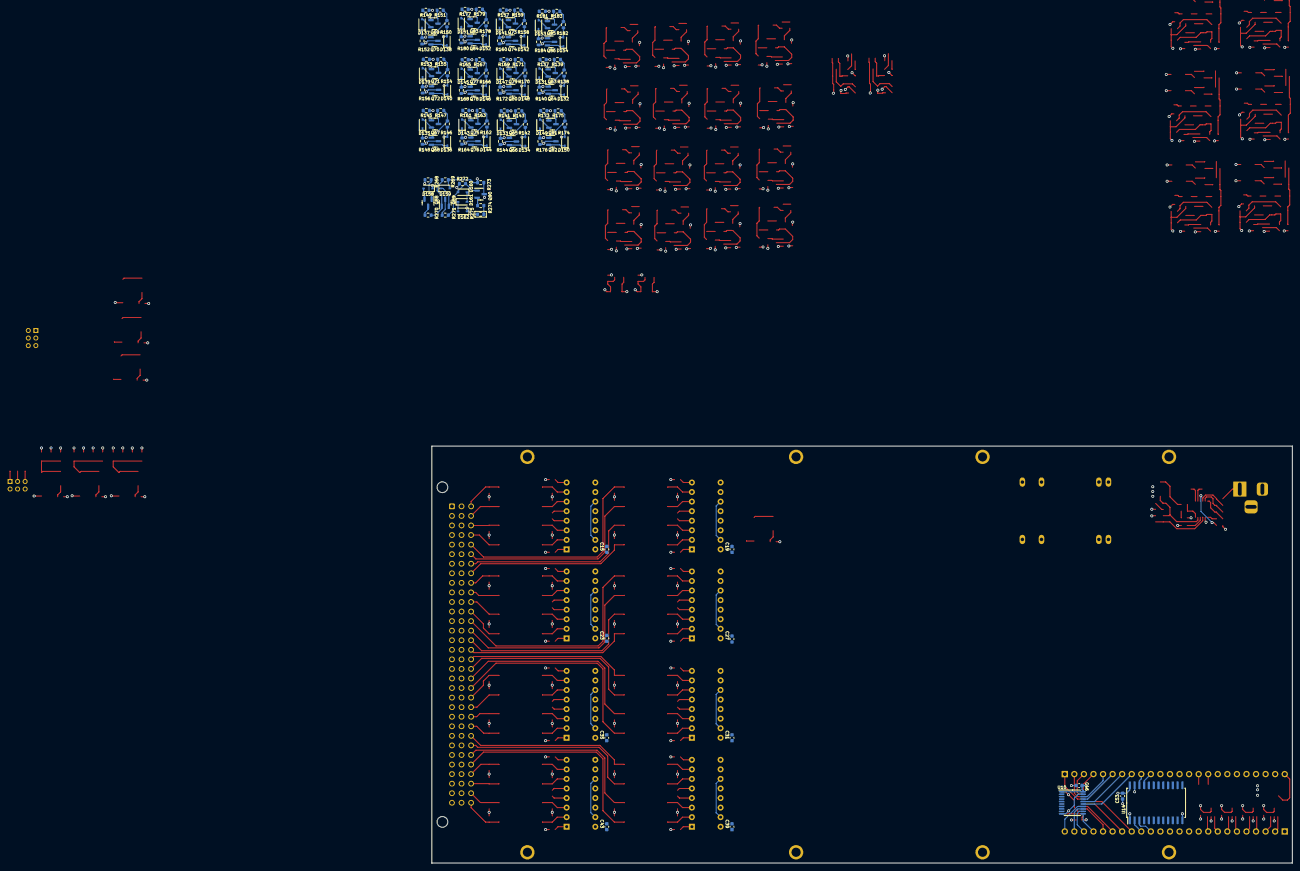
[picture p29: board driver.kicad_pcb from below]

Board: 6 copper layers, 228.6 x 110.7 mm, 683 parts (124 on the bottom side), 562 nets.

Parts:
C1, C2: 1.0uF; CP_EIA-3528-21_Kemet-B
C3, C4, C5, C6, C7, C8, C9, C10, C11, C12: 6.8uF; CP_EIA-7343-31_Kemet-D
C13, C15, C16, C17, C19, C20, C21, C23, C24, C25, C27, C28, C29, C31, C32, C33, C35, C36, C37, C39, C40, C41, C43, C44, C52: 0.01uF; C_0603_1608Metric
C14, C18, C22, C26, C30, C34, C38, C42, C51: 100pF; C_0603_1608Metric
C45, C46, C53, C54, C55, C56, C57: 0.1uF; C_0603_1608Metric
C47, C48: 1.0uF; C_0805_2012Metric
C49, C50, C59: 1.0uF; C_0603_1608Metric
C58: 4.7uF; C_0805_2012Metric
D1, D2, D3, D4, D5, D6, D7, D8, D9, D10, D11, D12, D13, D14, D15, D16, D17, D18, D19, D20, D21, D22, D23, D24, D25, D26, D27, D28, D29, D30, D31, D32, D33, D34, D35, D36, D37, D38, D39, D40, D41, D42, D43, D44, D45, D46, D47, D48, D49, D50, D51, D52, D53, D54, D55, D56, D57, D58, D59, D60, D61, D62, D63, D64, D65, D66, D67, D68, D69, D70, D71, D72, D73, D74, D75, D76, D77, D78, D79, D80, D81, D82, D83, D84, D85, D86, D87, D88, D89, D90, D91, D92, D93, D94, D95, D96, D97, D98, D99, D100, D101, D102, D103, D104, D105, D106, D107, D108, D109, D110, D111, D112, D113, D114, D115, D116, D117, D118, D119, D120, D121, D122, D123, D124, D125, D126, D127, D128, D129, D130, D131, D132, D133, D134, D135, D136, D137, D138, D139, D140, D141, D142, D143, D144, D145, D146, D147, D148, D149, D150, D151, D152, D153, D154, D158, D159, D160, D161, D162: 1N4148; D_SOD-323
D155: BLUE; LED_0603_1608Metric
D156: TEAL; LED_0603_1608Metric
D157: ORANGE; LED_0603_1608Metric
F1, F2, F3, F4, F5, F6, F7, F8, F9, F10: 250mA; Fuse_0603_1608Metric
H1, H2, H3, H4, H5, H6, H7, H8: MountingHole_Pad; MountingHole_No2_Pad
J1: DIN41612_03x32_C; DIN41612_C_3x32_Male_Horizontal_THT
J2: Barrel_Jack_Switch; BarrelJack_CUI_PJ-002A
J3, J4: Conn_01x24; PinSocket_1x24_P2.54mm_Vertical
JP1, JP2: Conn_02x03_Odd_Even; PinHeader_2x03_P2.00mm_Vertical
L1, L2, L3, L4, L5, L6, L7, L8, L9, L10, L11, L12, L13, L14, L15, L16: 2.2uH; API_Delevan_1812R
L17, L18, L19, L20, L21, L22, L23, L24, L25, L26, L27, L28: 3.9uH; API_Delevan_1812R
L29, L30, L31, L32, L33, L34, L35, L36, L37, L38: 8.2uH; API_Delevan_1812R
Q1, Q2, Q3, Q4, Q5, Q6, Q7, Q8, Q9, Q10, Q11, Q12, Q13, Q14, Q15, Q16, Q17, Q18, Q19, Q20, Q21, Q22, Q23, Q24, Q25, Q26, Q27, Q28, Q29, Q30, Q31, Q32, Q33, Q35, Q36, Q38, Q39, Q41, Q42, Q43, Q45, Q46, Q47, Q49, Q50, Q51, Q53, Q54, Q55, Q57, Q58, Q59, Q61, Q62, Q63, Q65, Q67, Q69, Q71, Q73, Q75, Q77, Q79, Q81, Q83, Q85, Q88, Q90: MMBT2222; SOT-23
Q34, Q37, Q40, Q44, Q48, Q52, Q56, Q60, Q64, Q66, Q68, Q70, Q72, Q74, Q76, Q78, Q80, Q82, Q84, Q86, Q89: MMBT2907; SOT-23
Q87: IRF7413; SO-8_3.9x4.9mm_P1.27mm
R1, R5, R9, R13, R17, R21, R25, R29, R33, R37, R41, R45, R49, R53, R57, R61, R65, R70, R81, R82, R90, R91, R99, R100, R108, R109, R119, R120, R128, R129, R137, R141, R145, R149, R153, R157, R161, R165, R169, R173, R177, R181, R261, R265, R268: 1k; R_0603_1608Metric
R2, R6, R10, R14, R18, R22, R26, R30, R34, R38, R42, R46, R50, R54, R58, R62: 390; R_0603_1608Metric
R3, R7, R11, R15, R19, R23, R27, R31, R35, R39, R43, R47, R51, R55, R59, R63: 4.7; R_0603_1608Metric
R4, R8, R12, R16, R20, R24, R28, R32, R36, R40, R44, R48, R52, R56, R60, R64, R87, R89, R96, R98, R105, R107, R114, R116, R125, R127, R134, R136, R275: NOM; R_0603_1608Metric
R66, R71: 470; R_0603_1608Metric
R67, R69, R72, R74, R139, R143, R147, R151, R155, R159, R163, R167, R171, R175, R179, R183, R251, R252: 2k; R_0603_1608Metric
R68, R73: 750; R_0603_1608Metric
R75, R76, R77, R78, R79, R80: 200; R_0603_1608Metric
R83, R84, R92, R93, R101, R102, R110, R111, R121, R122, R130, R131, R138, R142, R146, R150, R154, R158, R162, R166, R170, R174, R178, R182, R269, R270, R272: 5.1k; R_0603_1608Metric
R85, R94, R103, R112, R123, R132: 27; R_0603_1608Metric
R86, R88, R95, R97, R104, R106, R113, R115, R124, R126, R133, R135: 7.5; R_0805_2012Metric
R117, R118, R140, R144, R148, R152, R156, R160, R164, R168, R172, R176, R180, R184, R273: 3k; R_0603_1608Metric
R185, R186, R187, R188, R193, R194, R195, R196, R201, R202, R203, R204, R209, R210, R211, R212, R217, R218, R219, R220, R225, R226, R227, R228, R233, R234, R235, R236, R241, R242, R243, R244: 2.7k; R_0603_1608Metric
R189, R190, R191, R192, R197, R198, R199, R200, R205, R206, R207, R208, R213, R214, R215, R216, R221, R222, R223, R224, R229, R230, R231, R232, R237, R238, R239, R240, R245, R246, R247, R248: 100; R_0603_1608Metric
R249, R250: 0; R_0805_2012Metric
R253: 12k; R_0603_1608Metric
R254: 2.4k; R_0603_1608Metric
R255: 1020k; R_0603_1608Metric
R256: 2.87k; R_0603_1608Metric
R257: 9.76k; R_0603_1608Metric
R258: 54.9k; R_0603_1608Metric
R259: 0.025; R_1206_3216Metric
R260, R274: 10; R_0603_1608Metric
R262, R263: 10k; R_0603_1608Metric
R264: 2.5k; R_0603_1608Metric
R266: 1.27k; R_0603_1608Metric
R267: 249; R_0603_1608Metric
R271: 680; R_0603_1608Metric
T1, T2, T3, T4, T5, T6, T7, T8, T9, T10, T11, T12, T13, T14, T15, T16: 1:1; Transformer_Murata_786J
U1, U2, U3, U4, U5, U6, U7, U8: SN7524; DIP-16_W7.62mm_Socket
U9: JTE0624D05; Converter_DCDC_XP_POWER_JTExxxxDxx_THT
U10, U11: 74LVC245; TSSOP-20_4.4x6.5mm_P0.65mm
U12: ADP151-3.3; TSOT-23-5
U13: LTC4231-1; MSOP-12_3x4mm_P0.65mm
U14: 74HC4514; SOIC-24W_7.5x15.4mm_P1.27mm
U15, U16, U17, U18: 74LVC2G04; SOT-23-6
U19: AD1582BRTZ; SOT-23

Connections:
+3V3: C45.2, C46.2, C50.1, C53.2, C54.1, C55.1, C56.1, C57.1, U10.1 (A->B), U10.20 (VCC), U11.1 (A->B), U11.20 (VCC), U12.5 (VOUT), U14.1 (~LE), U14.24 (VCC), U15.5 (VCC), U16.5 (VCC), U17.5 (VCC), U18.5 (VCC)
+5V: C15.1, C19.1, C23.1, C27.1, C31.1, C35.1, C39.1, C43.1, C48.1, C58.2, R249.1, R252.1, R254.2, U1.16 (VCC+), U2.16 (VCC+), U3.16 (VCC+), U4.16 (VCC+), U5.16 (VCC+), U6.16 (VCC+), U7.16 (VCC+), U8.16 (VCC+), U19.3 (VIN)
+14V: F1.2, F2.2, F3.2, F4.2, F5.2, F6.2, F7.2, F8.2, F9.2, F10.2, Q87.1 (S), Q87.2 (S), Q87.3 (S), R117.2, R118.2, R263.1, R265.1, U13.11 (SOURCE)
-5V: C16.2, C20.2, C24.2, C28.2, C32.2, C36.2, C40.2, C44.2, C47.2, R250.1, R251.1, U1.8 (VCC-), U2.8 (VCC-), U3.8 (VCC-), U4.8 (VCC-), U5.8 (VCC-), U6.8 (VCC-), U7.8 (VCC-), U8.8 (VCC-)
/Connector/GAR1: J1.c3, R185.1, T1.3 (P2)
/Connector/GAR2: J1.c5, R195.1, T4.3 (P2)
/Connector/GAR3: J1.c7, R193.1, T3.3 (P2)
/Connector/GAR4: J1.c9, R203.1, T6.3 (P2)
/Connector/GAR5: J1.c11, R201.1, T5.3 (P2)
/Connector/GAR6: J1.c13, R211.1, T8.3 (P2)
/Connector/GAR7: J1.c15, R209.1, T7.3 (P2)
/Connector/GAR8: J1.c17, R219.1, T10.3 (P2)
/Connector/GAR9: J1.c19, R217.1, T9.3 (P2)
/Connector/GAR10: J1.c21, R227.1, T12.3 (P2)
/Connector/GAR11: J1.c23, R225.1, T11.3 (P2)
/Connector/GAR12: J1.c25, R235.1, T14.3 (P2)
/Connector/GAR13: J1.c27, R233.1, T13.3 (P2)
/Connector/GAR14: J1.c29, R243.1, T16.3 (P2)
/Connector/GAR15: J1.c1, R187.1, T2.3 (P2)
/Connector/GAR16: J1.c31, R241.1, T15.3 (P2)
/Connector/GBR1: J1.c4, R186.2, T1.1
/Connector/GBR2: J1.c6, R196.2, T4.1
/Connector/GBR3: J1.c8, R194.2, T3.1
/Connector/GBR4: J1.c10, R204.2, T6.1
/Connector/GBR5: J1.c12, R202.2, T5.1
/Connector/GBR6: J1.c14, R212.2, T8.1
/Connector/GBR7: J1.c16, R210.2, T7.1
/Connector/GBR8: J1.c18, R220.2, T10.1
/Connector/GBR9: J1.c20, R218.2, T9.1
/Connector/GBR10: J1.c22, R228.2, T12.1
/Connector/GBR11: J1.c24, R226.2, T11.1
/Connector/GBR12: J1.c26, R236.2, T14.1
/Connector/GBR13: J1.c28, R234.2, T13.1
/Connector/GBR14: J1.c30, R244.2, T16.1
/Connector/GBR15: J1.c2, R188.2, T2.1
/Connector/GBR16: J1.c32, R242.2, T15.1
/Connector/MODR1: J1.b5, Q90.3 (C), R273.2
/Connector/RCD1: D68.1 (K), J1.b25
/Connector/RCD2: D73.1 (K), J1.b26
/Connector/RCD3: D69.1 (K), J1.b27
/Connector/RCD4: D74.1 (K), J1.b28
/Connector/RCD5: D79.1 (K), J1.b29
/Connector/RCD6: D84.1 (K), J1.b30
/Connector/RCD7: D80.1 (K), J1.b31
/Connector/RCD8: D85.1 (K), J1.b32
/Connector/RFD1: D66.1 (K), J1.a25
/Connector/RFD2: D70.1 (K), J1.a26
/Connector/RFD3: D67.1 (K), J1.a27
/Connector/RFD4: D71.1 (K), J1.a28
/Connector/RFD5: D77.1 (K), J1.a29
/Connector/RFD6: D81.1 (K), J1.a30
/Connector/RFD7: D78.1 (K), J1.a31
/Connector/RFD8: D82.1 (K), J1.a32
/Connector/RSTRD1: D83.1 (K), J1.b1, R79.2
/Connector/RSTRD2: D76.1 (K), J1.b2, R78.2
/Connector/RSTRD3: D72.1 (K), J1.b3, R76.2
/Connector/RSTRD4: D65.1 (K), J1.b4, R75.2
/Connector/SETRN1: D75.1 (K), J1.a23, R77.2
/Connector/SETRN2: D86.1 (K), J1.a24, R80.2
/Connector/STR1: J1.b8, Q64.3 (C), R140.1
/Connector/STR2: J1.b9, Q66.3 (C), R144.1
/Connector/STR3: J1.b10, Q68.3 (C), R148.1
/Connector/STR4: J1.b11, Q70.3 (C), R152.1
/Connector/STR5: J1.b12, Q72.3 (C), R156.1
/Connector/STR6: J1.b13, Q74.3 (C), R160.1
/Connector/STR7: J1.b14, Q76.3 (C), R164.1
/Connector/STR8: J1.b15, Q78.3 (C), R168.1
/Connector/STR9: J1.b16, Q80.3 (C), R172.1
/Connector/STR10: J1.b17, Q82.3 (C), R176.1
/Connector/STR11: J1.b18, Q84.3 (C), R180.1
/Connector/STR12: J1.b19, Q86.3 (C), R184.1
/Connector/XCN1: J1.a15, Q4.3 (C)
/Connector/XCN2: J1.a16, Q8.3 (C)
/Connector/XCN3: J1.a17, Q12.3 (C)
/Connector/XCN4: J1.a18, Q30.3 (C)
/Connector/XCN5: J1.a19, Q20.3 (C)
/Connector/XCN6: J1.a20, Q24.3 (C)
/Connector/XCN7: J1.a21, Q28.3 (C)
/Connector/XCN8: J1.a22, Q32.3 (C)
/Connector/XFN1: J1.a7, Q2.3 (C)
/Connector/XFN2: J1.a8, Q6.3 (C)
/Connector/XFN3: J1.a9, Q10.3 (C)
/Connector/XFN4: J1.a10, Q14.3 (C)
/Connector/XFN5: J1.a11, Q18.3 (C)
/Connector/XFN6: J1.a12, Q22.3 (C)
/Connector/XFN7: J1.a13, Q26.3 (C)
/Connector/XFN8: J1.a14, Q16.3 (C)
/Connector/XRST1: J1.a3, JP2.4, Q45.3 (C), Q46.3 (C)
/Connector/XRST2: J1.a4, JP2.2, Q53.3 (C), Q54.3 (C)
/Connector/XRST3: J1.a5, JP1.4, Q57.3 (C), Q58.3 (C)
/Connector/XRST4: J1.a6, JP1.2, Q61.3 (C), Q62.3 (C)
/Connector/XSET1: J1.a1, JP1.6, Q41.3 (C), Q42.3 (C)
/Connector/XSET2: J1.a2, JP2.6, Q49.3 (C), Q50.3 (C)
/FPGA and Power/5V_FPGA: C49.2, J3.24, U12.1 (VIN), U12.3 (EN)
/FPGA and Power/14V_IN: J2.1, R253.2, R255.2, R259.2, U9.22 (VIN+), U9.23 (VIN+), U13.2 (IN)
/FPGA and Power/14V_SENSE: Q87.5 (D), Q87.6 (D), Q87.7 (D), Q87.8 (D), R259.1, U13.1 (SENSE)
/FPGA and Power/ADC_5V: J3.16, R254.1
/FPGA and Power/ADC_14V: J3.15, R253.1
/FPGA and Power/EN_14V: J3.17, R262.1, U13.3 (~SHDN)
/FPGA and Power/IHENV: J4.14, R65.2, R70.2
/FPGA and Power/IL1: J4.2, R1.2, U15.1
/FPGA and Power/IL2: J4.3, R9.2, U15.3
/FPGA and Power/IL3: J4.4, R17.2, U16.1
/FPGA and Power/IL4: J4.5, R25.2, U16.3
/FPGA and Power/IL5: J4.6, R33.2, U17.1
/FPGA and Power/IL6: J4.7, R41.2, U17.3
/FPGA and Power/IL7: J4.8, R49.2, U18.1
/FPGA and Power/IL8: J4.9, R29.2, U18.3
/FPGA and Power/PG_14V: J3.18, R263.2, R264.1, U13.9 (STATUS)
/FPGA and Power/RESET1: J4.12, R90.2
/FPGA and Power/RESET2: J3.11, R108.2
/FPGA and Power/RESET3: J3.12, R119.2
/FPGA and Power/RESET4: J4.11, R128.2
/FPGA and Power/ROPER: J3.13, R268.2
/FPGA and Power/SA1: U1.12, U10.2 (A0)
/FPGA and Power/SA2: U2.14, U10.3 (A1)
/FPGA and Power/SA3: U2.12, U10.4 (A2)
/FPGA and Power/SA4: U3.14, U10.5 (A3)
/FPGA and Power/SA5: U3.12, U10.6 (A4)
/FPGA and Power/SA6: U4.14, U10.7 (A5)
/FPGA and Power/SA7: U4.12, U10.8 (A6)
/FPGA and Power/SA8: U5.14, U10.9 (A7)
/FPGA and Power/SA9: U5.12, U11.2 (A0)
/FPGA and Power/SA10: U6.14, U11.3 (A1)
/FPGA and Power/SA11: U6.12, U11.4 (A2)
/FPGA and Power/SA12: U7.14, U11.5 (A3)
/FPGA and Power/SA13: U7.12, U11.6 (A4)
/FPGA and Power/SA14: U8.14, U11.7 (A5)
/FPGA and Power/SA15: U1.14, U11.8 (A6)
/FPGA and Power/SA16: U8.12, U11.9 (A7)
/FPGA and Power/SAF1: J3.5, U10.18 (B0)
/FPGA and Power/SAF2: J3.6, U10.17 (B1)
/FPGA and Power/SAF3: J3.7, U10.16 (B2)
/FPGA and Power/SAF4: J3.8, U10.15 (B3)
/FPGA and Power/SAF5: J4.24, U10.14 (B4)
/FPGA and Power/SAF6: J4.23, U10.13 (B5)
/FPGA and Power/SAF7: J4.22, U10.12 (B6)
/FPGA and Power/SAF8: J4.21, U10.11 (B7)
/FPGA and Power/SAF9: J4.20, U11.18 (B0)
/FPGA and Power/SAF10: J4.19, U11.17 (B1)
/FPGA and Power/SAF11: J4.18, U11.16 (B2)
/FPGA and Power/SAF12: J4.17, U11.15 (B3)
/FPGA and Power/SAF13: J3.1, U11.14 (B4)
/FPGA and Power/SAF14: J3.2, U11.13 (B5)
/FPGA and Power/SAF15: J3.3, U11.12 (B6)
/FPGA and Power/SAF16: J3.4, U11.11 (B7)
/FPGA and Power/SBF: J3.19, U1.11, U1.15, U2.11, U2.15, U3.11, U3.15, U4.11, U4.15, U5.11, U5.15, U6.11, U6.15, U7.11, U7.15, U8.11, U8.15
/FPGA and Power/SE1: R137.2, U14.9 (Y1)
/FPGA and Power/SE2: R141.2, U14.10 (Y2)
/FPGA and Power/SE3: R145.2, U14.8 (Y3)
/FPGA and Power/SE4: R149.2, U14.7 (Y4)
/FPGA and Power/SE5: R153.2, U14.6 (Y5)
/FPGA and Power/SE6: R157.2, U14.5 (Y6)
/FPGA and Power/SE7: R161.2, U14.4 (Y7)
/FPGA and Power/SE8: R165.2, U14.18 (Y8)
/FPGA and Power/SE9: R169.2, U14.17 (Y9)
/FPGA and Power/SE10: R173.2, U14.20 (Y10)
/FPGA and Power/SE11: R177.2, U14.19 (Y11)
/FPGA and Power/SE12: R181.2, U14.14 (Y12)
/FPGA and Power/SET1: J3.14, R81.2
/FPGA and Power/SET2: J4.13, R99.2
/FPGA and Power/STRA0: J4.16, U14.2 (A0)
/FPGA and Power/STRA1: J4.15, U14.3 (A1)
/FPGA and Power/STRA2: J3.10, U14.21 (A2)
/FPGA and Power/STRA3: J3.9, U14.22 (A3)
/FPGA and Power/~IL1: R5.2, U15.6
/FPGA and Power/~IL2: R13.2, U15.4
/FPGA and Power/~IL3: R21.2, U16.6
/FPGA and Power/~IL4: R57.2, U16.4
/FPGA and Power/~IL5: R37.2, U17.6
/FPGA and Power/~IL6: R45.2, U17.4
/FPGA and Power/~IL7: R53.2, U18.6
/FPGA and Power/~IL8: R61.2, U18.4
/Rope Drivers/40331A: Q35.2 (E), R2.1, R6.1, R10.1, R14.1, R18.1, R22.1, R26.1, R30.1, R69.1
/Rope Drivers/40332A: Q38.2 (E), R34.1, R38.1, R42.1, R46.1, R50.1, R54.1, R58.1, R62.1, R74.1
/Rope Drivers/40365A: C1.1, D115.2 (A), Q1.2 (E), Q3.2 (E), Q5.2 (E), Q7.2 (E), Q9.2 (E), Q11.2 (E), Q13.2 (E), Q15.2 (E), Q33.2 (E), Q39.2 (E), Q43.2 (E), Q55.2 (E), R117.1
/Rope Drivers/40366A: C2.1, D116.2 (A), Q17.2 (E), Q19.2 (E), Q21.2 (E), Q23.2 (E), Q25.2 (E), Q27.2 (E), Q29.2 (E), Q31.2 (E), Q36.2 (E), Q47.2 (E), Q51.2 (E), Q59.2 (E), R118.1
/Rope Drivers/BPLIZ1: C8.1, D87.2 (A), D94.2 (A), D117.2 (A), L34.2, Q34.2 (E), Q35.3 (C), R66.1, R83.1, R85.1, R92.1, R94.1, R121.1, R123.1
/Rope Drivers/BPLIZ2: C10.1, D101.2 (A), D108.2 (A), D124.2 (A), L36.2, Q37.2 (E), Q38.3 (C), R71.1, R101.1, R103.1, R110.1, R112.1, R130.1, R132.1
/Rope Drivers/BPLMX1: C3.1, D66.2 (A), D68.2 (A), D70.2 (A), D73.2 (A), L29.2
/Rope Drivers/BPLMX2: C4.1, D67.2 (A), D69.2 (A), D71.2 (A), D74.2 (A), L30.2
/Rope Drivers/BPLMX3: C7.1, D65.2 (A), D72.2 (A), D75.2 (A), L33.2
/Rope Drivers/BPLMY1: C5.1, D77.2 (A), D79.2 (A), D81.2 (A), D84.2 (A), L31.2
/Rope Drivers/BPLMY2: C6.1, D78.2 (A), D80.2 (A), D82.2 (A), D85.2 (A), L32.2
/Rope Drivers/BPLMY3: C9.1, D76.2 (A), D83.2 (A), D86.2 (A), L35.2
/Sense Amplifiers/BPLSWX: C11.1, L37.2, R185.2, R186.1, R187.2, R188.1, R193.2, R194.1, R195.2, R196.1, R201.2, R202.1, R203.2, R204.1, R209.2, R210.1, R211.2, R212.1, R217.2, R218.1, R219.2, R220.1, R225.2, R226.1, R227.2, R228.1, R233.2, R234.1, R235.2, R236.1, R241.2, R242.1, R243.2, R244.1
/Sense Amplifiers/VREF: C13.2, C17.2, C21.2, C25.2, C29.2, C33.2, C37.2, C41.2, R266.2, R267.1, U1.5 (+), U2.5 (+), U3.5 (+), U4.5 (+), U5.5 (+), U6.5 (+), U7.5 (+), U8.5 (+)
/Strand Select/BPLSWZ: C12.1, D132.2 (A), D134.2 (A), D136.2 (A), D138.2 (A), D140.2 (A), D142.2 (A), D144.2 (A), D146.2 (A), D148.2 (A), D150.2 (A), D152.2 (A), D154.2 (A), D159.2 (A), L38.2, R138.1, R142.1, R146.1, R150.1, R154.1, R158.1, R162.1, R166.1, R170.1, R174.1, R178.1, R182.1, R269.1, R273.1
/Strand Select/RPR: Q88.3 (C), R270.2
GND: C1.2, C2.2, C3.2, C4.2, C5.2, C6.2, C7.2, C8.2, C9.2, C10.2, C11.2, C12.2, C13.1, C14.1, C15.2, C16.1, C17.1, C18.1, C19.2, C20.1, C21.1, C22.1, C23.2, C24.1, C25.1, C26.1, C27.2, C28.1, C29.1, C30.1, C31.2, C32.1, C33.1, C34.1, C35.2, C36.1, C37.1, C38.1, C39.2, C40.1, C41.1, C42.1, C43.2, C44.1, C45.1, C46.1, C47.1, C48.2, C49.1, C50.2, C51.2, C52.2, C53.1, C54.2, C55.2, C56.2, C57.2, C58.1, C59.2, D4.1 (K), D8.1 (K), D12.1 (K), D16.1 (K), D20.1 (K), D24.1 (K), D28.1 (K), D32.1 (K), D36.1 (K), D40.1 (K), D44.1 (K), D48.1 (K), D52.1 (K), D56.1 (K), D60.1 (K), D64.1 (K), D93.1 (K), D100.1 (K), D107.1 (K), D114.1 (K), D115.1 (K), D116.1 (K), D123.1 (K), D130.1 (K), D131.1 (K), D133.1 (K), D135.1 (K), D137.1 (K), D139.1 (K), D141.1 (K), D143.1 (K), D145.1 (K), D147.1 (K), D149.1 (K), D151.1 (K), D153.1 (K), D155.2 (A), D156.1 (K), D157.1 (K), D158.1 (K), D162.1 (K), H1.1, H2.1, H3.1, H4.1, H5.1, H6.1, H7.1, H8.1, J1.b20, J1.b21, J1.b22, J1.b23, J1.b24, J2.2, J2.3, J4.1, L17.2, L18.2, L19.2, L20.2, L21.2, L22.2, L23.2, L24.2, L25.2, L26.2, L27.2, L28.2, R68.2, R69.2, R73.2, R74.2, R84.2, R93.2, R102.2, R111.2, R122.2, R131.2, R140.2, R144.2, R148.2, R152.2, R156.2, R160.2, R164.2, R168.2, R172.2, R176.2, R180.2, R184.2, R189.2, R190.1, R191.2, R192.1, R197.2, R198.1, R199.2, R200.1, R205.2, R206.1, R207.2, R208.1, R213.2, R214.1, R215.2, R216.1, R221.2, R222.1, R223.2, R224.1, R229.2, R230.1, R231.2, R232.1, R237.2, R238.1, R239.2, R240.1, R245.2, R246.1, R247.2, R248.1, R262.2, R264.2, R267.2, R272.2, R275.2, U1.4 (-), U1.9 (GND), U1.13 (GND), U2.4 (-), U2.9 (GND), U2.13 (GND), U3.4 (-), U3.9 (GND), U3.13 (GND), U4.4 (-), U4.9 (GND), U4.13 (GND), U5.4 (-), U5.9 (GND), U5.13 (GND), U6.4 (-), U6.9 (GND), U6.13 (GND), U7.4 (-), U7.9 (GND), U7.13 (GND), U8.4 (-), U8.9 (GND), U8.13 (GND), U9.2 (VIN-), U9.3 (VIN-), U9.9 (COM), U9.16 (COM), U10.10 (GND), U10.19 (CE), U11.10 (GND), U11.19 (CE), U12.2 (GND), U13.8 (GND), U14.12 (GND), U14.23 (~E), U15.2 (GND), U16.2 (GND), U17.2 (GND), U18.2 (GND), U19.2 (GND)
unnamed: C14.2, U1.1 (CEXT)
unnamed: C18.2, U2.1 (CEXT)
unnamed: C22.2, U3.1 (CEXT)
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

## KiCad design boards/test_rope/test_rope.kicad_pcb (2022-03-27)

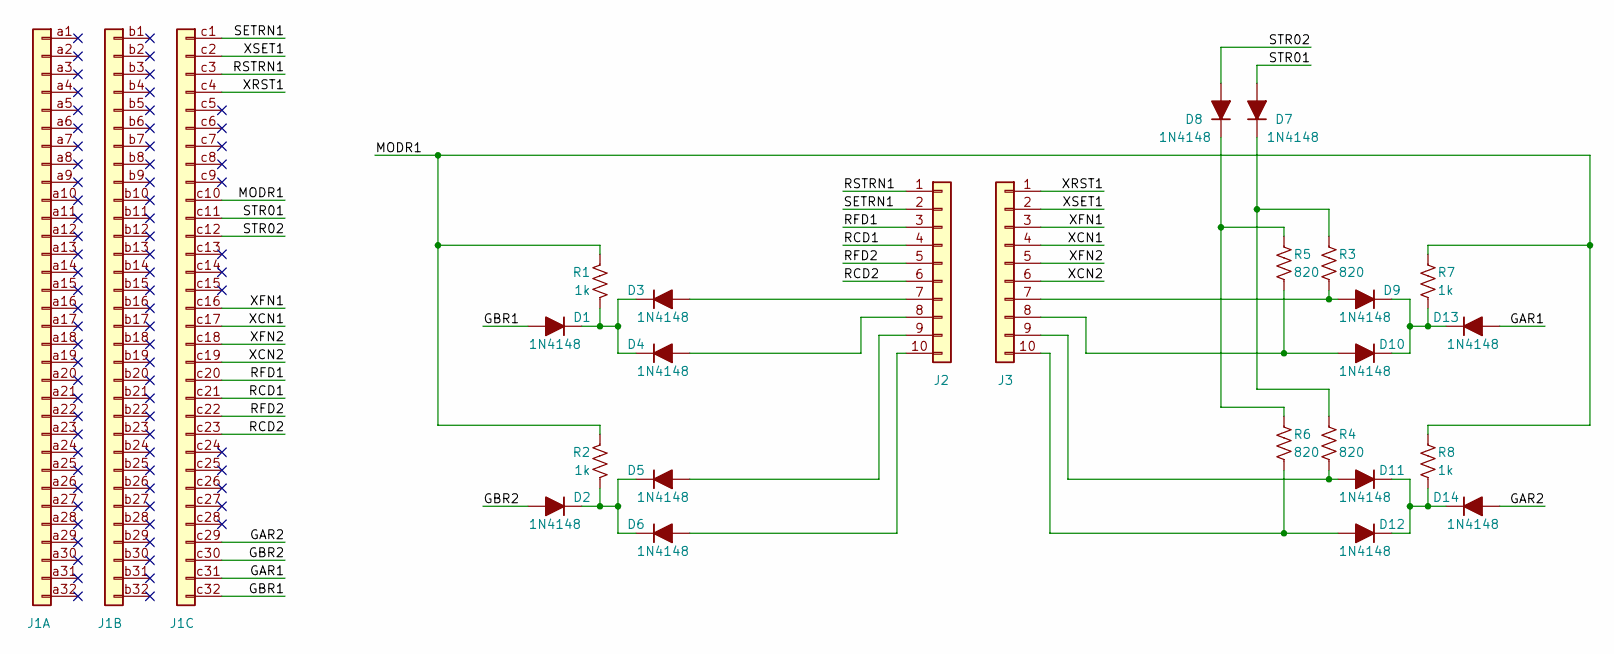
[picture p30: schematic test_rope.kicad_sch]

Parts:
D1, D2, D3, D4, D5, D6, D7, D8, D9, D10, D11, D12, D13, D14: 1N4148; D_SOD-323
J1: DIN41612_03x32_C; DIN41612_C_3x32_Female_Vertical_THT
J2, J3: Conn_01x10; PinHeader_1x10_P2.54mm_Vertical
R1, R2, R7, R8: 1k; R_0603_1608Metric
R3, R4, R5, R6: 820; R_0603_1608Metric

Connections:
/GAR1: D13.2 (A), J1.c31
/GAR2: D14.2 (A), J1.c29
/GBR1: D1.2 (A), J1.c32
/GBR2: D2.2 (A), J1.c30
/MODR1: J1.c10, R1.1, R2.1, R7.1, R8.1
/RCD1: J1.c21, J2.4
/RCD2: J1.c23, J2.6
/RFD1: J1.c20, J2.3
/RFD2: J1.c22, J2.5
/RSTRN1: J1.c3, J2.1
/SETRN1: J1.c1, J2.2
/STR01: D7.2 (A), J1.c11
/STR02: D8.2 (A), J1.c12
/XCN1: J1.c17, J3.4
/XCN2: J1.c19, J3.6
/XFN1: J1.c16, J3.3
/XFN2: J1.c18, J3.5
/XRST1: J1.c4, J3.1
/XSET1: J1.c2, J3.2
unnamed: D1.1 (K), D3.1 (K), D4.1 (K), R1.2
unnamed: D2.1 (K), D5.1 (K), D6.1 (K), R2.2
unnamed: D3.2 (A), J2.7
unnamed: D4.2 (A), J2.8
unnamed: D5.2 (A), J2.9
unnamed: D6.2 (A), J2.10
unnamed: D7.1 (K), R3.1, R4.1
unnamed: D8.1 (K), R5.1, R6.1
unnamed: D9.2 (A), J3.7, R3.2
unnamed: D9.1 (K), D10.1 (K), D13.1 (K), R7.2
unnamed: D11.1 (K), D12.1 (K), D14.1 (K), R8.2
unnamed: D11.2 (A), J3.9, R4.2
unnamed: D12.2 (A), J3.10, R6.2
unnamed: D10.2 (A), J3.8, R5.2

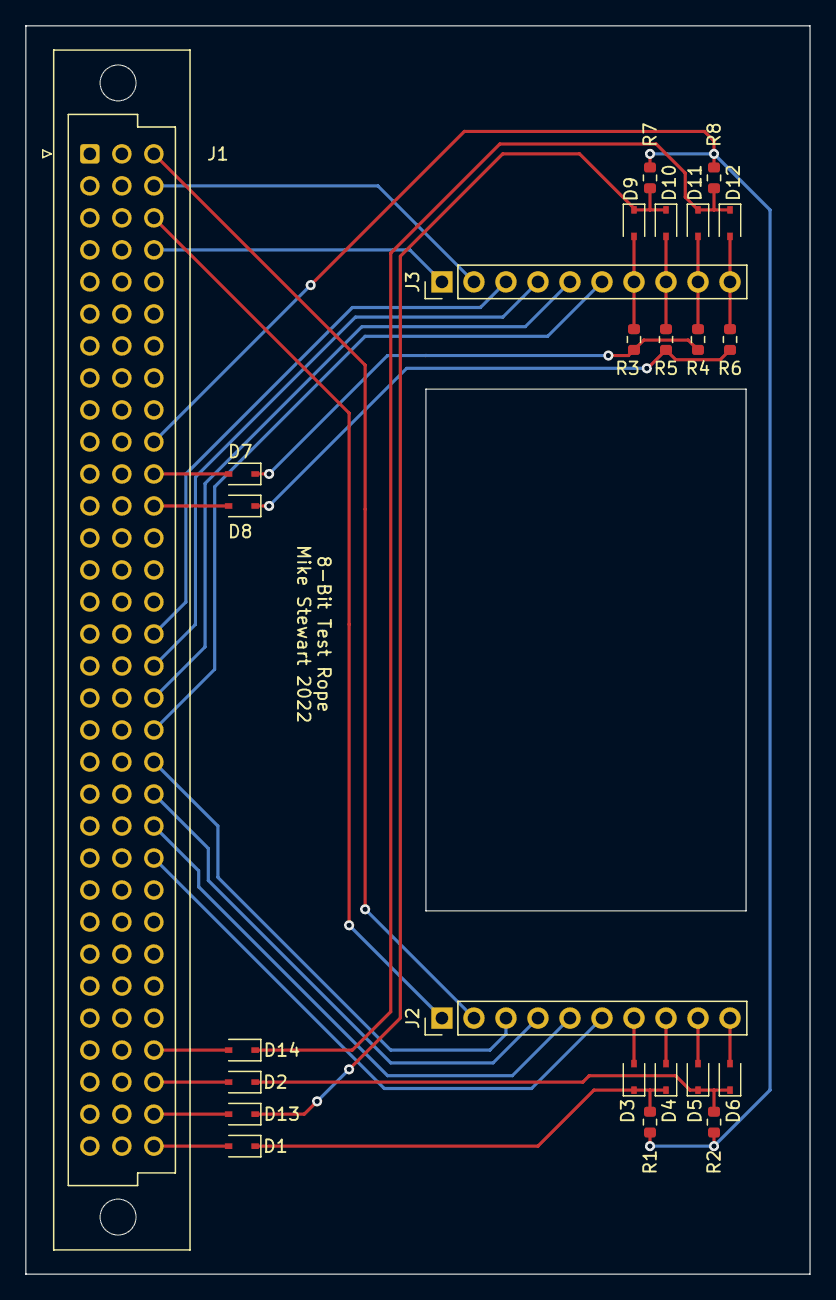
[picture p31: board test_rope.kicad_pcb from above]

Board: 2 copper layers, 62.2 x 99.1 mm, 25 parts (0 on the bottom side), 33 nets.

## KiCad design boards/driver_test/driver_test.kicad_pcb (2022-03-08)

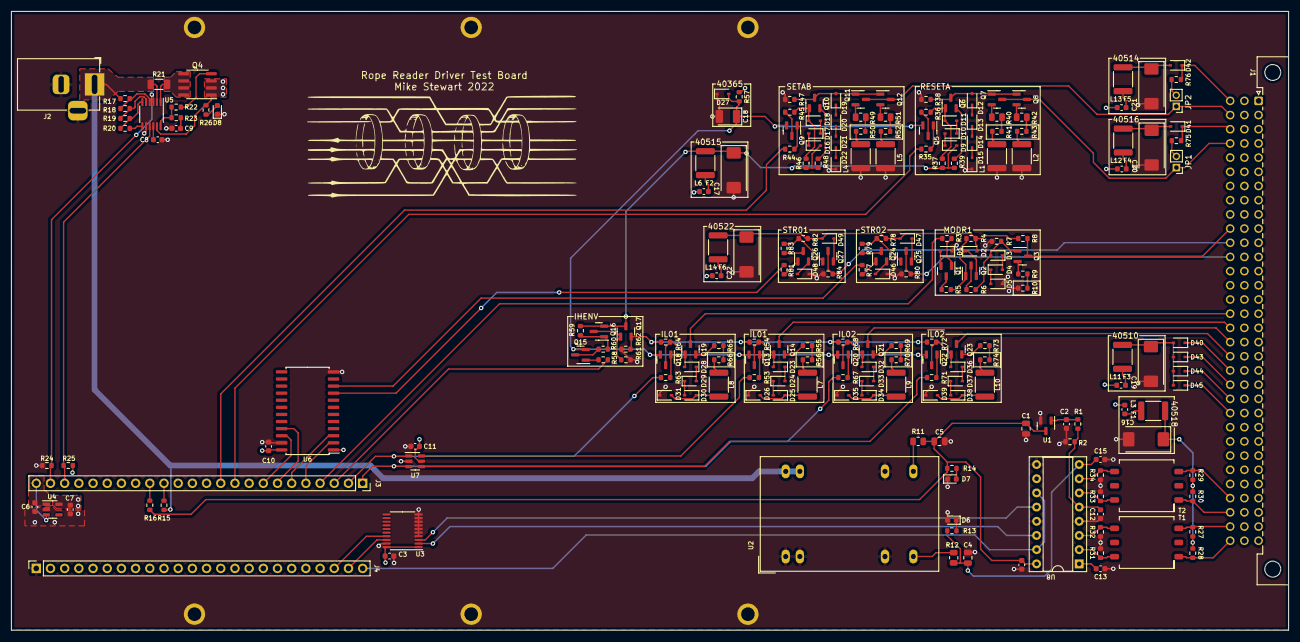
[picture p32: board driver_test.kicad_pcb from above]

Board: 4 copper layers, 228.6 x 110.7 mm, 224 parts (0 on the bottom side), 175 nets.

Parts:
C1: 4.7uF; C_0805_2012Metric
C2, C6, C7: 1.0uF; C_0603_1608Metric
C3, C10, C11, C14, C15: 0.1uF; C_0603_1608Metric
C4, C5: 1.0uF; C_0805_2012Metric
C8: 0.33uF; C_0603_1608Metric
C9, C12: 10nF; C_0603_1608Metric
C13: 100pF; C_0603_1608Metric
C16, C17, C19, C20, C21, C22: 6.8uF; CP_EIA-7343-31_Kemet-D
C18: 1.0uF; CP_EIA-3528-21_Kemet-B
D1, D2, D3, D4, D5, D9, D10, D11, D12, D13, D14, D15, D16, D17, D18, D19, D20, D21, D22, D23, D24, D25, D26, D27, D28, D29, D30, D31, D32, D33, D34, D35, D36, D37, D38, D39, D40, D41, D42, D43, D44, D45, D46, D47, D48, D49: 1N4148; D_SOD-323
D6: BLUE; LED_0603_1608Metric
D7: TEAL; LED_0603_1608Metric
D8: ORANGE; LED_0603_1608Metric
F1, F2, F3, F4, F5, F6: 250mA; Fuse_0603_1608Metric
H1, H2, H3, H4, H5, H6: MountingHole_Pad; MountingHole_No2_Pad
J1: DIN41612_03x32_C; DIN41612_C_3x32_Male_Horizontal_THT
J2: Barrel_Jack_Switch; BarrelJack_CUI_PJ-002A
J3, J4: Conn_01x24; PinSocket_1x24_P2.54mm_Vertical
JP1, JP2: Jumper_2_Open; PinHeader_1x02_P2.00mm_Vertical
L1, L2, L4, L5: 3.9uH; L_1812_4532Metric
L3, L6, L11, L12, L13, L14: 8.2uH; L_1812_4532Metric
L7, L8, L9, L10: 2.2uH; L_1812_4532Metric
Q1, Q3, Q5, Q7, Q8, Q9, Q11, Q12, Q13, Q14, Q15, Q17, Q18, Q19, Q20, Q21, Q22, Q23, Q24, Q26: MMBT2222; SOT-23
Q2, Q6, Q10, Q16, Q25, Q27: MMBT2907; SOT-23
Q4: IRF7413; SOIC-8_3.9x4.9mm_P1.27mm
R1: 1.27k; R_0603_1608Metric
R2: 249; R_0603_1608Metric
R3, R23, R35, R36, R44, R45, R53, R58, R63, R67, R71, R77, R81: 1k; R_0603_1608Metric
R4, R5, R7, R37, R38, R46, R47, R78, R82: 5.1k; R_0603_1608Metric
R6: 680; R_0603_1608Metric
R8, R57, R80, R84: 3k; R_0603_1608Metric
R9: 8.2; R_0603_1608Metric
R10, R41, R43, R50, R52, R56, R66, R70, R74: NOM; R_0603_1608Metric
R11, R12: 0; R_0805_2012Metric
R13, R14: 430; R_0603_1608Metric
R15: 12k; R_0603_1608Metric
R16: 2.4k; R_0603_1608Metric
R17: 1020k; R_0603_1608Metric
R18: 2.87k; R_0603_1608Metric
R19: 9.76k; R_0603_1608Metric
R20: 54.9k; R_0603_1608Metric
R21: 0.025; R_1206_3216Metric
R22: 10; R_0603_1608Metric
R24, R25: 10k; R_0603_1608Metric
R26: 620; R_0603_1608Metric
R27, R28, R29, R30: 2.7k; R_0603_1608Metric
R31, R32, R33, R34, R59: 470; R_0603_1608Metric
R39, R48: 27; R_0603_1608Metric
R40, R42, R49, R51: 7.5; R_0805_2012Metric
R54, R64, R68, R72: 390; R_0603_1608Metric
R55, R65, R69, R73: 3.9; R_0603_1608Metric
R60, R62, R79, R83: 2k; R_0603_1608Metric
R61: 750; R_0603_1608Metric
R75, R76: 200; R_0603_1608Metric
T1, T2: 1:1; Transformer_Murata_786J
U1: AD1582BRTZ; SOT-23
U2: JTE0624D05; Converter_DCDC_XP_POWER_JTExxxxDxx_THT
U3: 74LVC245; TSSOP-20_4.4x6.5mm_P0.65mm
U4: ADP151-3.3; TSOT-23-5
U5: LTC4231-1; MSOP-12_3x4mm_P0.65mm
U6: 74HC4514; SOIC-24W_7.5x15.4mm_P1.27mm
U7: 74LVC2G04; SOT-23-6
U8: SN7524; DIP-16_W7.62mm_Socket

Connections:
+3V3: C3.2, C7.1, C10.2, C11.1, R25.1, U3.1 (A->B), U3.20 (VCC), U4.5 (VOUT), U6.1 (~LE), U6.24 (VCC), U7.5 (VCC)
+5V: C1.2, C5.1, C14.1, R11.1, R14.1, R16.2, U1.3 (VIN), U8.16 (VCC+)
+14V: F1.2, F2.2, F3.2, F4.2, F5.2, F6.2, Q4.1 (S), Q4.2 (S), Q4.3 (S), R26.1, R57.2, U5.11 (SOURCE)
-5V: C4.2, C15.2, R12.1, R13.1, U8.8 (VCC-)
/40311/4036nA: C18.1, D27.2 (A), Q5.2 (E), Q9.2 (E), Q13.2 (E), Q15.2 (E), Q18.2 (E), Q20.2 (E), Q22.2 (E), R57.1
/40312/IN: R53.2, U7.6
/40314/IN: R71.2, U7.4
/40331/IN: J3.3, R58.2
/40331A: Q17.2 (E), R54.1, R62.1, R64.1, R68.1, R72.1
/40601a/SEn: R81.2, U6.9 (Y1)
/40601b/SEn: R77.2, U6.10 (Y2)
/BPLIZ1: C17.1, D9.2 (A), D16.2 (A), L6.2, Q16.2 (E), Q17.3 (C), R37.1, R39.1, R46.1, R48.1, R59.1
/BPLMX1: C19.1, D40.2 (A), D43.2 (A), D44.2 (A), D45.2 (A), L11.2
/BPLMX3: C21.1, D42.2 (A), L13.2
/BPLMY3: C20.1, D41.2 (A), L12.2
/BPLSWX: C16.1, L3.2, R27.2, R28.1, R29.2, R30.1
/BPLSWZ: C22.1, D2.2 (A), D47.2 (A), D49.2 (A), L14.2, R4.1, R8.1, R78.1, R82.1
/FPGA and Power/5V_FPGA: C6.2, J3.24, U4.1 (VIN), U4.3 (EN)
/FPGA and Power/14V_IN: J2.1, R15.2, R17.2, R21.1, U2.22 (VIN+), U2.23 (VIN+), U5.2 (IN)
/FPGA and Power/14V_SENSE: Q4.5 (D), Q4.6 (D), Q4.7 (D), Q4.8 (D), R21.2, U5.1 (SENSE)
/FPGA and Power/ADC_5V: J3.16, R16.1
/FPGA and Power/ADC_14V: J3.15, R15.1
/FPGA and Power/EN_14V: J3.23, R24.1, U5.3 (~SHDN)
/FPGA and Power/IL1: J3.2, R63.2, U7.1
/FPGA and Power/IL2: J3.1, R67.2, U7.3
/FPGA and Power/PG_14V: J3.22, R25.2, U5.9 (STATUS)
/FPGA and Power/RESET1: J3.10, R35.2
/FPGA and Power/ROPER: J3.4, R3.2
/FPGA and Power/SA1: U3.2 (A0), U8.14
/FPGA and Power/SA2: U3.3 (A1), U8.12
/FPGA and Power/SAF1: J4.23, U3.18 (B0)
/FPGA and Power/SAF2: J4.22, U3.17 (B1)
/FPGA and Power/SBF: J4.24, U8.11, U8.15
/FPGA and Power/SET1: J3.11, R44.2
/FPGA and Power/STRA0: J3.5, U6.2 (A0)
/FPGA and Power/STRA1: J3.6, U6.3 (A1)
/FPGA and Power/STRA2: J3.7, U6.21 (A2)
/FPGA and Power/STRA3: J3.8, U6.22 (A3)
/GAR1: J1.c31, R27.1, T1.3 (P2)
/GAR2: J1.c29, R29.1, T2.3 (P2)
/GBR1: J1.c32, R28.2, T1.1
/GBR2: J1.c30, R30.2, T2.1
/MODR1: J1.c10, Q3.3 (C), R8.2
/RCD1: D43.1 (K), J1.c21
/RCD2: D45.1 (K), J1.c23
/RFD1: D40.1 (K), J1.c20
/RFD2: D44.1 (K), J1.c22
/RPR: Q1.3 (C), R5.2
/RSTRN1: D41.1 (K), J1.c3, R75.2
/SETRN1: D42.1 (K), J1.c1, R76.2
/STR1: J1.c11, Q27.3 (C), R84.1
/STR2: J1.c12, Q25.3 (C), R80.1
/VREF: C12.2, R1.2, R2.1, U8.5 (+)
/XCN1: J1.c17, Q14.3 (C)
/XCN2: J1.c19, Q23.3 (C)
/XFN1: J1.c16, Q19.3 (C)
/XFN2: J1.c18, Q21.3 (C)
/XRST1: J1.c4, JP1.1 (A), Q7.3 (C), Q8.3 (C)
/XSET1: J1.c2, JP2.1 (A), Q11.3 (C), Q12.3 (C)
GND: C1.1, C2.2, C3.1, C4.1, C5.2, C6.1, C7.2, C8.2, C9.2, C10.1, C11.2, C12.1, C13.1, C14.2, C15.1, C16.2, C17.2, C18.2, C19.2, C20.2, C21.2, C22.2, D1.1 (K), D5.1 (K), D6.2 (A), D7.1 (K), D8.1 (K), D15.1 (K), D22.1 (K), D26.1 (K), D27.1 (K), D31.1 (K), D35.1 (K), D39.1 (K), D46.1 (K), D48.1 (K), H1.1, H2.1, H3.1, H4.1, H5.1, H6.1, J2.2, J2.3, J4.1, L1.2, L2.2, L4.2, L5.2, R2.2, R7.2, R10.2, R24.2, R31.2, R32.1, R33.2, R34.1, R38.2, R47.2, R61.2, R62.2, R80.2, R84.2, U1.2 (GND), U2.2 (VIN-), U2.3 (VIN-), U2.9 (COM), U2.16 (COM), U3.4 (A2), U3.5 (A3), U3.6 (A4), U3.7 (A5), U3.8 (A6), U3.9 (A7), U3.10 (GND), U3.19 (CE), U4.2 (GND), U5.8 (GND), U6.12 (GND), U6.23 (~E), U7.2 (GND), U8.4 (-), U8.9 (GND), U8.13 (GND)
unnamed: C2.1, R1.1, U1.1 (VOUT)
unnamed: C8.1, U5.10 (TIMER)
unnamed: C9.1, R23.1
unnamed: C13.2, U8.1 (CEXT)
unnamed: D1.2 (A), Q1.2 (E)
unnamed: D2.1 (K), Q2.2 (E)
unnamed: D3.1 (K), D4.2 (A)
unnamed: D3.2 (A), Q3.1 (B), R6.2, R7.1
unnamed: D4.1 (K), D5.2 (A)
unnamed: D6.1 (K), R13.2
unnamed: D7.2 (A), R14.2
unnamed: D8.2 (A), R26.2
unnamed: D10.1 (K), D11.2 (A)
unnamed: D9.1 (K), D10.2 (A)
unnamed: D11.1 (K), Q6.1 (B), R36.1, R37.2
unnamed: D12.1 (K), D13.2 (A)
unnamed: D12.2 (A), Q6.3 (C), Q7.1 (B), Q8.1 (B), R38.1
unnamed: D13.1 (K), D14.2 (A)
unnamed: D14.1 (K), D15.2 (A)
unnamed: D16.1 (K), D17.2 (A)
unnamed: D17.1 (K), D18.2 (A)
unnamed: D18.1 (K), Q10.1 (B), R45.1, R46.2
unnamed: D19.1 (K), D20.2 (A)
unnamed: D19.2 (A), Q10.3 (C), Q11.1 (B), Q12.1 (B), R47.1
unnamed: D20.1 (K), D21.2 (A)
unnamed: D21.1 (K), D22.2 (A)
unnamed: D23.1 (K), D24.2 (A)
unnamed: D23.2 (A), Q13.3 (C), Q14.1 (B), R54.2
unnamed: D24.1 (K), D25.2 (A)
unnamed: D25.1 (K), D26.2 (A), L7.2
unnamed: D28.1 (K), D29.2 (A)
unnamed: D28.2 (A), Q18.3 (C), Q19.1 (B), R64.2
unnamed: D29.1 (K), D30.2 (A)
unnamed: D30.1 (K), D31.2 (A), L8.2
unnamed: D32.1 (K), D33.2 (A)
unnamed: D32.2 (A), Q20.3 (C), Q21.1 (B), R68.2
unnamed: D33.1 (K), D34.2 (A)
unnamed: D34.1 (K), D35.2 (A), L9.2
unnamed: D36.1 (K), D37.2 (A)
unnamed: D36.2 (A), Q22.3 (C), Q23.1 (B), R72.2
unnamed: D37.1 (K), D38.2 (A)
unnamed: D38.1 (K), D39.2 (A), L10.2
unnamed: D46.2 (A), Q24.2 (E)
unnamed: D47.1 (K), Q25.2 (E)
unnamed: D48.2 (A), Q26.2 (E)
unnamed: D49.1 (K), Q27.2 (E)
unnamed: F1.1, L3.1
unnamed: F2.1, L6.1
unnamed: F3.1, L11.1
unnamed: F4.1, L12.1
unnamed: F5.1, L13.1
unnamed: F6.1, L14.1
unnamed: JP1.2 (B), R75.1
unnamed: JP2.2 (B), R76.1
unnamed: L1.1, R41.2
unnamed: L2.1, R43.2
unnamed: L4.1, R50.2
unnamed: L5.1, R52.2
unnamed: L7.1, R56.2
unnamed: L8.1, R66.2
unnamed: L9.1, R70.2
unnamed: L10.1, R74.2
unnamed: Q1.1 (B), R3.1
unnamed: Q2.1 (B), R4.2, R5.1
unnamed: Q2.3 (C), R6.1
unnamed: Q3.2 (E), R9.1
unnamed: Q4.4 (G), R22.1
unnamed: Q5.1 (B), R35.1
unnamed: Q5.3 (C), R36.2
unnamed: Q6.2 (E), R39.2
unnamed: Q7.2 (E), R40.1
unnamed: Q8.2 (E), R42.1
unnamed: Q9.1 (B), R44.1
unnamed: Q9.3 (C), R45.2
unnamed: Q10.2 (E), R48.2
unnamed: Q11.2 (E), R49.1
unnamed: Q12.2 (E), R51.1
unnamed: Q13.1 (B), R53.1
unnamed: Q14.2 (E), R55.1
unnamed: Q15.1 (B), R58.1
unnamed: Q15.3 (C), R60.2
unnamed: Q16.1 (B), R59.2, R60.1
unnamed: Q16.3 (C), Q17.1 (B), R61.1
unnamed: Q18.1 (B), R63.1
unnamed: Q19.2 (E), R65.1
unnamed: Q20.1 (B), R67.1
unnamed: Q21.2 (E), R69.1
unnamed: Q22.1 (B), R71.1
unnamed: Q23.2 (E), R73.1
unnamed: Q24.1 (B), R77.1
unnamed: Q24.3 (C), R79.2
unnamed: Q25.1 (B), R78.2, R79.1
unnamed: Q26.1 (B), R81.1
unnamed: Q26.3 (C), R83.2
unnamed: Q27.1 (B), R82.2, R83.1
unnamed: R9.2, R10.1
unnamed: R11.2, U2.14 (VOUT+)
unnamed: R12.2, U2.11 (VOUT-)
unnamed: R17.1, R18.2, U5.4 (UVL)
unnamed: R18.1, R19.2, U5.5 (UVH)
unnamed: R19.1, R20.2, U5.6 (OV)
unnamed: R20.1, U5.7 (GNDSW)
unnamed: R22.2, R23.2, U5.12 (GATE)
unnamed: R31.1, T1.4 (S2), U8.2
unnamed: R32.2, T1.6 (S1), U8.3
unnamed: R33.1, T2.4 (S2), U8.6
unnamed: R34.2, T2.6 (S1), U8.7
unnamed: R40.2, R41.1
unnamed: R42.2, R43.1
unnamed: R49.2, R50.1
unnamed: R51.2, R52.1
unnamed: R55.2, R56.1
unnamed: R65.2, R66.1
unnamed: R69.2, R70.1
unnamed: R73.2, R74.1

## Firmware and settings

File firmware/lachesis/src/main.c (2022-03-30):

#include "intr.h"
#include "uart.h"
#include "wdt.h"
#include "cmd.h"
#include "sys.h"
#include "rope.h"

static int32_t system_init(void);

int main(void)
{
    int32_t status;

    status = system_init();
    if (status != XST_SUCCESS)
    {
        return status;
    }

    while (1)
    {
        sys_service();
        wdt_service();
        rope_service();
        cmd_service();
    }
}

static int32_t system_init(void)
{
    int32_t status;

    status = wdt_init();
    if (status != XST_SUCCESS)
    {
        return status;
    }

    status = intr_init();
    if (status != XST_SUCCESS)
    {
        return status;
    }

    status = sys_init();
    if (status != XST_SUCCESS)
    {
        return status;
    }

    status = uart_init();
    if (status != XST_SUCCESS)
    {
        return status;
    }

    cmd_init();
    if (status != XST_SUCCESS)
    {
        return status;
    }

    rope_init();
    if (status != XST_SUCCESS)
    {
        return status;
    }

    Xil_ExceptionEnable();

    return XST_SUCCESS;
}

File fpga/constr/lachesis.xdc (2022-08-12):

set_property IOSTANDARD LVCMOS33 [get_ports Vaux4_0_v_n]
set_property IOSTANDARD LVCMOS33 [get_ports Vaux4_0_v_p]
set_property IOSTANDARD LVCMOS33 [get_ports Vaux12_0_v_n]
set_property IOSTANDARD LVCMOS33 [get_ports Vaux12_0_v_p]
set_property PACKAGE_PIN G2 [get_ports Vaux4_0_v_n]

set_property BITSTREAM.GENERAL.COMPRESS TRUE [current_design]
set_property BITSTREAM.CONFIG.CONFIGRATE 33 [current_design]
set_property CONFIG_MODE SPIx4 [current_design]

set_property IOSTANDARD LVCMOS33 [get_ports {il_0[2]}]
set_property IOSTANDARD LVCMOS33 [get_ports {il_0[1]}]
set_property IOSTANDARD LVCMOS33 [get_ports {saf_0[2]}]
set_property IOSTANDARD LVCMOS33 [get_ports {saf_0[1]}]
set_property IOSTANDARD LVCMOS33 [get_ports {str_0[3]}]
set_property IOSTANDARD LVCMOS33 [get_ports {str_0[2]}]
set_property IOSTANDARD LVCMOS33 [get_ports {str_0[1]}]
set_property IOSTANDARD LVCMOS33 [get_ports {str_0[0]}]
set_property IOSTANDARD LVCMOS33 [get_ports bplssw_0]
set_property IOSTANDARD LVCMOS33 [get_ports bplssw_pg_0]
set_property IOSTANDARD LVCMOS33 [get_ports ihenv_0]
set_property IOSTANDARD LVCMOS33 [get_ports {reset_0[4]}]
set_property IOSTANDARD LVCMOS33 [get_ports {reset_0[3]}]
set_property IOSTANDARD LVCMOS33 [get_ports {reset_0[2]}]
set_property IOSTANDARD LVCMOS33 [get_ports {reset_0[1]}]
set_property IOSTANDARD LVCMOS33 [get_ports roper_0]
set_property IOSTANDARD LVCMOS33 [get_ports sbf_0]
set_property IOSTANDARD LVCMOS33 [get_ports {set_0[2]}]
set_property IOSTANDARD LVCMOS33 [get_ports {set_0[1]}]
set_property PACKAGE_PIN N2 [get_ports bplssw_pg_0]
set_property PACKAGE_PIN P1 [get_ports bplssw_0]

set_property IOSTANDARD LVCMOS33 [get_ports {il_0[8]}]
set_property IOSTANDARD LVCMOS33 [get_ports {il_0[7]}]
set_property IOSTANDARD LVCMOS33 [get_ports {il_0[6]}]
set_property IOSTANDARD LVCMOS33 [get_ports {il_0[5]}]
set_property IOSTANDARD LVCMOS33 [get_ports {il_0[4]}]
set_property IOSTANDARD LVCMOS33 [get_ports {il_0[3]}]
set_property IOSTANDARD LVCMOS33 [get_ports {saf_0[16]}]
set_property IOSTANDARD LVCMOS33 [get_ports {saf_0[15]}]
set_property IOSTANDARD LVCMOS33 [get_ports {saf_0[14]}]
set_property IOSTANDARD LVCMOS33 [get_ports {saf_0[13]}]
set_property IOSTANDARD LVCMOS33 [get_ports {saf_0[12]}]
set_property IOSTANDARD LVCMOS33 [get_ports {saf_0[11]}]
set_property IOSTANDARD LVCMOS33 [get_ports {saf_0[10]}]
set_property IOSTANDARD LVCMOS33 [get_ports {saf_0[9]}]
set_property IOSTANDARD LVCMOS33 [get_ports {saf_0[8]}]
set_property IOSTANDARD LVCMOS33 [get_ports {saf_0[7]}]
set_property IOSTANDARD LVCMOS33 [get_ports {saf_0[6]}]
set_property IOSTANDARD LVCMOS33 [get_ports {saf_0[5]}]
set_property IOSTANDARD LVCMOS33 [get_ports {saf_0[4]}]
set_property IOSTANDARD LVCMOS33 [get_ports {saf_0[3]}]
set_property PACKAGE_PIN M3 [get_ports {il_0[8]}]
set_property PACKAGE_PIN K3 [get_ports {il_0[7]}]
set_property PACKAGE_PIN B15 [get_ports {il_0[6]}]
set_property PACKAGE_PIN L1 [get_ports {il_0[5]}]
set_property PACKAGE_PIN L3 [get_ports {il_0[4]}]
set_property PACKAGE_PIN A16 [get_ports {il_0[3]}]
set_property PACKAGE_PIN A14 [get_ports {il_0[2]}]
set_property PACKAGE_PIN L2 [get_ports {il_0[1]}]
set_property PACKAGE_PIN H1 [get_ports {reset_0[4]}]
set_property PACKAGE_PIN U1 [get_ports {reset_0[3]}]
set_property PACKAGE_PIN A15 [get_ports {reset_0[2]}]
set_property PACKAGE_PIN W2 [get_ports {reset_0[1]}]
set_property PACKAGE_PIN V8 [get_ports {saf_0[16]}]
set_property PACKAGE_PIN W3 [get_ports {saf_0[15]}]
set_property PACKAGE_PIN W7 [get_ports {saf_0[14]}]
set_property PACKAGE_PIN U8 [get_ports {saf_0[13]}]
set_property PACKAGE_PIN U7 [get_ports {saf_0[12]}]
set_property PACKAGE_PIN U3 [get_ports {saf_0[11]}]
set_property PACKAGE_PIN U2 [get_ports {saf_0[10]}]
set_property PACKAGE_PIN W6 [get_ports {saf_0[9]}]
set_property PACKAGE_PIN U5 [get_ports {saf_0[8]}]
set_property PACKAGE_PIN V5 [get_ports {saf_0[7]}]
set_property PACKAGE_PIN V4 [get_ports {saf_0[6]}]
set_property PACKAGE_PIN W4 [get_ports {saf_0[5]}]
set_property PACKAGE_PIN U4 [get_ports {saf_0[4]}]
set_property PACKAGE_PIN V3 [get_ports {saf_0[3]}]
set_property PACKAGE_PIN V2 [get_ports {saf_0[2]}]
set_property PACKAGE_PIN W5 [get_ports {saf_0[1]}]
set_property PACKAGE_PIN C15 [get_ports {set_0[2]}]
set_property PACKAGE_PIN J1 [get_ports {set_0[1]}]
set_property PACKAGE_PIN N3 [get_ports {str_0[3]}]
set_property PACKAGE_PIN P3 [get_ports {str_0[2]}]
set_property PACKAGE_PIN M2 [get_ports {str_0[1]}]
set_property PACKAGE_PIN N1 [get_ports {str_0[0]}]
set_property PACKAGE_PIN T1 [get_ports ihenv_0]
set_property PACKAGE_PIN J3 [get_ports roper_0]
set_property PACKAGE_PIN T2 [get_ports sbf_0]

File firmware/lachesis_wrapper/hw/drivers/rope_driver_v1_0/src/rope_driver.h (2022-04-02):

#ifndef ROPE_DRIVER_H
#define ROPE_DRIVER_H


/****************** Include Files ********************/
#include "xil_types.h"
#include "xstatus.h"
#include "xil_io.h"

#define ROPE_DRIVER_ENABLE_OFFSET          0
#define ROPE_DRIVER_STATUS_OFFSET          0
#define ROPE_DRIVER_ADDRESS_OFFSET         4
#define ROPE_DRIVER_DATA_OFFSET            8
#define ROPE_DRIVER_BPLSSW_EN_OFFSET      12
#define ROPE_DRIVER_SBF_EN_OFFSET         16
#define ROPE_DRIVER_IHENV_OFFSET_OFFSET   20
#define ROPE_DRIVER_IHENV_WIDTH_OFFSET    24
#define ROPE_DRIVER_RESET1_OFFSET_OFFSET  28
#define ROPE_DRIVER_RESET1_WIDTH_OFFSET   32
#define ROPE_DRIVER_SET_OFFSET_OFFSET     36
#define ROPE_DRIVER_SET_WIDTH_OFFSET      40
#define ROPE_DRIVER_STRGAT_OFFSET_OFFSET  44
#define ROPE_DRIVER_STRGAT_WIDTH_OFFSET   48
#define ROPE_DRIVER_RESET2_OFFSET_OFFSET  52
#define ROPE_DRIVER_RESET2_WIDTH_OFFSET   56
#define ROPE_DRIVER_SBF_OFFSET_OFFSET     60
#define ROPE_DRIVER_SBF_WIDTH_OFFSET      64
#define ROPE_DRIVER_BPLSSW_POWERON_OFFSET 68
#define ROPE_DRIVER_BPLSSW_PG_LOSS_OFFSET 72


/**************************** Type Definitions *****************************/

typedef struct
{
    uint32_t base_address;
} rope_driver_t;

typedef struct
{
    uint16_t ihenv_offset;
    uint16_t ihenv_width;
    uint16_t reset1_offset;
    uint16_t reset1_width;
    uint16_t set_offset;
    uint16_t set_width;
    uint16_t strgat_offset;
    uint16_t strgat_width;
    uint16_t reset2_offset;
    uint16_t reset2_width;
    uint16_t sbf_offset;
    uint16_t sbf_width;
    uint32_t bplssw_poweron_timeout;
    uint16_t bplssw_pg_loss_timeout;
} rope_driver_timings_t;

typedef enum
{
    ROPE_DRIVER_ENABLE_IHENV  = 0x01,
    ROPE_DRIVER_ENABLE_RESET1 = 0x02,
    ROPE_DRIVER_ENABLE_SET    = 0x04,
    ROPE_DRIVER_ENABLE_STRGAT = 0x08,
    ROPE_DRIVER_ENABLE_RESET2 = 0x10,
    ROPE_DRIVER_ENABLE_SBF    = 0x20,
    ROPE_DRIVER_ENABLE_ALL    = 0x3F,
} rope_driver_enable_mask_t;

/**
 *
 * Write a value to a ROPE_DRIVER register. A 32 bit write is performed.
 * If the component is implemented in a smaller width, only the least
 * significant data is written.
 *
 * @param   BaseAddress is the base address of the ROPE_DRIVERdevice.
 * @param   RegOffset is the register offset from the base to write to.
 * @param   Data is the data written to the register.
 *
 * @return  None.
 *
 * @note
 * C-style signature:
 * 	void ROPE_DRIVER_mWriteReg(u32 BaseAddress, unsigned RegOffset, u32 Data)
 *
 */
#define ROPE_DRIVER_mWriteReg(BaseAddress, RegOffset, Data) \
  	Xil_Out32((BaseAddress) + (RegOffset), (u32)(Data))

/**
 *
 * Read a value from a ROPE_DRIVER register. A 32 bit read is performed.
 * If the component is implemented in a smaller width, only the least
 * significant data is read from the register. The most significant data
 * will be read as 0.
 *
 * @param   BaseAddress is the base address of the ROPE_DRIVER device.
 * @param   RegOffset is the register offset from the base to write to.
 *
 * @return  Data is the data from the register.
 *
 * @note
 * C-style signature:
 * 	u32 ROPE_DRIVER_mReadReg(u32 BaseAddress, unsigned RegOffset)
 *
 */
#define ROPE_DRIVER_mReadReg(BaseAddress, RegOffset) \
    Xil_In32((BaseAddress) + (RegOffset))

/************************** Function Prototypes ****************************/
/**
 *
 * Run a self-test on the driver/device. Note this may be a destructive test if
 * resets of the device are performed.
 *
 * If the hardware system is not built correctly, this function may never
 * return to the caller.
 *
 * @param   baseaddr_p is the base address of the ROPE_DRIVER instance to be worked on.
 *
 * @return
 *
 *    - XST_SUCCESS   if all self-test code passed
 *    - XST_FAILURE   if any self-test code failed
 *
 * @note    Caching must be turned off for this function to work.
 * @note    Self test may fail if data memory and device are not on the same bus.
 *
 */
XStatus ROPE_DRIVER_Reg_SelfTest(void * baseaddr_p);

XStatus rope_driver_initialize(rope_driver_t *rope, uint32_t base_address);
void rope_driver_start_cycle(rope_driver_t *rope, uint8_t enable_mask);
uint8_t rope_driver_busy(rope_driver_t *rope);
void rope_driver_set_address(rope_driver_t *rope, uint16_t address);
uint16_t rope_driver_get_last_address(rope_driver_t *rope);
uint16_t rope_driver_get_sensed_word(rope_driver_t *rope);
void rope_driver_set_bplssw_state(rope_driver_t *rope, uint8_t state);
uint8_t rope_driver_get_bplssw_state(rope_driver_t *rope);
void rope_driver_set_sbf_state(rope_driver_t *rope, uint8_t state);
uint8_t rope_driver_get_sbf_state(rope_driver_t *rope);
void rope_driver_set_timings(rope_driver_t *rope, rope_driver_timings_t *timings);
void rope_driver_get_timings(rope_driver_t *rope, rope_driver_timings_t *timings);

#endif // ROPE_DRIVER_H

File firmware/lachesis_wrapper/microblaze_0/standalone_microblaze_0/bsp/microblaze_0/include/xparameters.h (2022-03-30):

#ifndef XPARAMETERS_H   /* prevent circular inclusions */
#define XPARAMETERS_H   /* by using protection macros */

/* Definitions for bus frequencies */
#define XPAR_CPU_M_AXI_DP_FREQ_HZ 100000000
/******************************************************************/

/* Canonical definitions for bus frequencies */
/******************************************************************/

#define XPAR_CPU_CORE_CLOCK_FREQ_HZ 100000000
#define XPAR_MICROBLAZE_CORE_CLOCK_FREQ_HZ 100000000

/******************************************************************/


/* Definitions for peripheral MICROBLAZE_0 */
#define XPAR_MICROBLAZE_0_ADDR_SIZE 32
#define XPAR_MICROBLAZE_0_ADDR_TAG_BITS 17
#define XPAR_MICROBLAZE_0_ALLOW_DCACHE_WR 1
#define XPAR_MICROBLAZE_0_ALLOW_ICACHE_WR 1
#define XPAR_MICROBLAZE_0_AREA_OPTIMIZED 0
#define XPAR_MICROBLAZE_0_ASYNC_INTERRUPT 1
#define XPAR_MICROBLAZE_0_ASYNC_WAKEUP 3
#define XPAR_MICROBLAZE_0_AVOID_PRIMITIVES 0
#define XPAR_MICROBLAZE_0_BASE_VECTORS 0x0000000000000000
#define XPAR_MICROBLAZE_0_BRANCH_TARGET_CACHE_SIZE 0
#define XPAR_MICROBLAZE_0_CACHE_BYTE_SIZE 8192
#define XPAR_MICROBLAZE_0_DADDR_SIZE 32
#define XPAR_MICROBLAZE_0_DATA_SIZE 32
#define XPAR_MICROBLAZE_0_DCACHE_ADDR_TAG 17
#define XPAR_MICROBLAZE_0_DCACHE_ALWAYS_USED 1
#define XPAR_MICROBLAZE_0_DCACHE_BASEADDR 0x00000000
#define XPAR_MICROBLAZE_0_DCACHE_BYTE_SIZE 8192
#define XPAR_MICROBLAZE_0_DCACHE_DATA_WIDTH 0
#define XPAR_MICROBLAZE_0_DCACHE_FORCE_TAG_LUTRAM 0
#define XPAR_MICROBLAZE_0_DCACHE_HIGHADDR 0x3FFFFFFF
#define XPAR_MICROBLAZE_0_DCACHE_LINE_LEN 4
#define XPAR_MICROBLAZE_0_DCACHE_USE_WRITEBACK 0
#define XPAR_MICROBLAZE_0_DCACHE_VICTIMS 0
#define XPAR_MICROBLAZE_0_DC_AXI_MON 0
#define XPAR_MICROBLAZE_0_DEBUG_COUNTER_WIDTH 32
#define XPAR_MICROBLAZE_0_DEBUG_ENABLED 1
#define XPAR_MICROBLAZE_0_DEBUG_EVENT_COUNTERS 5
#define XPAR_MICROBLAZE_0_DEBUG_EXTERNAL_TRACE 0
#define XPAR_MICROBLAZE_0_DEBUG_INTERFACE 0
#define XPAR_MICROBLAZE_0_DEBUG_LATENCY_COUNTERS 1
#define XPAR_MICROBLAZE_0_DEBUG_PROFILE_SIZE 0
#define XPAR_MICROBLAZE_0_DEBUG_TRACE_ASYNC_RESET 0
#define XPAR_MICROBLAZE_0_DEBUG_TRACE_SIZE 8192
#define XPAR_MICROBLAZE_0_DIV_ZERO_EXCEPTION 0
#define XPAR_MICROBLAZE_0_DP_AXI_MON 0
#define XPAR_MICROBLAZE_0_DYNAMIC_BUS_SIZING 0
#define XPAR_MICROBLAZE_0_D_AXI 1
#define XPAR_MICROBLAZE_0_D_LMB 1
#define XPAR_MICROBLAZE_0_D_LMB_MON 0
#define XPAR_MICROBLAZE_0_D_LMB_PROTOCOL 0
#define XPAR_MICROBLAZE_0_ECC_USE_CE_EXCEPTION 0
#define XPAR_MICROBLAZE_0_EDGE_IS_POSITIVE 1
#define XPAR_MICROBLAZE_0_ENABLE_DISCRETE_PORTS 0
#define XPAR_MICROBLAZE_0_ENDIANNESS 1
#define XPAR_MICROBLAZE_0_FAULT_TOLERANT 0
#define XPAR_MICROBLAZE_0_FPU_EXCEPTION 0
#define XPAR_MICROBLAZE_0_FREQ 100000000
#define XPAR_MICROBLAZE_0_FSL_EXCEPTION 0
#define XPAR_MICROBLAZE_0_FSL_LINKS 0
#define XPAR_MICROBLAZE_0_IADDR_SIZE 32
#define XPAR_MICROBLAZE_0_ICACHE_ALWAYS_USED 1
#define XPAR_MICROBLAZE_0_ICACHE_BASEADDR 0x00000000
#define XPAR_MICROBLAZE_0_ICACHE_DATA_WIDTH 0
#define XPAR_MICROBLAZE_0_ICACHE_FORCE_TAG_LUTRAM 0
#define XPAR_MICROBLAZE_0_ICACHE_HIGHADDR 0x3FFFFFFF
#define XPAR_MICROBLAZE_0_ICACHE_LINE_LEN 4
#define XPAR_MICROBLAZE_0_ICACHE_STREAMS 0
#define XPAR_MICROBLAZE_0_ICACHE_VICTIMS 0
#define XPAR_MICROBLAZE_0_IC_AXI_MON 0
#define XPAR_MICROBLAZE_0_ILL_OPCODE_EXCEPTION 0
#define XPAR_MICROBLAZE_0_IMPRECISE_EXCEPTIONS 0
#define XPAR_MICROBLAZE_0_INSTR_SIZE 32
#define XPAR_MICROBLAZE_0_INTERCONNECT 2
#define XPAR_MICROBLAZE_0_INTERRUPT_IS_EDGE 0
#define XPAR_MICROBLAZE_0_INTERRUPT_MON 0
#define XPAR_MICROBLAZE_0_IP_AXI_MON 0
#define XPAR_MICROBLAZE_0_I_AXI 0
#define XPAR_MICROBLAZE_0_I_LMB 1
#define XPAR_MICROBLAZE_0_I_LMB_MON 0
#define XPAR_MICROBLAZE_0_I_LMB_PROTOCOL 0
#define XPAR_MICROBLAZE_0_LMB_DATA_SIZE 32
#define XPAR_MICROBLAZE_0_LOCKSTEP_MASTER 0
#define XPAR_MICROBLAZE_0_LOCKSTEP_SELECT 0
#define XPAR_MICROBLAZE_0_LOCKSTEP_SLAVE 0
#define XPAR_MICROBLAZE_0_M0_AXIS_DATA_WIDTH 32
#define XPAR_MICROBLAZE_0_M0_AXIS_PROTOCOL GENERIC
#define XPAR_MICROBLAZE_0_M1_AXIS_DATA_WIDTH 32
#define XPAR_MICROBLAZE_0_M1_AXIS_PROTOCOL GENERIC
#define XPAR_MICROBLAZE_0_M2_AXIS_DATA_WIDTH 32
#define XPAR_MICROBLAZE_0_M2_AXIS_PROTOCOL GENERIC
#define XPAR_MICROBLAZE_0_M3_AXIS_DATA_WIDTH 32
#define XPAR_MICROBLAZE_0_M3_AXIS_PROTOCOL GENERIC
#define XPAR_MICROBLAZE_0_M4_AXIS_DATA_WIDTH 32
#define XPAR_MICROBLAZE_0_M4_AXIS_PROTOCOL GENERIC
#define XPAR_MICROBLAZE_0_M5_AXIS_DATA_WIDTH 32
#define XPAR_MICROBLAZE_0_M5_AXIS_PROTOCOL GENERIC
#define XPAR_MICROBLAZE_0_M6_AXIS_DATA_WIDTH 32
#define XPAR_MICROBLAZE_0_M6_AXIS_PROTOCOL GENERIC
#define XPAR_MICROBLAZE_0_M7_AXIS_DATA_WIDTH 32
#define XPAR_MICROBLAZE_0_M7_AXIS_PROTOCOL GENERIC
#define XPAR_MICROBLAZE_0_M8_AXIS_DATA_WIDTH 32
#define XPAR_MICROBLAZE_0_M8_AXIS_PROTOCOL GENERIC
#define XPAR_MICROBLAZE_0_M9_AXIS_DATA_WIDTH 32
#define XPAR_MICROBLAZE_0_M9_AXIS_PROTOCOL GENERIC
#define XPAR_MICROBLAZE_0_M10_AXIS_DATA_WIDTH 32
#define XPAR_MICROBLAZE_0_M10_AXIS_PROTOCOL GENERIC
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

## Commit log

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2021-10-31 Added a sheet containing all of the required current drivers to the interface board
    [current_drivers.sch, driver.sch, sense_amps.sch]
2021-10-31 Driver board: added strand selection and return circuits
    [current_drivers.sch, driver.sch, fpga_power.sch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]
2021-11-02 Driver board: added a preliminary sheet for the FPGA connector and interfacing circuitry
    [current_drivers.sch, driver.sch, fpga_power.sch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]
2021-11-03 Driver boards: filled out all of the FPGA connections. Power circuits to still be defined.
    [driver.sch, fpga_power.sch, strand_select_return.sch]
2021-11-08 Completely overhauled rope driver circuitry to much, much more closely resemble the original.
    [current_drivers.sch, driver.kicad_pcb, driver.sch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]
2021-11-09 Driver board: a bit more schematic work and some initial footprint selections
    [driver.kicad_pcb, filtered_0v.sch, fpga_power.sch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]
2021-11-11 Driver board: finished first rough draft schematic. Lots of placeholders, but at least every place is held.
    [connector.sch, driver.kicad_pcb, driver.sch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]
2021-11-14 Driver board: fleshed out the hotswap controller, tweaked some resistors, and added some bypass caps
    [filtered_0v.sch, filtered_14v.sch, fpga_power.sch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]
2021-11-16 Driver board: significant cleanup. Moved sense amp pairs into a subsheet, split tuning resistors into two globally, pushed input circuits into their corresponding sheets.
    [connector.sch, driver.kicad_pcb, driver.sch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]
2021-11-18 Backplane board: new name, and initial integration of DIN-41612 3x32 C connector
    [backplane_blk2.kicad_pcb, backplane_blk2.sch, interface_blk2.kicad_pcb]
2021-11-18 Driver board: integrated DIN 41612 backplane connector, and made a dedicated parity inhibit sheet with a different set resistor value.
    [connector.sch, driver.kicad_pcb, filtered_0v.sch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]
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2021-12-13 Firmware: initial framework for interrupt-driven UART comms. Circularly-buffered variable-length slipped transmission works; reception next.
    [main.c, uart.c]
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2022-02-13 Added a simplified test driver board, for proof-of-concept testing with a 2-bit, 2-strand, 2-core rope
    [driver_test.kicad_pcb, driver_test.kicad_sch, filtered_0v.kicad_sch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]
2022-02-14 Driver: Added a 5V->3.3V LDO to replace the reversed cmod header, added jumpers for the 200R parallel returns, and renamed subcircuit ports to avoid unexpected ground connections.
    [connector.kicad_sch, driver.kicad_sch, filtered_0v.kicad_sch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]
2022-02-15 Driver: some high-level board rearrangement and addition of 3d models
    [driver_test.kicad_pcb, driver_test.kicad_sch, filtered_14v.kicad_sch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]
2022-02-24 Driver test: completed much of the preliminary layout.
    [driver_test.kicad_pcb, driver_test.kicad_sch, filtered_14v.kicad_sch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]
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2022-03-08 Gerber files for v1 of the driver test board
    [driver_test-B_Cu.gbl, driver_test-B_Mask.gbs, driver_test-B_Silkscreen.gbo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]
2022-03-08 Driver test: some updates to component values based on new documentation
    [driver_test.kicad_pcb, driver_test.kicad_sch, fpga_power.kicad_sch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]
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2022-03-27 Added a simple test rope board to implement a test 2-bit, 2-strand, 2-core rope compatible with the driver test board
    [test_rope-B_Cu.gbl, test_rope-B_Mask.gbs, test_rope-B_Silkscreen.gbo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]
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2022-04-03 Driver test: updated schematic with new coarse tuning resistance values for all 3 current driver types
    [driver_test.kicad_sch, filtered_14v.kicad_sch, inhibit.kicad_sch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]
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2022-04-06 Driver test: dropped BPLSSW LED brightness by bumping its resistor up to 1k
    [driver_test.kicad_sch, fpga_power.kicad_sch, inhibit.kicad_sch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]
2022-04-06 FPGA: Corrected polarity of inhibit driver enables
2022-05-22 Backplane-BLK2: Footprints laid out and preliminary sense routing
    [backplane_blk2.kicad_pcb, backplane_blk2.kicad_sch]
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2022-06-02 Added STEP files and mechanical drawings for the chassis
    [connector_plate.step, cover.step, rail.step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]
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2022-06-17 Driver: positioned the sense amps and laid out all of the sense wires
    [driver.kicad_pcb]
2022-06-19 Driver: lightly reorganized FPGA wiring to make it easier to change in the future, and fixed sense amp mapping
    [fpga_power.kicad_sch, sense_amps.kicad_sch]
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2022-06-21 Driver: 3.3V section is now laid out, contained entirely beneath the FPGA daughter board
    [driver.kicad_pcb, fpga_power.kicad_sch, return.kicad_sch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]
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2022-06-30 Driver: incorporated completed backplane pinout and did a little bit more routing on the board
    [connector.kicad_sch, driver.kicad_sch, sense_amps.kicad_sch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]
2022-07-03 Driver: Completed preliminary placement on the top layer. <200 unwired nets to go.
    [fpga_power.kicad_sch]
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2022-07-10 Driver: a bit more routing work. May revisit 3.3V logic placement to ease contention around the FPGA
    [fpga_power.kicad_sch]
2022-07-11 Driver: almost totally rearranged 3.3V logic section. The ratsnest is now significantly detangled, and the FPGA routing is almost done. 89 nets left.
    [fpga_power.kicad_sch, sense_amp_pair.kicad_sch]
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2022-07-18 Driver: routed a few more signals and annotated net equivalent names for the rope connector
    [connector.kicad_sch]
2022-07-23 Driver: completed first pass layout. All nets routed, 0 DRC errors.
2022-07-24 Driver: added ground pours to all layers and corrected orientations of all refdes
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2022-08-08 Driver: minor schematic cleanup and populated all of the BOM except for resistors
    [connector.kicad_sch, driver.kicad_sch, filtered_0v.kicad_sch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]
2022-08-08 Driver: filled out the rest of the BOM, except for defaults for nominal resistances
    [driver.kicad_sch, filtered_0v.kicad_sch, fpga_power.kicad_sch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]
2022-08-09 Driver: completed the BOM and added some reference dimensions to the board layout
    [driver.kicad_sch, inhibit.kicad_sch, set_reset.kicad_sch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]
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2022-08-13 GUI: Fixed FF banksum determination
    [agc.py, main_window.py]
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2022-08-14 Driver: corrected reference divider resistor and added diode direction symbols to the silkscreen
    [connector.kicad_sch, driver.kicad_sch, fpga_power.kicad_sch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]
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2022-08-20 Driver: increased pours clearance to 20 mils, removed ground pours from outer layers, adjusted thermal reliefs, and adjusted some plane outlines
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2023-09-16 Firmware: add support for sensing Block I ropes during both set and reset, in case of multiple diode failure
    [rope.c]
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2024-04-28 Rework USB interface to enable unplugging and replugging without restarting GUI
    [control_window.py, main_window.py, measurements.py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]
2024-07-06 Allow scope capture to adjust timing and strobe during both set and reset
    [control_window.py, main_window.py, scope_window.py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]
